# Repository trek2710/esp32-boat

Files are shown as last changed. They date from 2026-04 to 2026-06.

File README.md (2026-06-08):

# esp32-boat

A family of small, **independent, self-contained boat devices**. Each device
is one ESP32-based box that does a single job on its own — own sensors, own
display, own settings — and connects only to a companion **iOS app over BLE**.
No shared bus, no boat network required.

> **v2 (2026-06).** This reverses the original design — three ESP peers on a
> WiFi "virtual N2K bus" — which was abandoned in the pivot to independent BLE
> devices ([ADR-0016](docs/adr/0016-independent-devices-over-ble.md)). The full
> v1 design is recoverable at the `v1-wifi-bus-archive` tag; its docs are in
> [docs/archive/](docs/archive/).

## Device 1 — AIS-radar

A **Waveshare ESP32-S3-Touch-AMOLED-1.75-G** (onboard LC76G GNSS) + a **Wegmatt
dAISy 2+** AIS receiver, battery-powered:

```
   VHF antenna ─► dAISy 2+ ──UART(IO16)──► AMOLED device ──BLE──► iPhone (AisRadar app)
                                              │  - decode AIVDM
   LC76G GNSS ───────onboard──────────────────┤  - own position
                                              │  - radar on the AMOLED
                                              └  - threat colouring
```

It decodes AIS targets from the dAISy, takes own position from the LC76G (or
the phone's GPS), and draws the targets **radar-style** on its round AMOLED —
with a whole-screen threat colour (dark → green → yellow → red). The iOS app
mirrors the same radar over BLE.

**Status:** working end-to-end on the bench/phone. See
[docs/ROADMAP.md](docs/ROADMAP.md). Remaining hardware steps: solder the LC76G
`R15`/`R16` jumpers (real own GPS) and connect the VHF antenna (real targets).

## Repo layout

```
esp32-boat/
├── devices/
│   └── ais-radar/            device 1 — its own PlatformIO project
│       ├── platformio.ini
│       └── src/              main, Radar, Ble, glue
├── shared/                   salvaged, reusable across devices
│   ├── ais/                  AIVDM decode + AisTargetDecoder + target store
│   ├── display/              AMOLED panel + LVGL + TCA9554 + LC76G GPS + touch
│   └── ble/                  GATT wire contracts (AisRadarBle.h)
├── ios/                      AisRadar — SwiftUI BLE-central app
├── docs/                     CONTEXT.md (glossary), ROADMAP.md, adr/, hardware/
├── scripts/                  gen_ais_test.py, patch helpers
└── docs/archive/             v1 docs (superseded by ADR-0016)
```

## Build + flash (device)

Each device is its own PlatformIO project:

```bash
cd devices/ais-radar
pio run                                    # build
pio run -t upload --upload-port /dev/cu.usbmodemXXXX   # flash
```

The AMOLED's native USB-CDC needs the `--no-stub` + `115200` upload flags
already set in its `platformio.ini`.

## iOS app

`ios/` is the **AisRadar** SwiftUI app — a CoreBluetooth central that connects
to the `ais-radar` device, decodes its notify characteristics
([shared/ble/AisRadarBle.h](shared/ble/AisRadarBle.h)), and draws its own
radar with a tunable scale. Build:

```bash
cd ios
xcodegen generate
open AisRadar.xcodeproj      # run on a real iPhone — BLE needs hardware
```

## Bench testing

`scripts/gen_ais_test.py` generates verified Type-18 AIS sentences (correct
checksums, round-trip-decoded) placed around a centre point, labelled with the
threat colour each one triggers. Inject them via the dAISy `T` menu.

## Docs

- [docs/CONTEXT.md](docs/CONTEXT.md) — glossary / domain language.
- [docs/ROADMAP.md](docs/ROADMAP.md) — what's done + what's next.
- [docs/adr/](docs/adr/) — architecture decisions (ADR-0016 is the v2 pivot).
- [docs/hardware/ais_radar_wiring.html](docs/hardware/ais_radar_wiring.html) — device wiring + power.

## License

MIT — see [LICENSE](LICENSE).

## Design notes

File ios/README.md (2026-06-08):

# AisRadar — iOS app (v2, ADR-0016)

A SwiftUI **BLE-central** app for the `ais-radar` device. It scans for the
device, subscribes to its two notify characteristics, decodes own-ship +
AIS targets (wire contract: `../shared/ble/AisRadarBle.h`), and draws its
own north-up radar with a tunable / auto-fit scale.

This replaces the archived v1 WiFi-bus app (recoverable at tag
`v1-wifi-bus-archive-ios`).

## Build

```sh
cd ios
xcodegen generate        # regenerate AisRadar.xcodeproj (brew install xcodegen)
open AisRadar.xcodeproj  # then run on a real iPhone (BLE needs hardware)
```

`.xcodeproj` is gitignored — `project.yml` is canonical.

## Layout

- `Sources/AisRadar/BleCentral.swift` — CoreBluetooth central (scan / connect / subscribe).
- `Sources/AisRadar/RadarModel.swift` — decoded model + little-endian byte readers.
- `Sources/AisRadar/RadarView.swift` — the radar Canvas.
- `Sources/AisRadar/ContentView.swift` — radar + scale controls + status.

## Status

Connects, decodes `BleOwnShip` / `BleTarget`, draws the radar. **Pending:**
the settings write path (iOS → device), once the device exposes it.

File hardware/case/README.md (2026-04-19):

# 3D-printable enclosure

Two-part round case for the Waveshare ESP32-S3-Touch-LCD-2.1 + SN65HVD230
transceiver. Designed around the nominal dimensions of both boards — re-run
`generate_case.py` with different parameters if your hardware measures
differently.

## Files

| File | What it is |
|---|---|
| `case_body.stl` | The main bowl. Holds the transceiver at the back, the Waveshare PCB in front of it. |
| `case_bezel.stl` | Flat ring with the display window. Press-fits into the top of the body. |
| `generate_case.py` | Parametric source that produced the STLs. All dimensions are constants at the top of the file. |

## Dimensions

- Outer diameter: **Ø75 mm**
- Total height (body + bezel): **25 mm** (21 mm body + 4 mm bezel, ~2 mm overlap)
- Display window: **Ø55.9 mm** (clears the 2.1" / Ø53.4 mm active area)
- USB-C slot: 12 × 6 mm on the +X side wall, centred at z ≈ 12.9 mm
- NMEA 2000 cable exit: Ø6 mm hole through the -X side wall, in the transceiver bay

The inside has an **internal shelf** that the PCB rests on, so the display
sits flush with the bezel opening.

## Print settings

- **Material**: PETG (marine environment, UV & humidity) or PLA for bench use.
- **Orientation**:
  - *Body* — open end up, back wall on the build plate. No supports needed;
    slicers will bridge the internal shelf and side holes fine at ≤6 mm.
  - *Bezel* — flat side down. No supports.
- **Layer height**: 0.2 mm. 0.16 mm if you want the tick marks around the
  display to look nice.
- **Walls**: 3 perimeters (≥1.2 mm) — the wall-min is 2.5 mm everywhere so
  even default settings give you solid walls.
- **Infill**: 20 % is plenty; the case is tiny.
- **Support**: only needed if your printer bridges the horizontal USB-C slot
  and cable hole badly. Try without first.

## Assembly

1. Drop the **SN65HVD230** breakout into the Ø60 mm transceiver bay at the
   back. Secure with a dab of hot glue or double-sided tape (there's a
   generous 6 mm of depth to play with).
2. Route the CAN twisted pair + 12 V / GND through the **Ø6 mm cable exit
   hole** in the side wall. A small rubber grommet or a dab of silicone
   keeps water out.
3. Insert the **Waveshare ESP32-S3-Touch-LCD-2.1** into the PCB cavity,
   display facing up. The back of the PCB rests on the internal shelf; the
   cavity is 1.5 mm oversize so the board slides in with a little slop.
4. Verify **USB-C** on the Waveshare board lines up with the side slot.
   If it doesn't, rotate the PCB 90°/180° — the USB connector's exact
   clock position is defined by how you orient the PCB inside the round
   cavity. (If the slot is off-axis when the PCB is aligned the way you
   want for the screen, re-run `generate_case.py` with `USB_CUTOUT_Z`
   adjusted.)
5. Press the **bezel** onto the top. The skirt (Ø66.2 mm) slides 2 mm into
   the top rim (Ø66.5 mm) — light interference fit. Push firmly until the
   bezel flat meets the top of the body.

If you ever need to get back in, a thin knife or guitar pick in the seam
between bezel and body will pop it off without damage.

## Regenerating the STLs

You need `manifold3d` and `numpy-stl`. On macOS with Homebrew Python:

```
pip3 install --break-system-packages manifold3d numpy-stl
```

Then:

```
cd hardware/case
python3 generate_case.py
```

That rewrites `case_body.stl` and `case_bezel.stl` next to the script.
Edit the constants at the top of the `.py` file to change dimensions.

## TODO for a future revision

- Mounting tabs or magnets for attaching to a bulkhead.
- O-ring groove in the bezel-body seam for full IP65.
- Recess on the back for a wall-mount screw or VESA pattern.
- Light pipe / gasket around the display edge for a cleaner look.

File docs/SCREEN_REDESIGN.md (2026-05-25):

# Screen redesign — round 85

Round-85 grilling pinned the page layout for the three displays. This
file is the implementation brief; the protocol decisions it depends on
are in [ADR-0013](adr/0013-settings-control-plane.md).

## LCD page set (both `lcd-gps` and `lcd-2.1` identical)

Four pages, swipe-cycled left/right:

| # | Page | What it shows |
|---|---|---|
| 1 | **Main** | Compass overview (existing) |
| 2 | **AIS** | Compass overlay (if own-GPS fix) **or** scrollable list (if no fix) |
| 3 | **PGN** | 19-tile honeycomb (existing) |
| 4 | **Comm** | Two columns — Network (left) / Hardware (right) |

Removed entirely: the standalone **Wind** overview page (Main covers
it), the **Sim** channel-mask page (moved to iOS), the **Settings**
no-go-zone page (moved to iOS).

### Main page — only change

Flip the apparent-wind cone (`main_pg.twd_arrow`, the long yellow
slim cone) so the **thick end points outward**. Today it points
inward (cone narrows toward the rim). Same colour, same length, same
binding to `s.awa`.

Code location: `src/Ui.cpp` around `buildMainPage()` line ~1265 where
`lv_meter_add_needle_img` is called for the cone, plus the static
`needle` image asset definition. Either flip the image data
horizontally or invert the value-to-angle mapping; the latter is
fewer changes.

### AIS page — new on the LCDs

Two layouts, chosen at refresh time by checking
`BoatState::hasGpsFix()`:

**With GPS fix — compass overlay.** Same outer-ring compass as Main.
For every AIS target passing the filters (see ADR-0013 keys
`ais.range_nm` / `ais.hide_anchored` / `ais.stale_s`):

- Compute bearing-from-own-ship and range using
  `navmath::greatCircleBearing` and `navmath::greatCircleDistance`.
- Draw a small triangle on the compass at the bearing, with a stroke
  thickness proportional to `1 / range` (closer = thicker).
- Above the boat-speed centre group, add a 3-line "nearest 3" panel
  with NAME · RNG · BRG.

**Without GPS fix — list.** Plain scrollable list (LVGL `lv_list` or
a tall flex column). Columns: NAME (left, ellipsised at 12 chars),
TYPE (3-letter, like the converter's), SOG, CPA-or-`—`. Sort by
last_seen descending so freshly-heard targets appear at the top.
Range/bearing columns are blank because we have no own-ship position.

### PGN page — unchanged

Keep the existing 19-tile honeycomb. The grey reserved slots
(ENG-T / OIL-T / HEEL / PITCH / ROT / RUD) stay as visual placeholders
for future hardware.

### Comm page — two-column rewrite

Mockup:

```
WiFi : STA  ap=lcd-2.1     GPS  : 3D fix  8 sats  age 2s
IP   : 192.168.4.2         Power: 4.18V batt  USB 5.04V (chrg)
RSSI : -42 dBm  ch 1       Up   : 1h 23m 47s
peers: 2
```

Column widths roughly equal; left column = `Network`, right column =
`Hardware`. Drops the legacy BLE notify counters that survive in
`comm_pg` today. TX's current `Primary` page content (GPS, AXP2101,
uptime) folds in here; TX no longer has a standalone Primary page.

LVGL: implement once in `src/Ui.cpp`'s `buildCommPage` /
`refreshComm`, then port the equivalent (Arduino_GFX-rendered) onto
TX in `src_tx/main.cpp`.

### Page count

RX is currently `kNumPages = 6`. New value: `4` (and the `#ifdef`
that switched between 5 and 6 in the BLE/WiFi backends becomes
unconditional 4).

TX is currently `kNumPages = 5`. New value: `4`.

The swipe state machine in both envs is already page-count agnostic
(`(current_page + step + kNumPages) % kNumPages`).

## Converter screen — layout unchanged

Apply only the three AIS filters from the global settings snapshot
(ADR-0013):

- `ais.range_nm`        — hide targets farther than N NM (with default 12 NM, but the converter currently defaults its list at infinite range; settings override at runtime)
- `ais.hide_anchored`   — drop NavStatus ∈ {1, 5, 6} when true
- `ais.stale_s`         — drop targets whose `last_seen` is older than N seconds

These filters short-circuit the existing 4-row list builder in
`src_converter/Ui.cpp`'s `refreshTargets()` (a single `passes_filters`
helper called before each row is emitted).

No graphical changes to the converter UI: boat icon, DAISY badge,
ship-type colour palette, header, footer all stay as they are.

## Settings UI — lives on iOS

See [IOS_APP.md](IOS_APP.md). No Settings page on the LCDs in v1.

## Implementation order

Suggested punch-list, smallest blocks first:

1. **AWA cone flip** on Main — single-file change, instantly visible.
   Bench-test by watching the cone rotate as the simulator wind angle
   moves; thick end should now poke through the outer ring's bow zone.
2. **Comm page two-column rewrite** on RX. New layout, new fields.
   Don't yet drop the BLE counters (they go away when the BLE env
   does, which is independent of this work).
3. **Drop Settings + Wind + Sim pages** from RX. Update `kNumPages`,
   `pages[]` index array, `case n` blocks. Verify swipe still cycles
   correctly.
4. **AIS page on RX** (list layout first, since GPS isn't yet wired —
   step-5 hardware is still pending). Use the AisTargetStore as the
   source; the store doesn't currently live on RX — fan-out from the
   converter's replay (ADR-0012) populates it via the existing PGN
   dispatch path. Verify by triggering a sim AIS injection from the
   converter and watching it land on RX's list.
5. **AIS page compass overlay** — gated on `hasGpsFix()`. Implements
   the GPS path; works on the bench by setting a sim lat/lon on RX so
   `hasGpsFix()` returns true.
6. **Converter AIS filters.** Wire the three filter keys through the
   `refreshTargets` short-circuit. Defaults bake in if no settings
   snapshot has arrived yet.
7. **TX pages, mirror of RX.** Port the four pages onto Arduino_GFX
   for TX. Same content, different renderer.

Steps 1–6 are doable independently. Step 7 depends on the others
landing first so the TX port has a stable target to copy.

## What this is not

- This brief does not implement ADR-0013 (HTTP server, heartbeat
  snapshot, NVS cache). Those are prerequisites for the Settings UI
  to *do anything*, but the page-layout work in steps 1–7 above is
  independent of them — the no-go-zone read happens whether or not
  the snapshot mechanism is in place (fallback to compile-time
  default).
- It does not touch the BLE envs. `[env:nmea2k_tx]` and
  `[env:waveshare_esp32s3_touch_lcd_21_ble]` stay as-is; only the
  `_wifi` envs evolve.

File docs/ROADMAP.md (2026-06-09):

# Roadmap

> **v2 pivot (2026-06-07, ADR-0016):** the project abandoned the WiFi
> "virtual bus" / NMEA 2000 mirror entirely and became a family of
> **independent, self-contained devices** that link to an iOS companion
> over BLE. **Everything below the "v2 — independent devices" section is
> v1 history**, kept for reference and recoverable at the
> `v1-wifi-bus-archive` tag, but no longer the plan.

## v2 — independent devices over BLE ← CURRENT DIRECTION

**Goal: self-contained ESP boxes, each doing one boat job standalone,
each linked only to an iOS companion over BLE.** No shared bus, no boat
network required. Architecture: [ADR-0016](adr/0016-independent-devices-over-ble.md);
vocabulary: [CONTEXT.md](CONTEXT.md).

### Device 1 — AIS-radar device (milestone 1)

The ESP32-S3-Touch-AMOLED-1.75-G (onboard LC76G GPS) + a Daisy 2+ AIS
receiver, drawing AIS targets radar-style on its own AMOLED when it has
a fix, with a BLE link to a fresh iOS app. Self-powered.

**Salvage (keep):** AMOLED display/touch/PMIC bring-up, LC76G GPS
driver, AIS AIVDM decode (now `shared/ais/`), radar geometry/trig.
**Re-target:** the radar is an LVGL→LVGL port — both boards run LVGL
8.3.11 (the AMOLED uses Arduino_GFX only as LVGL's flush backend), so
re-aim the canvas + screen size, not a graphics-API rewrite. iOS app →
fresh, BLE central. **Drop:** WiFi bus, role election, HTTP settings.

- [x] **0. Repo reset — DONE.** Tag `v1-wifi-bus-archive`; `devices/` +
      `shared/` layout. Salvaged (all hardware-verified on the AMOLED
      board): `shared/ais/` (AIVDM decode + de-N2K'd, lat/lon-fixing
      `AisTargetDecoder`), `shared/display/` (`AmoledDisplay` panel+LVGL,
      `Tca9554` expander, `Lc76gGps` UART NMEA — dead I2C path dropped,
      streams once R15/R16 soldered, `Touch` CST9217 via SensorLib),
      `shared/ble/BoatBle.h`. `devices/ais-radar/` builds + runs:
      display + touch + GPS + AIS all live on the board. Deleted `src/`
      `src_tx/` `src_converter/` `include/` + the root `platformio.ini`
      (recoverable at the tag); CI now builds the device.
- [ ] **1. AMOLED + GPS bring-up** — display/touch up on the new tree;
      LC76G UART jumpers (R15/R16) soldered; own position acquired.
- [x] **2. Daisy AIS in — DONE.** Wiring:
      [ais_radar_wiring](../hardware/ais_radar_wiring.html) (3 wires off
      header H2 — `IO16`←TXD, `3V3`→VCC@3.3V, `GND`; no step-up, no 9V).
      Firmware reads the Daisy on `Serial2`/`IO16` @ 38400, assembles
      lines, and feeds the on-device `AisTargetDecoder`. Hardware-verified:
      the Daisy keep-alive heartbeat decodes clean (valid checksum) on the
      AMOLED. (A position-type sentence or a real antenna is needed before
      a vessel shows — the keep-alive is AIS type 15.)
- [x] **3. On-device radar — DONE.** North-up LVGL PPI on the AMOLED
      (`Radar.cpp`): own ship centred, AIS targets at range/bearing with
      5-min COG projection sticks, MMSI labels, range rings, auto-fit
      range, stale-contact dimming. Own position pinned to a bench
      coord until the LC76G is soldered; targets expire after 10 s
      (`evictStale(10000)`). Verified Type-18 test sentences:
      `scripts/gen_ais_test.py`. (Touch zoom/pan is a later polish.)
- [~] **4. BLE link** — device side DONE: advertises as `ais-radar`
      (`shared/ble/AisRadarBle.h` wire contract; `devices/ais-radar/Ble.cpp`
      NimBLE peripheral), notifies own-ship (`BleOwnShip`) + each AIS target
      (`BleTarget`) once per second to a connected central. **Pending:** the
      iOS-→-device settings write characteristic + NVS persistence.
- [x] **5. Fresh iOS app — DONE.** `AisRadar` SwiftUI BLE-central app:
      scans for `ais-radar`, subscribes to both characteristics, decodes
      `BleOwnShip`/`BleTarget`, draws its own north-up radar with auto-fit
      + a manual range slider. Replaces the archived v1 WiFi app under
      `ios/`. **Confirmed live on the iPhone** — targets sent via the
      dAISy show up on the phone radar. (Settings write path iOS → device
      still pending.)

**Acceptance:** powered by its own battery/powerbank, no boat
connection, the device shows my GPS position with live AIS targets
around it radar-style; the iOS app mirrors it and can change its
settings.

### Later devices / capabilities (not scheduled)

- Comfort device (IMU sea-state → comfort index) — design in
  [ADR-0014](adr/0014-comfort-page-sea-state.md), **mechanism needs BLE
  rework** (it predates this pivot).
- Optional per-device **N2K bridging** — a device gains an SN65HVD230 to
  emit/read PGNs. The v1 encoders + ADR-0005 are kept dormant for this.
- Fate of the RX 2.1" round display and the C6 converter as future
  devices.
- **AIS-radar polish (deferred):** radar **range/scale tuning** from iOS
  (keep or replace autoscale — decide once the app is live); a **C-MAP map
  overlay** read from the onboard microSD (`cmap/` folder) — an *overlay
  on the radar only*, explicitly **not** a mapping engine; and the AMOLED
  **swipe/touch** interaction (undecided — possibly just swipe).
  **SD recon done** (firmware `listSdCard()`): SD is **SD_MMC** on
  `CLK=2 / CMD=1 / DATA=3` (1-bit). exFAT doesn't mount on stock
  Arduino-ESP32 → card reformatted **FAT32** (60 GB), now mounts fine.
  The charts are **CM93 v2/v3** (`cm93_World2014/` → numeric cell dirs ×
  `A`–`G` scale bands × `.INF`), **not** encrypted C-MAP — so it's
  decodable (OpenCPN's `cm93` plugin is the reference implementation), but
  the overlay is a substantial **vector decode + render** job (decode the
  cell geometry for the own-ship area at an appropriate scale band → draw
  coastlines/land as a radar overlay). A real feature, not a quick add.
- **Weather/chart "mapping" device (idea, future):** a separate device that
  shows C-MAP base charts + **GRIB** weather overlays, reading both from the
  same microSD layout (exFAT; `cmap/` + a GRIB file already on the card).
  Distinct from the AIS-radar device's overlay-only use of the card.

---

# v1 history (archived — WiFi virtual bus, superseded by ADR-0016)

Everything below predates the v2 pivot. Recoverable at
`v1-wifi-bus-archive`.

## Sea-trial v1 — standalone AIS + GPS pod (SUPERSEDED by ADR-0016)

**Goal: a self-powered box that shows real AIS + iPhone-GPS position on
the RX and iOS, on a boat with no instruments and no NMEA 2000.** The
test boat has no N2K backbone and no wind instrument, so this release
drops the "mirror a real bus" premise entirely. Rationale + the four
scoping decisions: [ADR-0015](adr/0015-standalone-pod-first.md).
"Standalone pod" deployment mode: [CONTEXT.md](CONTEXT.md).

**In scope:** iPhone GPS (foreground) for own position; real AIS via the
Daisy 2+ → converter → virtual bus; the RX radar + AIS list; the iOS map
+ list. Self-powered (LCD batteries, converter on a powerbank).

**Deferred:** comfort/IMU (ADR-0014), a dedicated GPS module, wind /
depth / heading sensors, the N2K **gateway mode**.

**Priorities (do roughly in order):**

- [ ] **1. Simulator master switch** — one `sim.master` setting gates
      *all* sim publishing (RX sim + converter AIS sim). Bench = on
      (today's behaviour); trial = one tap off so only real sources
      flow. Prevents `sim.gps` from pegging own-ship in Copenhagen.
- [ ] **2. Heading honesty** — there is no magnetometer; own-ship is
      COG-only (valid when moving). Ensure no display implies a magnetic
      bow heading; label it COG, not HDG.
- [ ] **3. Field power-on autonomy** — the three boards + iPhone form
      the virtual bus on battery alone, no laptop: RX comes up as AP
      reliably, converter + iPhone join, iOS app foreground.
- [ ] **4. Real AIS bring-up** — wire the Daisy 2+ to the converter
      (`docs/hardware/hardware_guide.html`), powerbank it, verify real
      targets travel Daisy → converter → bus → RX radar + iOS.
- [ ] **5. Real-position verification** — `sim.master` off, confirm the
      RX radar + iOS map centre on the live iPhone position with real
      AIS targets around it.

**Acceptance:** underway on the real boat, battery-powered, no laptop —
the RX radar and the iOS map show my real position with live AIS targets
around me for a full short sail.

## v0 — scaffold (this repo as-is, 2026-04-19)

- [x] PlatformIO project structure
- [x] NMEA 2000 + LVGL dependencies pinned
- [x] Placeholder instrument screens
- [x] CI builds the firmware on every push
- [ ] Flash on real hardware when it arrives
- [ ] Confirm display pin assignments against the Waveshare schematic
- [ ] Confirm CAN TX/RX pin choice against the broken-out header

## v1 — instruments only (single board, target: hardware in hand + 2 weekends)

**Goal: a working cockpit instrument that shows live NMEA 2000 data.**

- [x] Display driver stable (no tearing, touch responsive)
- [x] PGN 129025 / 129026 / 129029 → GPS position + SOG + COG
- [x] PGN 130306 → wind (apparent + true)
- [x] PGN 128267 + 130316 → depth + water temperature
- [x] PGN 127250 + 128259 → heading + speed through water
- [ ] PGN 129038 / 129039 → AIS position reports → scrolling target list
- [x] Swipe / tap to page between screens
- [ ] Brightness control (long-press a corner)
- [ ] Persist last screen across reboots
- [ ] Mechanical install in the cockpit
- [ ] Retire the bench harness after 1 weekend of sea trial without crashes

## v1.5 — wireless split (in progress)

**Goal: move from one all-in-one board to two BLE-bridged boards.**

The receiver stays in the cockpit; a new transmitter board lives near
the NMEA 2000 backbone (wiring locker / engine bay) and forwards data
over BLE GATT. The SN65HVD230 transceiver moves off the RX onto the
new TX board. The simulator follows it, so sim and real PGNs flow
through the same wireless link.

- [x] **Step 1a** — PIO `[env:nmea2k_tx]`, src_tx scaffold, serial-only
      Hello on the Waveshare ESP32-S3-Touch-AMOLED-1.75-G
- [x] **Step 1b** — AXP2101 PMIC init via XPowersLib (SDA=GPIO15 /
      SCL=GPIO14), full I²C bus census, live battery / VBUS telemetry
- [x] **Step 1c** — SH8601 AMOLED brought up over QSPI via Arduino_GFX
      (CO5300 driver, which is pin-compatible), LVGL 8.3.11 bound via
      a flush callback into a 466×466 PSRAM buffer, centred
      "Hello, transmitter" label rendering
- [x] **Step 2** — `include/BoatBle.h` shared wire protocol —
      service UUID + 5 notify characteristics (Wind / GPS / Heading /
      Depth-Temp / Attitude) + 1 command characteristic. All PDUs
      packed, fit inside the default 23-byte ATT MTU, valid-mask
      bitmap per channel so missing fields are explicit instead of
      sentinel-encoded.
- [x] **Step 3** — TX runs the simulator + acts as BLE peripheral
      (`esp32-boat-tx`), notifying boat-state on the five channels
      at NMEA-2000 spec cadences. Subscribed counts visible on the
      TX's Communication page; verified subscribable from nRF Connect.
- [x] **Step 4** — RX-side BLE central scans for the service UUID,
      auto-connects to the first `esp32-boat-tx` it sees, subscribes
      to all five characteristics, parses PDUs into existing BoatState
      setters. On disconnect `BoatState::invalidateLiveData()` blanks
      all live fields to NaN so the UI renders "—" instead of stale
      values. Status getters expose link state / peer MAC / RSSI /
      per-channel notify counters, shown on a new RX Communication
      page (page 6 under `DATA_SOURCE_BLE`). New PIO env
      `[env:waveshare_esp32s3_touch_lcd_21_ble]` gates the central
      backend on `-DDATA_SOURCE_BLE=1`.
- [ ] **Step 5** — TX wired to NMEA 2000 bus through SN65HVD230,
      NMEA2000 + NMEA2000_esp32_twai libraries forward real PGNs
      onto the same notify path. **Hardware-blocked** until the
      transceiver is wired and the bus has a live source. See
      [OPENPLOTTER_NMEA2000.md](OPENPLOTTER_NMEA2000.md) for the
      OpenPlotter-as-source bring-up path.
- [ ] **Step 6** — RX → TX command channel: page-3 sim toggles fire
      writes back to the TX. Wire format reserved in `BoatBle.h`,
      `CommandCallbacks::onWrite` in `src_tx/main.cpp` logs bytes
      but doesn't decode yet. Deferred until step 5 lands.
- [x] **Step 7** — TX status display on the AMOLED, five pages
      (Primary, Simulator, PGN, Settings, Communication) with
      BLE link state, per-channel notify rate, AXP2101 telemetry,
      uptime. Read-only — Sim toggles surface state but don't yet
      flip mask (waits on step 6).
- [x] **Step 7b** — CST9217 capacitive touch via lewisxhe/SensorLib;
      swipe-left / swipe-right gestures change pages. Reset line
      driven via TCA9554 EXIO6 (CST9217 RST isn't on a direct GPIO
      on this board). SensorLib upstream has a `getPoint(0)` bounds
      bug that spams the log on every touch; patched in-place at
      build time by `scripts/patch_sensorlib.py` (idempotent,
      self-healing across libdeps wipes).
- [—] **Step 8** — Real GPS via the AMOLED-1.75-G's onboard LC76G.
      **Dead-end on this board variant.** I²C path against 0x50
      ACKs writes but NACKs reads (Quectel's app note is paid).
      UART path via GPIO17/18 stays silent — the R15/R16 0 Ω
      jumpers between LC76G TX/RX and the ESP32 pins aren't
      populated. Driver code is parked in place: I²C poll
      auto-disables itself after N consecutive NACKs, UART drain
      runs every loop iteration so soldering R15/R16 lights it up
      with no code change. Will revisit if an external GPS
      becomes attractive.
- [x] **Step 9** — TX UI polish: titles 28pt, rows 24pt, Sim page
      six category-coloured pills (display-only — interactive
      toggling lives on step 6), PGN page rows tinted by category
      pastel to mirror the RX honeycomb's colour-coding. A
      tap-to-toggle experiment was tried and reverted — the tap
      detection added a 300 ms lockout that interfered with swipes,
      so toggle UX waits for step 6.

## v1.5b — screen cleanup (round 85, **shipped**)

**Goal: unified 4-page LCD layout, AIS on the LCDs, drop the
half-finished pages.** Brief in [SCREEN_REDESIGN.md](SCREEN_REDESIGN.md).

- [x] **Step 1** — Flip the Main-page AWA cone so the thick end
      points outward instead of inward.
- [x] **Step 2** — Comm page rewritten as two columns (Network /
      Hardware), absorbing TX's previous Primary content.
- [x] **Step 3** — Settings / Wind-overview / Simulator pages dropped
      from RX. `kNumPages = 4`, swipe order: Main / AIS / PGN / Comm.
- [x] **Step 4** — AIS list page on RX (sorted by last-seen; renders
      from `BoatState::aisSnapshot()`).
- [x] **Step 5** — GPS-aware AIS list: when own-GPS fix is present,
      list sorts by range ascending and populates RNG / BRG columns
      via inline haversine. (Full canvas-based compass overlay
      deferred — the list path delivers the user-meaningful info.)
- [x] **Step 6** — Converter AIS filters (`ais.range_nm` /
      `ais.hide_anchored` / `ais.stale_s`) wired into
      `refreshTargets()`.
- [x] **Step 7** — TX page set converged to 4 pages (Main / AIS /
      PGN / Comm). TX now consumes incoming bus PGNs into a local
      `BoatState` (round-85 step-7-fix) and renders real values; AIS
      list mirrors RX's; Comm page is two-column.

## v1.6 — iOS companion app + settings control plane (round 85, **mostly shipped**)

**Goal: native SwiftUI app that joins the bus as a full peer and
becomes the canonical settings UI.** Design in
[IOS_APP.md](IOS_APP.md); settings control plane in
[ADR-0013](adr/0013-settings-control-plane.md).

- [x] **Step 1** — Settings control plane on the firmware: AP-side
      `WebServer` on port 80 with `GET`/`POST /settings`, heartbeat
      snapshot fan-out, NVS persistence on every ESP. Consumers wired
      for: `nav.no_go_deg` (RX Main), `sim.*` channel toggles (RX
      simulator), `ais.hide_anchored` + `ais.stale_s` (converter
      filter), `ui.brightness` (converter backlight).
- [x] **Step 2** — Xcode project (`../esp32-boat-ios/`) scaffolded
      with xcodegen, 4-tab SwiftUI shell, UDP listener + heartbeat
      publisher + PGN dispatcher all wired. Captive-portal stub on the
      AP (DNS hairpin + iOS probe URLs) so iOS classifies
      `_wifi_nmea2k` as a real network and doesn't fall back to
      cellular.
- [x] **Step 3** — Boat tab (live instrument grid + TWA/TWS/VMG
      derived locally + per-channel staleness sweep blanks cells when
      a channel goes silent).
- [x] **Step 4** — AIS tab (placeholder; populated by converter's
      AIS-sim replay over the bus). Plus: iPhone GPS publisher
      (PGN 129025, **opt-in default off**, toggle on Settings tab,
      stored in UserDefaults). Plus: Boat-tab Position cell with
      cross-check of bus-published GPS against iPhone GPS — bold
      orange when delta > 30 m.
- [x] **Step 5** — Own-ship SOG/COG available everywhere via local
      derivation from successive PGN 129025 fixes (firmware `BoatState`
      round 56; iOS `PgnDispatch.handleGps`). Per-target SOG/COG
      already rides PGN 129039 from the converter. A 129026 wire-up
      across peers was **declined**: it would contradict the round-56
      "derive, don't trust a sensor-supplied COG/SOG" rule (RX already
      ignores 129026) and add nothing the map needs.
- [ ] **Step 6** — AIS map view: SwiftUI Canvas with own ship +
      AIS targets + 5-minute forward-projection arrows. **Unblocked**
      — all inputs (own-ship position/heading/SOG/COG, per-target
      position/SOG/COG) are on the bus today. Plus Diagnostics tab
      polish (PGN-rate honeycomb, raw-log drawer).

## v1.7 — future polish (not yet planned)

- Real boat connectivity: SN65HVD230 to a live N2K backbone (v1.5
  step 5, hardware-blocked; see
  [OPENPLOTTER_NMEA2000.md](OPENPLOTTER_NMEA2000.md)).
- LC76G GPS via the AMOLED-1.75-G's onboard GNSS — requires
  soldering R15/R16 jumpers.
- TX compass widget on Main (currently text grid; RX has the full
  LVGL compass).
- iOS distribution signing ($99/yr Apple Developer Program) — the
  free-tier signing requires online cert verification at each launch.
- Wi-Fi role-priority surfacing in heartbeat (`has_transceiver`
  bool, task #45) — meaningful once multiple transceiver peers exist
  on the same physical N2K backbone.

## v2 — waypoint navigation

- [ ] Waypoint list (load/save JSON on the microSD card)
- [ ] "Go to" screen: bearing + distance + cross-track error to active WP
- [ ] Receive active waypoint from a chartplotter via PGN 129284 if present
- [ ] Send local waypoints onto the bus (PGN 129285) so they show on the chartplotter

## v3 — map

- [ ] Pre-render OSM tiles to microSD offline
- [ ] Tile cache + pan/zoom on the round display
- [ ] Boat icon heading-up, lat/lon from GPS
- [ ] AIS targets as icons on the map, not just a list

## v4 — polish

- [ ] OTA updates over WiFi (marina / phone hotspot)
- [ ] Anchor watch: alarm if the boat drifts > X metres from a dropped pin
- [ ] Trip log: miles, hours, max SOG, max wind — exported as CSV on the SD

## v5 — comfort / seakeeping (design only, not scheduled)

**Goal: a comfort page driven by the boats' idle QMI8658 IMUs.**
Architecture pinned in [ADR-0014](adr/0014-comfort-page-sea-state.md)
and the "Comfort / sea state" glossary in [CONTEXT.md](CONTEXT.md);
no implementation yet. In short: reconstruct a (boat-distorted) sea
state from each LCD's IMU, correct it with a learned per-boat model
held in the iOS app, and show a steepness-based comfort index — with
the active source (cockpit-measured / locker-measured / manual / GFS
forecast) user-selectable. See the ADR's "Open questions" for what's
still undecided.

## Non-goals

- Being a replacement for a full MFD. We are a single-purpose instrument.
- Writing **NMEA 2000 control commands** onto the boat bus (autopilot,
  engine, etc.). The bus-side stays read-only. The BLE command channel
  (RX → TX) is internal — it only configures the TX (sim toggles, future
  brightness, etc.), it never reaches the boat's N2K backbone.
- ~~Supporting boats without an NMEA 2000 backbone.~~ **Reversed
  (2026-05-26, ADR-0015):** the first sea-trial boat has no N2K backbone,
  so the **standalone pod** deployment mode (iPhone GPS + Daisy AIS + IMU,
  no boat connection) is now a first-class target. The N2K **gateway
  mode** remains supported for boats that do have a backbone.

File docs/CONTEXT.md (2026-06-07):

# esp32-boat — glossary

This project is a family of **independent, self-contained devices**. Each
device is one ESP-based box that does a single boat-related job on its
own — own sensors, own display, own persisted settings — and can
optionally be observed and configured by an **iOS companion** over
Bluetooth Low Energy. There is no shared bus and no coordination between
devices; each is an island.

This reverses the v1 design (a WiFi "virtual bus" mirroring a boat's
NMEA 2000 network). The pivot and what it retires: **ADR-0016**. The
retired bus vocabulary is listed at the bottom so old code/commit
references still resolve.

## Language

**Device**:
A self-contained ESP box that performs one boat-related job standalone.
It owns its inputs (e.g. GPS, AIS), renders its own result on its own
display, and persists its own **device-local settings** in NVS so it
works with no phone present. A device may optionally connect to the
**iOS companion** over BLE. Devices do **not** talk to each other.
_Avoid_: "peer" (there is no bus to be a peer on), "node", "board" when
you mean the logical device (a device is one board today, but the term
is about its role, not its silicon).

**AIS-radar device**:
The first device. A Waveshare ESP32-S3-Touch-AMOLED-1.75-G (onboard
LC76G GNSS) wired to a Wegmatt Daisy 2+ AIS receiver. It decodes AIS
targets from the Daisy's serial feed, takes own position from the
LC76G, and draws the targets **radar-style** (own ship centred, targets
by range/bearing) on its AMOLED — when it has a GPS fix. Self-powered,
needs no boat connection.
_Avoid_: "converter" (the v1 C6 converter bridged AIS→N2K; this device
shows AIS, it doesn't bridge), "RX/TX" (those were bus roles).

**iOS companion**:
The iOS app, acting as a BLE **central** that connects to a device
(the device is the **peripheral**). It observes the device's live data
(AIS targets, own GPS, status) and is the **only** way to change a
device's settings. One companion observes one device at a time; pairing
multiple devices is a future concern.
_Avoid_: "iOS peer" / "iOS-app peer" (bus-era term), "hub" in a
networking sense (it is a viewer + the settings writer, not a relay).

**Device-local settings**:
A device's configuration (e.g. radar range, AIS filters, brightness),
stored in the device's NVS. The device runs on its stored settings
standalone and ships with sane defaults, so it works out of the box with
no phone ever paired. Settings can be **changed only from the iOS
companion** over BLE — there is exactly one writer, so no sync conflict,
and the device needs no on-screen settings UI (its touchscreen is for
radar interaction only).
_Avoid_: "control plane" (the v1 HTTP-on-AP mechanism is gone),
"settings snapshot" (no heartbeat carries it).

**N2K bridging** (future, per-device):
Any device *may* later gain an SN65HVD230 transceiver and emit its data
onto a real NMEA 2000 backbone — and read from it where it makes sense.
This is an optional add-on to a given device, not the system's purpose.
The v1 NMEA 0183-AIS → N2K encoders and the strict-`src` mirror rule
(ADR-0005) are kept dormant as reference for when this is wanted.
_Avoid_: treating N2K as the target (it is no longer); "transceiver
peer" (bus-era term).

## Comfort / sea state (planned feature)

Vocabulary for a planned **comfort** device/page. Pinned before
implementation. **Note:** the original design (ADR-0014) assumed the v1
WiFi bus and an iOS-republish step that no longer exist; under the
device model a comfort capability is just another self-contained device
(or a page on one) that BLEs to the companion. The *terms* below stand;
the *mechanism* in ADR-0014 needs reworking for BLE.

**Sea state**:
The wave field around the boat, expressed as a **wave height** + a
**wave period**. No sensor here measures it directly, so a sea state is
always an *estimate*, a *manual observation*, or a *forecast* — never
ground truth. Carries the two numbers only; the felt result is the
**comfort index**.

**Comfort index**:
The user-facing output: a band (calm / moderate / rough / dangerous)
derived from a sea state's *steepness* — wave height against wavelength,
wavelength from the period (deep water: L ≈ 1.56·T²). The "wave height
vs period" relationship is the point: the same height is comfortable at
long period and dangerous at short period.
_Avoid_: "comfort ratio" (Brewer's static hull constant — different
thing).

**Boat-response model**:
The learned filter relating the true sea state to the motion an IMU
actually feels. Under the device model it would live in the iOS
companion (per boat) and the device would apply or receive it over BLE
— not "republish onto a bus" as ADR-0014 originally said.

## Retired vocabulary (v1 WiFi-bus era — see ADR-0016)

These describe the abandoned shared-bus architecture. Listed so old
commits, code comments, and ADRs 0001–0015 still resolve. **None
describe current behaviour.**

- **Virtual bus** — the WiFi distribution of N2K-style PGN packets.
  Gone: devices are islands, no shared transport.
- **AP / role election / elected writer** — the dynamic WiFi access-
  point + priority handoff (ADR-0009/0010). Gone: no multi-peer network.
- **Peer / off-bus peer / transceiver peer** — members of the virtual
  bus. Gone: replaced by **device** (+ future per-device **N2K
  bridging**).
- **Mirror direction / virtual-to-real direction** — the v1 real-N2K ↔
  virtual-bus forwarding (ADR-0005). Dormant: relevant again only under
  future **N2K bridging**.
- **Control plane / settings snapshot** — HTTP-on-AP settings write +
  heartbeat-embedded settings fan-out (ADR-0013). Gone: replaced by
  **device-local settings** written over BLE.
- **AIS replay** — periodic re-emit of the AIS cache onto the bus for
  late joiners (ADR-0012). Reworked: the iOS companion reads the
  device's current AIS target store on BLE connect instead.
- **Standalone pod / gateway mode** — the ADR-0015 deployment split.
  Subsumed: "standalone" is now the whole model (every device is
  standalone); "gateway" is the future per-device **N2K bridging**.

## Flagged ambiguities (historical)

- "bus" meant both the physical N2K backbone and the WiFi side —
  resolved in v1 (virtual vs real). Now moot: there is no WiFi bus.
- "Bridge ESP" / "allow-list" / "proxy-write" / "multicast group" —
  all retired during v1 (ADR-0010/0011/0012).
- The entire v1 bus model is retired by ADR-0016; see the list above.

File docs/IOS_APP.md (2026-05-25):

# iOS companion app — design brief + status

This is the spec for the **iOS app**, a SwiftUI sub-project that joins
the virtual N2K bus as a full peer and serves as the canonical
settings UI for the boat instruments. The repo lives at
`../esp32-boat-ios/` (sibling to the firmware repo).

## Status (round 85, 2026-05-25)

**Shipped (v1.6 step 2–4):** xcodegen project, 4-tab SwiftUI shell, UDP
listener, heartbeat publisher with `kind:'ios-app'`/priority 80,
settings POST/GET against the AP's HTTP server, AIS list, per-channel
staleness sweep, derived TWA/TWS/VMG, iPhone GPS publisher (opt-in,
default off), Position cross-check with bold-orange warning at > 30 m
delta vs bus GPS, SOG/COG derived locally from GPS position deltas.

**Pending (v1.6 step 6):** AIS map view (own ship + targets +
5-minute forward-projection arrows), Diagnostics tab polish
(PGN-rate honeycomb, raw-log drawer). Map inputs are all on the
bus already — a 129026 wire-up was declined in favour of local
SOG/COG derivation (see ROADMAP v1.6 step 5).

## Role on the bus

The iOS app is a **full peer** on the virtual N2K bus, identical in
protocol shape to the three ESP peers (`lcd-gps`, `lcd-2.1`,
`nmea-converter`):

| Property | Value |
|---|---|
| `kBoardPeerName` | `ios-app` |
| `kBoardKindName` | `ios-app` |
| `kBoardPriority` | 80 (lower than TX=100; never becomes AP) |
| Transport | WiFi STA, joins `_wifi_nmea2k` with WPA2-PSK |
| Heartbeat | PGN 65500, 5-second cadence, same JSON shape |
| Reads | Every instrument PGN — full mirror of `BoatState` |
| Writes | Settings via HTTP POST to AP (ADR-0013); optional PGN 129025 GPS publish (opt-in, default off) |

Because the priority is 80 and iOS can't act as a softAP, iOS never
runs the AP role. The role-election protocol (ADR-0009) handles this
naturally — iOS always advertises `role:'STA'` in its heartbeat and
the existing tiebreak never selects it.

## Platform

Native Swift + SwiftUI, Xcode project, iOS 17+.

- Networking: `Network.framework` (`NWConnection`) for the UDP
  receive socket. `URLSession` for the HTTP write path.
- Persistence: `UserDefaults` for last-known settings snapshot and
  paired-WiFi metadata; `SwiftData` if a future "log" feature wants
  history.
- Background: foreground-only in v1. iOS aggressively suspends
  background sockets, and the boat use case is "phone is out, in
  hand"; pushing this into background mode is a separate hardening
  pass.
- Distribution: TestFlight → App Store. Bundle ID
  `com.koefoed.esp32boat` (placeholder).

A future Android app would be a separate native Kotlin project
sharing only the [VIRTUAL_BUS_WIRE.md](VIRTUAL_BUS_WIRE.md) contract
plus ADR-0013.

## Tab layout

Four tabs in a `TabView`, each a `NavigationStack`:

```
┌──────────────────────────────┐
│ <Tab content>                │
│                              │
│                              │
│                              │
└──────────────────────────────┘
│  Boat  │  AIS  │ Set │ Diag  │
└──────────────────────────────┘
```

### Tab 1: Boat (instrument dashboard)

Live mirror of the main instruments — port of the LCDs' Main page
plus more verbose readouts that the round display can't fit:

- Big compass widget (SwiftUI `Canvas`, same wedge / no-go-zone /
  AWA-cone treatment as RX's main page).
- TWA / TWS / AWA / AWS / TWD as a 2×2 grid below the compass.
- BSP / SOG / STW / Heading / Depth / Heel as a 2×3 grid.
- Position (lat/lon) at the bottom; tap to copy to clipboard.
- Pull-to-refresh forces re-subscribe to the AP (debug affordance).

No interactivity in v1 — read-only.

### Tab 2: AIS

Full target list (no row limit, unlike the LCDs' 4-row converter
screen). Columns: NAME · TYPE · RNG · BRG · SOG · CPA. Tap a row to
push a detail view showing:

- Full vessel name + MMSI + call sign
- Ship type + nav status (decoded to English)
- Live: SOG, COG, heading
- Last known position + last_seen age
- Apple Maps link with the position

Filters are global (ADR-0013 `ais.*` keys) — the AIS tab reflects
whatever the settings snapshot says. A bar at the top lets the user
*temporarily* widen the filter for this session (e.g. show moored
ships in a marina) without changing the global setting.

### Tab 3: Settings

The whole reason the app exists. Edits push to
`POST http://192.168.4.1/settings` and wait for `200`. The UI shows
the AP's current `settings_v` in the nav-bar title so the user knows
when their edit lands.

Sections:

- **Simulator** — toggle row per `sim.*` key. Disabled grey when no
  AP is reachable.
- **Display** — `ui.brightness` slider (0–100), `ui.idle_dim_after_s`
  picker (30s / 1m / 5m / 15m / never).
- **Navigation** — `nav.no_go_deg` stepper (20–60° in 5° steps).
- **AIS filters** — `ais.range_nm` slider (1–48 NM), `ais.hide_anchored`
  toggle, `ais.stale_s` picker (1m / 5m / 10m / 30m / 1h).
- **About** — app version, paired SSID, current AP peer name.

### Tab 4: Diagnostics

Read-only. The "look at the bus" view that today lives on the LCDs'
Comm + PGN pages.

- **Peers** — list rows for every peer in the AP's negotiator table:
  name, kind, priority, role, last-seen age. iOS's own entry at the
  top, dimmed.
- **WiFi** — SSID, BSSID of the AP we're on, channel, RSSI, this
  device's IP.
- **PGN rates** — same 19-tile honeycomb concept but rendered as a
  list (rate per PGN, sparkline). Wider than the LCD layout because
  there's no round-screen constraint.
- **Raw log** — toggle-on developer drawer that tails the most recent
  N JSON PDUs the app has received. Useful when debugging a new
  setting key or a malformed peer.

## Connection lifecycle

```
launch
  ├─ load cached settings snapshot from UserDefaults
  └─ start NWPathMonitor
       ├─ on path satisfied + WiFi SSID == _wifi_nmea2k
       │    open UDP listener on kBusPort
       │    start 5-s heartbeat publisher
       │    GET http://192.168.4.1/settings on first connect
       └─ on path lost or SSID changed
            close UDP listener
            stop heartbeat
            mark UI as "offline" (greys + last-known timestamp)
```

The app uses `WiFi association == bus join`. There is no "pair"
flow — the user joins the WiFi network from iOS Settings the normal
way (one-time, password from
[wifi_credentials.md](../../.claude/projects/...)) and the app
just lights up when the SSID is right.

## Things explicitly out of scope (v1)

- iOS publishing instrument PGNs back to the bus, beyond the opt-in
  phone-GPS source (PGN 129025) shipped in step 4. Any further
  iOS-sourced PGNs (e.g. phone heading/IMU) stay reserved for v2.
- iOS as the AP. Can't happen on iOS — no softAP API.
- Push notifications (AIS proximity alert, no-go-zone alarm, low
  battery). v2+.
- Per-peer settings overrides. ADR-0013 explicitly chose all-global;
  any future per-peer config would require schema rev.
- Background-mode operation. v1 is foreground-only.

## See also

- [ADR-0013 — Settings control plane](adr/0013-settings-control-plane.md)
- [ADR-0001 — WiFi not BLE](adr/0001-wifi-not-ble.md)
- [SCREEN_REDESIGN.md](SCREEN_REDESIGN.md) — the LCD changes that
  triggered the iOS app's existence
- [CONTEXT.md](CONTEXT.md) — glossary, including new `iOS-app peer`
  entry
- [VIRTUAL_BUS_WIRE.md](VIRTUAL_BUS_WIRE.md) — wire format the iOS
  app speaks

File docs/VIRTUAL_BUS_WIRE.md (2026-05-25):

# Virtual N2K Bus — Wire Specification

This document is the contract between the three firmware envs in this
repo — the TX board (`nmea2k_tx_wifi`), the RX board (`..._wifi`),
the AIS converter (`nmea_converter`, which decodes AIS today and will
bridge to a physical N2K bus once its SN65HVD230 is wired) — and a
planned **iOS companion app**.

Authoritative architectural decisions live in `docs/adr/0001-0008.md`.
This file pins the implementation details those ADRs leave open:
exact JSON shape, PGN numbers, field names, units, cadences, and
credentials. The converter env must match this document; the TX is
the first-mover publisher.

## Transport

- **Group:** `239.255.78.85` (administratively-scoped IPv4 multicast).
- **Port:** `60001` (UDP).
- **TTL:** `1` (boat-LAN scope; do not let multicast leak past an AP).
- **MTU budget:** stay under 1024 bytes per packet. One PGN per packet.

## Network

- SoftAP `_wifi_nmea2k` / WPA2-PSK + CCMP-only / `showmetrust`. See
  `~/.claude/projects/-Users-jeppekoefoed-Documents-Claude-Projects-esp32-boat/memory/wifi_credentials.md`.
- Role election (round 83 / ADR-0009): every ESP32 peer runs the same
  protocol on boot. Priority-weighted backoff (RX:0s, converter:4s,
  TX:8s), then a 2 s WiFi scan. If SSID is up → join as STA; if not →
  become AP. A higher-priority peer that arrives later takes over via
  polite handoff (`takeover_announce` + `going_down`, ~5–10 s outage).

## Packet shape

One JSON object per UDP packet, no framing, no terminator. UTF-8.

```json
{
  "pgn": 130306,
  "src": 255,
  "peer": "esp32-boat-tx",
  "fields": {
    "sid": 7,
    "windSpeed": 5.34,
    "windAngle": 2.117,
    "reference": "Apparent"
  }
}
```

- `pgn` *(uint16, required)* — the N2K PGN number this packet represents.
- `src` *(uint8, required)* — always `255` for off-bus peers (the N2K
  "unclaimed/null device" sentinel). Bridge ESPs in the mirror direction
  pass the real device's claimed src through here. See ADR-0005.
- `peer` *(string, required)* — application-level identity of the
  publisher: `"esp32-boat-tx"`, `"esp32-boat-rx"`, `"nmea-converter"`,
  `"ios-app"`. Subscribers may dedupe or filter on this.
- `fields` *(object, required)* — per-PGN payload, naming and units
  per the CANboat JSON convention.

### Unit conventions (CANboat-aligned)

- **Angles:** radians (degrees × π / 180). Range `-π…π` for relative,
  `0…2π` for compass-style absolute. The receiver converts to degrees
  for display.
- **Speeds:** metres per second. (1 knot = 0.514444 m/s.)
- **Distances:** metres.
- **Temperatures:** Kelvin. (°C + 273.15.)
- **Lat/lon:** decimal degrees as IEEE-754 double. ±90 / ±180.
- **Strings used for enums** (e.g. `"True"` / `"Magnetic"` /
  `"Apparent"`) — never raw integer codes.

### SID

The `sid` field is the per-PGN sequence ID that ties together
related PGNs (e.g. position-rapid + COG/SOG-rapid sharing the same SID
mean they describe the same instant). It's a `uint8` that wraps at
253; values 254/255 are CANboat "null". Publishers increment per
*publish event*, not per PGN — so one wind publish that emits a True
and an Apparent packet uses the same SID for both.

## PGN map (esp32-boat publish set)

Mapping from the existing `include/BoatBle.h` PDUs into individual
PGN packets. Each row is one UDP packet; the TX may emit several rows
per simulator tick.

### Wind — from `WindPdu`

| Bits set in `valid_mask` | PGN | fields |
|---|---|---|
| bit 1 (TWS) AND bit 0 (TWA) | 130306  | `sid`, `windSpeed` (m/s), `windAngle` (rad, relative), `reference: "True"` |
| bit 1 (TWS) AND bit 2 (TWD) | 130306  | `sid`, `windSpeed` (m/s), `windAngle` (rad, compass abs), `reference: "True (ground referenced to North)"` |
| bit 4 (AWS) AND bit 3 (AWA) | 130306  | `sid`, `windSpeed` (m/s), `windAngle` (rad, relative), `reference: "Apparent"` |

Note: if both TWA and TWD are present, emit both — they're distinct
true-wind references.

### GPS — from `GpsPdu`

| Bits set | PGN | fields |
|---|---|---|
| bit 0 (LAT) AND bit 1 (LON) | 129025 | `latitude` (deg), `longitude` (deg) |
| bit 2 (COG) AND bit 3 (SOG) | 129026 | `sid`, `cogReference: "True"`, `cog` (rad), `sog` (m/s) |

### Heading + boat speed — from `HeadingPdu`

| Bits set | PGN | fields |
|---|---|---|
| bit 0 (HDG) | 127250 | `sid`, `heading` (rad), `reference: "Magnetic"` |
| bit 1 (BSPD) | 128259 | `sid`, `speedWaterReferenced` (m/s), `speedWaterReferencedType: "Paddle wheel"` |

(Heading reference defaults to `Magnetic` because that's what the
simulator and most compasses produce. If a true-heading source ever
joins, it gets a separate row with `reference: "True"`.)

### Depth + temperatures — from `DepthTempPdu`

| Bits set | PGN | fields |
|---|---|---|
| bit 0 (DEP) | 128267 | `sid`, `depth` (m), `offset: 0.0` |
| bit 1 (AIR-T) | 130316 | `sid`, `instance: 0`, `source: "Outside Temperature"`, `actualTemperature` (K) |
| bit 2 (SEA-T) | 130316 | `sid`, `instance: 1`, `source: "Sea Temperature"`, `actualTemperature` (K) |

### Attitude + engine — from `AttitudePdu`

| Bits set | PGN | fields |
|---|---|---|
| bit 0 (HEEL) AND/OR bit 1 (PITCH) | 127257 | `sid`, `yaw: null`, `pitch` (rad), `roll` (rad) |
| bit 2 (ROT) | 127251 | `sid`, `rate` (rad/s) |
| bit 3 (RUD) | 127245 | `sid`, `instance: 0`, `position` (rad), `directionOrder: "No Order"`  |
| bit 4 (ENG-T) | 127489 | `sid`, `instance: 0`, `engineCoolantTemperature` (K) |
| bit 5 (OIL-T) | 127489 | `sid`, `instance: 0`, `engineOilTemperature` (K) |

Missing values: send `null` (JSON literal) rather than the field, so
subscribers can tell "unknown" from "zero". CANboat does this for
fields a PGN doesn't carry; we follow suit.

## Cadences

The TX publishes at the existing BLE cadences (which match N2K spec
rates) — see `src_tx/main.cpp` Step-7 globals for the canonical
numbers. Summary:

| PDU | Publish period |
|---|---|
| Wind | 100 ms (10 Hz) |
| GPS | 100 ms |
| Heading | 100 ms |
| Depth | 1 s |
| Sea temp | 2 s |
| Air temp | 2 s |
| Attitude | 100 ms |

Plus a **30-second republish** per channel: even if no new sample
arrived, re-emit the last known value. This is the late-joiner
catch-up mechanism from ADR-0006. The republish reuses the most
recent SID rather than minting a new one — same data, same SID.

## Receive side

The RX joins the multicast group, parses each packet, dispatches by
`pgn`, and calls the matching `BoatState` setter. PGN handlers are a
small switch in `src/NmeaBridge.cpp` (the `DATA_SOURCE_WIFI` branch),
mirroring what the production `tNMEA2000` path does on a real bus.

Lossiness is acceptable — UDP plus the 30 s republish bounds time to
populated state. The honeycomb's "dim" colour is the correct visual
response to a brief multicast drop; no special-case logic required.

## Versioning

If a PGN field name or unit ever changes, bump the multicast port
(`60001` → `60002`). Old subscribers stop seeing traffic (clean
failure) rather than silently misinterpreting fields.

## Control PGN — heartbeat / role election

PGN 65500 (N2K manufacturer-proprietary single-frame range) carries
the role-election control messages. Same wire format as data PGNs,
emitted by every peer every 5 s on the multicast group:

```json
{
  "pgn": 65500,
  "src": 255,
  "peer": "esp32-boat-rx",
  "fields": {
    "event":     "heartbeat",          // or takeover_announce / going_down
    "kind":      "RX",                 // TX / RX / converter / iOS
    "priority":  200,
    "role":      "AP",                 // AP / STA / electing
    "ap_ip":     "192.168.4.1",
    "uptime_ms": 123456
  }
}
```

Subscribers track a peer table (peer name → kind/priority/role/last-
seen) and use it to drive election + handoff decisions. See
`docs/adr/0009-wifi-role-election.md` for the full protocol.

## Cross-firmware obligations

The `nmea_converter` env (round 83 — partial):
- ✅ Participates in role election via PGN 65500 heartbeats.
- ⏳ AIS PGN multicast publish (129038/129039/etc.) — deferred to a
  follow-up round. Requires intercepting `tNMEA2000::SendMsg()` via
  a subclass of `NMEA2000_esp32_twai`.
- ✅ Honours the same 30 s republish rule for state it owns.

The iOS app must:
- Be subscribe-only initially. Publishing requires the proxy-write
  allow-list path on a Bridge ESP, which doesn't exist yet.

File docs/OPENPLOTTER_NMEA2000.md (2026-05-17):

# OpenPlotter as the NMEA 2000 source

A standalone briefing for a future agent / future-me picking up the
**step 5 bring-up**: connecting the esp32-boat TX board to a real
NMEA 2000 backbone and proving that real PGNs flow end-to-end into
the RX. Hardware is in hand but the bus has no live sensors yet, so
OpenPlotter is being used to inject the traffic.

This is its own context — read it in a fresh session that doesn't
need to carry the BLE bridge / LVGL UI / firmware-architecture work
in head.

## What this is solving

The TX firmware compiles and runs the simulator over BLE today. To
prove the production path, we need real PGNs hitting the
SN65HVD230 → ESP32-S3 TWAI path. The boat has no installed sensors
(wind transducer, depth, etc.) yet, so the only available source of
real bus traffic is OpenPlotter on a Raspberry Pi acting as a
sender. Once that loop closes (OpenPlotter → backbone → TX → BLE →
RX → display), step 5 is done and we can move on to physical sensor
install when those parts arrive.

## What hardware is on hand

- **NMEA 2000 backbone cable + drop cable + power tap.** Standard
  Micro-C connectors. Both end terminators present (assume yes; if
  the user is unsure, multimeter across CAN-H/L should read ~60 Ω
  with the bus de-energised — that's two 120 Ω terminators in
  parallel).
- **No sensors connected to the backbone yet.** Bus is electrically
  alive once powered but carries no PGN traffic.
- **OpenPlotter setup on a Raspberry Pi.** Software stack — Signal K
  server, kplex, OpenCPN, etc. Pi model unknown; assume Pi 4 or
  newer with USB ports available.
- **The esp32-boat TX board** (Waveshare ESP32-S3-Touch-AMOLED-1.75-G,
  USB-C powered for bench testing).
- **SN65HVD230 CAN transceiver module** (3.3 V native, see
  [BOM.md](BOM.md)). Not yet wired to anything; TX-side pins to use
  are picked in step 5 of [ROADMAP.md](ROADMAP.md) (not yet committed
  to specific GPIOs — TWAI on the S3 is flexible).
- **The esp32-boat RX board** (Waveshare ESP32-S3-Touch-LCD-2.1),
  already flashed with the `_ble` env and known to subscribe to the
  TX over BLE.

## What hardware is NOT yet on hand (likely)

- A USB-to-NMEA-2000 gateway for the Pi. OpenPlotter does **not**
  natively emit NMEA 2000 over the air; it speaks Signal K
  internally, NMEA 0183 trivially, and N2K only via specific
  hardware gateways. This is the most likely missing piece.
  Candidates:
  - **Actisense NGT-1** — gold standard, ~€350, well-supported by
    canboat and Signal K.
  - **Yacht Devices YDNU-02** — about half the price, similar
    feature set, USB.
  - **canable.io / candleLight USB-to-CAN adapter** + canboat's
    `n2k-can-receiver` / `actisense-serial` style driver. Cheapest
    path (~€30), but more software setup; the kernel needs the
    `gs_usb` driver and the user must configure SocketCAN
    (`ip link set can0 up type can bitrate 250000`).
  - **PiCAN2 / PiCAN-M HAT** — directly mounts on the Pi GPIO
    header, exposes CAN as `can0` via SocketCAN. The "-M" variant
    has the Micro-C cabling on the HAT itself, removing a level
    of pigtail. ~€60–€80.

  Confirm with the user which (if any) of these they have or want
  to buy before designing the integration further.

## How OpenPlotter emits NMEA 2000

The pipeline OpenPlotter exposes:

```
boat sensors (NMEA 0183, NMEA 2000, I²C, USB GPS, etc.)
        ↓
   Signal K server (the heart of OpenPlotter — normalises everything
                    to its internal data model)
        ↓
   output plugins
        ├── signalk-to-nmea0183 → NMEA 0183 stream
        ├── signalk-to-nmea2000 → calls a CAN backend (canboat /
        │                          SocketCAN) to write PGNs
        └── signalk-server-node native PGN out (if installed)
        ↓
   USB N2K gateway / CAN HAT
        ↓
   NMEA 2000 backbone
```

The `signalk-to-nmea2000` plugin is the one we care about. It maps
Signal K paths (e.g. `environment.wind.speedApparent`) to specific
PGN encoders inside canboat (`actisense-serial` for NGT-1-style
gateways; SocketCAN for HAT-style or canable). Defaults cover the
common PGNs — wind, heading, GPS, depth, water temp — which is
exactly the set we already decode.

There's also `signalk-to-canboat` and the `n2kanalyzer` family of
tools — same idea, different glue. The user has used OpenPlotter
before (their phrasing: "may be able to get it to output NMEA 2K"),
so they likely have at least Signal K running.

## Open questions to resolve in the first session

Ask the user, in roughly this order:

1. **What hardware connects the Pi to the bus today?** None, USB
   gateway (which model?), or CAN HAT (which model?). Determines
   100% of the rest.
2. **What's already running on OpenPlotter?** Signal K server up?
   Any data sources configured? Any sample / synthetic data
   plugins installed?
3. **Does the user want OpenPlotter to inject *simulated* sensor
   data**, or are they planning to feed it from a NMEA 0183 source
   (e.g. an old chartplotter) that gets converted up to NMEA 2000?
   The former is faster to set up; the latter is closer to real-
   boat conditions.
4. **What's the physical layout?** Does the Pi sit next to the TX
   and the backbone, or is one of them remote? Affects whether
   we're testing on a bench (everything on a desk) or partially
   installed.

## Suggested first session structure

1. **Verify the bus is alive.** Power the backbone (~12 V on the
   red/black pair). Multimeter across CAN-H/L: ~60 Ω with bus
   off, ~2.5 V on both with bus on. If either reading is wrong,
   stop and diagnose cabling before doing anything else.
2. **Get the Pi onto the bus.** Install + configure the chosen
   gateway/HAT. For SocketCAN-based paths:
   ```bash
   sudo ip link set can0 up type can bitrate 250000
   candump can0    # should show nothing yet — empty bus
   ```
   For Actisense-style USB gateways:
   ```bash
   actisense-serial -s 115200 /dev/ttyUSB0 | analyzer
   ```
3. **Get Signal K outputting PGNs.** Install the
   `signalk-to-nmea2000` plugin via the Signal K admin UI. Enable
   the PGNs the esp32-boat decodes (129025 GPS position, 129026
   COG/SOG, 130306 Wind, 128267 Depth, 130316 Sea/Air Temp,
   127250 Heading, 128259 STW). Use a Signal K synthetic data
   plugin (e.g. `signalk-fake-data`) or hand-injected values via
   the admin UI to drive them with known numbers.
4. **Verify PGNs on the wire.** `candump can0 | grep <PGN>` (after
   converting PGN to CAN-ID range — canboat's `analyzer` tool
   does this nicely). Confirm each PGN is being emitted at its
   spec cadence.
5. **Wire the TX into the backbone.** Use a T-piece + drop cable
   to the SN65HVD230. CAN-H/CAN-L on the bus pair, 12 V → TX 5 V
   buck, GND common. **Check terminator first** — most factory
   modules ship with a 120 Ω terminator soldered on, and a third
   terminator on an already-terminated bus pulls the impedance
   too low. Remove if present.
6. **Bring up the TX with `-DSIMULATED_DATA=0`.** Currently the
   TX env has the simulator wired in via `simulateTick()`. Step
   5 will introduce a new build flag that swaps the simulator
   for `NMEA2000.ParseMessages()` calls feeding the same
   `BoatState` setters. The handlers already exist in
   `src/NmeaBridge.cpp` (RX side) — most of the work is
   porting / mirroring them on the TX so they call the existing
   BLE publishers instead of UI setters.
7. **Verify end-to-end.** RX should show the Signal K-injected
   values on the existing UI (Main page wind compass, depth
   readout, etc.). Per-channel notify counters on the TX
   Communication page should climb at the Signal K cadence,
   not the simulator cadence.

## Key references

- canboat — https://github.com/canboat/canboat — the de-facto PGN
  encoder/decoder library; underpins almost every open-source
  N2K project.
- Signal K — https://signalk.org/ — data model docs explain what
  Signal K *paths* map to which N2K *PGNs*.
- `signalk-to-nmea2000` plugin —
  https://github.com/SignalK/signalk-to-nmea2000 — the actual
  PGN-out source on the Pi side.
- ttlappalainen/NMEA2000_esp32_twai —
  https://github.com/ttlappalainen/NMEA2000_esp32_twai — the
  library the TX firmware will use to read PGNs off the
  transceiver. Use this fork (not the ESP32-classic NMEA2000_esp32)
  on the ESP32-S3 — it uses the TWAI peripheral, which is
  the only CAN controller the S3 actually has.
- Waveshare ESP32-S3-Touch-AMOLED-1.75-G schematic — already on
  hand from earlier sessions. The TWAI peripheral has flexible
  pin assignment; pick free GPIOs for CAN_TX / CAN_RX in the
  initial wiring. GPIOs 4–13 are used by the QSPI display, GPIOs
  14/15 by I²C, GPIO 17/18 reserved for LC76G UART even though
  unpopulated. GPIOs 1, 2, 3, 8, 11, 12 (etc.) are free per the
  schematic — confirm against the breakout header pins that are
  actually accessible before soldering.

## What does NOT belong in this session

- BLE protocol changes (`include/BoatBle.h`) — locked, don't
  modify.
- UI work on the RX. The RX Communication page already shows the
  numbers we need to debug step 5.
- LVGL / display driver work on the TX. The TX UI shows BLE
  state, not N2K state; once `NmeaBridge`-on-TX is feeding
  `BoatState` correctly, the existing notify counters update
  automatically.
- Step 8 (LC76G GPS). Dead-end on this board variant. Use the Pi
  + Signal K to inject GPS instead — that's cleaner anyway since
  you control the test values.

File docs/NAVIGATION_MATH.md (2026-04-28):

# Navigation math: what's simulated, what's derived

This document is the source-of-truth for which numbers on the dial come
straight from a sensor and which the device computes for itself. It also
walks through the formulas used in `BoatState::recomputeDerived_locked`
and `BoatState::setGps`, and finishes with three end-to-end worked
examples plus a diagram of the wind triangle.

The same model lives in code at `src/BoatState.cpp` (derive logic) and
`src/NmeaBridge.cpp` (which sensor outputs map onto which raw fields,
plus the simulator that fakes them on the bench).

---

## 1. What sensors actually publish

These are the *only* values the device accepts as raw input — both from
the real NMEA 2000 bus and from the SIMULATED_DATA build:

| Field | Source on a real boat | NMEA 2000 PGN |
|---|---|---|
| `lat`, `lon` | GPS receiver — position fix | 129025 |
| `awa` | Masthead anemometer — apparent wind ANGLE | 130306 (apparent ref) |
| `aws` | Masthead anemometer — apparent wind SPEED | 130306 (apparent ref) |
| `heading_mag_deg` | Fluxgate / electronic compass (magnetic) | 127250 |
| `magnetic_variation_deg` | World Magnetic Model lookup (or PGN field)  | 127250 / WMM table |
| `stw` | Paddlewheel or ultrasonic log | 128259 |
| `depth_m`, `water_temp_c` | Depth sounder + temperature probe | 128267 / 130316 |

That's it. **Boat heading comes from the COMPASS**, not from GPS.
**Movement direction comes from a GPS-position differential**, not from
a sensor-supplied COG/SOG. The real bridge ignores PGN 129026 (the
sensor-supplied COG/SOG message) so we never double-source these
quantities and so a sensor dropout immediately surfaces.

The SIMULATED_DATA build emits *only* this same set: it picks a
slowly-varying intended speed-and-heading-over-ground each tick and
**integrates** the boat's position from there, so SOG/COG have to come
out of the deltas.

## 2. What the device derives

Everything else on the dial is derived inside `BoatState`. Each setter
above runs `recomputeDerived_locked()` after writing its raw field, so
the snapshot is always coherent.

### 2.1 SOG and COG (from consecutive GPS fixes)

Done in `BoatState::setGps(lat, lon)`. Equirectangular plate-carrée
approximation — accurate to better than 0.1 % on the < 100 m baselines
between 1 Hz fixes at boat speeds, and avoids the trigonometry of a
full great-circle solution:

```
    dx_m       = (lon₂ − lon₁) · R · cos(mid_lat)
    dy_m       = (lat₂ − lat₁) · R
    distance_m = √(dx_m² + dy_m²)
    SOG_kn     = (distance_m / Δt_s) · (3600 / 1852)
    COG_deg    = (atan2(dx_m, dy_m) · 180/π)  mod 360
```

with `R = 6 371 008.8 m`. `mid_lat` is in radians and is the average of
the two fix latitudes. We use `atan2(dx, dy)` (NOT `atan2(dy, dx)`) so
the bearing is measured east-of-north — the sailor's convention.

If the boat moved less than 0.5 m between fixes, `COG` is left at its
previous value (otherwise GPS jitter at the metre scale would spin it
wildly). `SOG` is always recomputed.

### 2.2 True heading (magnetic + variation)

```
    heading_true_deg = (heading_mag_deg + magnetic_variation_deg) mod 360
```

Magnetic variation (declination) is positive east. It comes from
`navmath::lookupMagneticVariation(lat, lon)` — currently a stub that
returns Copenhagen's ≈ +5° east; will load the World Magnetic Model
coefficient grid from the SD card in a later round.

If either input is `NaN`, `heading_true` is `NaN` and the UI shows
`---`.

### 2.3 True wind (apparent wind + boat motion)

The classic vector subtraction. Convention: angles are measured FROM
where the wind comes (sailor's convention, so AWA = 0 means a wind
from straight ahead). Boat-relative frame: bow = +y, starboard = +x.

```
    apparent wind velocity vector  V_a = -AWS · (sin AWA, cos AWA)
                                          (negated because AWA is the
                                           direction the wind comes FROM,
                                           opposite to the air's motion)
    boat velocity vector           V_b = (0, STW)
    true wind velocity vector      V_t = V_a + V_b
```

The "from" angle (TWA) is `atan2(-V_t.x, -V_t.y)`. Algebra collapses
to:

```
    TWA = atan2( AWS · sin AWA,  AWS · cos AWA − STW )
    TWS =  √( (AWS · sin AWA)² + (AWS · cos AWA − STW)² )
```

If STW is missing, the code falls back to SOG. (In slack water the two
are equal; in current the wind triangle is then off by the current
vector — fine for v1, will revisit if/when current sensing lands.)

### 2.4 True wind direction (TWD) and VMG

```
    TWD  = (heading_true_deg + TWA) mod 360
    VMG  = STW · cos(TWA · π/180)
```

Negative VMG = sailing downwind.

---

## 3. The wind triangle (diagram)

See [docs/wind-triangle.svg](wind-triangle.svg) for the vector picture
that the formulas above implement. The diagram has the bow pointing up,
the boat-velocity vector along +y, the apparent-wind vector at the
masthead, and the true-wind vector closing the triangle.

---

## 4. Three worked examples

Each example walks all the way from raw sensor inputs to the dial
values the user sees. Plug the inputs into `BoatState` and you should
get the derived numbers shown.

### Example 1 — calm light air, beating upwind

A 3.5 kn breeze coming from a little to the right of the bow, boat
making 2 kn through the water heading roughly 020° true.

| Raw input | Value |
|---|---|
| `heading_mag_deg` | 015° |
| `magnetic_variation_deg` | +5° (east) |
| `awa` | +30° (stb) |
| `aws` | 3.5 kn |
| `stw` | 2.0 kn |

True heading:
```
    heading_true = 015 + 5 = 020°
```

True wind:
```
    AWS · sin AWA = 3.5 · sin 30° = 1.75
    AWS · cos AWA = 3.5 · cos 30° = 3.031
    TWA  = atan2( 1.75,  3.031 − 2.0 )
         = atan2( 1.75,  1.031 )
         ≈ 59.5° starboard
    TWS  = √(1.75² + 1.031²) ≈ √(3.063 + 1.063) ≈ 2.03 kn
```

True wind direction:
```
    TWD  = (020 + 59.5) mod 360  = 079.5° true
```

VMG:
```
    VMG  = 2.0 · cos 59.5°  ≈ 2.0 · 0.508  ≈ 1.02 kn
```

So the dial shows: HDG 020°T, TWA +60°, TWS 2.0 kn, TWD 080°T, VMG +1.0 kn.
You're on a beat at about 60° off the true wind, picking up about 1 kn
toward the mark.

### Example 2 — 15 kn beam reach

A solid sea breeze on the beam, boat overpowered slightly heading 270°
true with 6 kn through the water.

| Raw input | Value |
|---|---|
| `heading_mag_deg` | 265° |
| `magnetic_variation_deg` | +5° |
| `awa` | +60° (stb) |
| `aws` |  18.0 kn |
| `stw` | 6.0 kn |

True heading:
```
    heading_true = 265 + 5 = 270°
```

True wind:
```
    AWS · sin AWA = 18 · sin 60° = 15.59
    AWS · cos AWA = 18 · cos 60° =  9.00
    TWA = atan2(15.59, 9.00 − 6.0) = atan2(15.59, 3.00)
        ≈ 79.1° starboard
    TWS = √(15.59² + 3.00²) = √(243.0 + 9.0) ≈ 15.87 kn
```

```
    TWD = (270 + 79.1) mod 360 = 349.1° true
    VMG = 6.0 · cos 79.1° ≈ 6.0 · 0.189 ≈ 1.13 kn
```

Dial: HDG 270°T, TWA +79°, TWS 15.9 kn, TWD 349°T, VMG +1.1 kn.
Classic close reach — apparent wind bowed forward of the true.

### Example 3 — 25 kn broad reach with current

Strong following breeze on a downwind run heading 195° true at 7 kn STW.

| Raw input | Value |
|---|---|
| `heading_mag_deg` | 190° |
| `magnetic_variation_deg` | +5° |
| `awa` |  +130° (stb) |
| `aws` |  19.0 kn |
| `stw` | 7.0 kn |

True heading:
```
    heading_true = 190 + 5 = 195°
```

True wind:
```
    AWS · sin AWA = 19 · sin 130° = 19 · 0.766 = 14.55
    AWS · cos AWA = 19 · cos 130° = 19 · (−0.643) = −12.21
    TWA = atan2(14.55, −12.21 − 7.0) = atan2(14.55, −19.21)
        ≈ 180° − 37.2° = 142.8° starboard
    TWS = √(14.55² + 19.21²) = √(211.7 + 369.0) ≈ 24.10 kn
```

```
    TWD = (195 + 142.8) mod 360 = 337.8° true
    VMG = 7.0 · cos 142.8° ≈ 7.0 · (−0.797) ≈ −5.58 kn
```

Dial: HDG 195°T, TWA +143°, TWS 24.1 kn, TWD 338°T, VMG −5.6 kn.
The negative VMG (sailing 5.6 kn AWAY from the wind) is exactly what
you want on a downwind run.

---

## 5. Cross-references

| Document concept | Code reference |
|---|---|
| Raw vs derived split | `src/BoatState.h` Instruments struct comments |
| `recomputeDerived_locked` derive pipeline | `src/BoatState.cpp` |
| SOG/COG from GPS deltas | `BoatState::setGps()` in `src/BoatState.cpp` |
| Magnetic variation lookup | `src/magnetic_variation.{h,cpp}` |
| Sim integrating a real trajectory | `NmeaBridge::simulateTick()` in `src/NmeaBridge.cpp` |
| Real bridge → BoatState mapping | `NmeaBridge::handleMsg` PGN handlers in `NmeaBridge.cpp` |

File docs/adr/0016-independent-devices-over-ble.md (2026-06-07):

# Independent self-contained devices over BLE (abandon the WiFi virtual bus)

**Date:** 2026-06-07

**Status:** Accepted. **Supersedes** ADR-0001 (WiFi not BLE), ADR-0007
(softAP network model), ADR-0009 (WiFi role election), ADR-0010
(unicast star + AP relay), ADR-0011 (safety at WiFi admission),
ADR-0013 (settings control plane), ADR-0015 (standalone pod-first).
**Demotes** ADR-0002 (canboat JSON wire format), ADR-0005 (strict mirror
src), ADR-0012 (AIS cache replay) to dormant/reworked. **Revises**
ADR-0014 (comfort page) mechanism.

## Context

The whole project was built to **integrate into a boat's NMEA 2000
network**: read the backbone, mirror its PGNs onto a WiFi "virtual bus"
shared by several ESP peers, and render instruments. v1.5/v1.6 grew an
elaborate stack to make that bus work — role election, a unicast-star
relay through an elected AP, a WiFi-admission safety boundary, and an
HTTP settings control plane (ADRs 0007–0013).

Two facts collapsed that premise:

1. **There is no boat to integrate with.** The user has no N2K backbone
   to test against and no boat instruments (no wind, depth, heading).
   ADR-0015 already conceded this and pivoted to a "standalone pod," but
   kept the WiFi-bus machinery underneath.
2. **The WiFi virtual bus is too complicated to configure** for actual
   use — role election, softAP join, captive-portal stubs, AP handoff.
   It was heroic engineering for a problem the user no longer has.

What actually works and is worth keeping is much smaller: the
display/touch/PMIC bring-up for the boards (hard-won), the AIS AIVDM
**decode** (`src_converter/*.h`, pure logic), and the radar **geometry**.

## Decision

Rebuild the project as a family of **independent, self-contained
devices** (see [CONTEXT.md](../CONTEXT.md)):

1. **Each device is an island.** It does one boat job standalone — own
   inputs, own display, own NVS-persisted settings — and works with no
   phone and no other device. Devices never talk to each other.

2. **The only link is device → iOS companion over BLE.** The device is
   the BLE peripheral; the iOS app is the central. This **reverses
   ADR-0001**: we accept BLE's low bandwidth (AIS + GPS are low-rate, so
   it is ample) in exchange for escaping WiFi configuration entirely.

3. **Settings: device-persisted, iOS-written.** The device stores its
   settings in NVS and runs on them standalone with shipped defaults.
   They can be **changed only from the iOS companion** over BLE — one
   writer, no sync conflict, no on-device settings UI (the touchscreen
   is for radar interaction only).

4. **First device = the AIS-radar device.** The
   ESP32-S3-Touch-AMOLED-1.75-G (onboard LC76G GNSS) + a Daisy 2+ AIS
   receiver on a spare UART, drawing AIS targets radar-style on its
   AMOLED when it has a GPS fix. Milestone 1 includes the BLE link to a
   fresh iOS app.

5. **N2K becomes a future, optional, per-device add-on.** A device may
   later gain an SN65HVD230 to emit/read PGNs, but that is no longer the
   point of the system. The N2K encoders and the strict-`src` rule
   (ADR-0005) are kept dormant as reference.

6. **Start from scratch, preserve the driver knowledge.** Tag the
   current state (`v1-wifi-bus-archive`) so it stays recoverable, then
   rebuild a clean per-device source tree, extracting the AMOLED
   display/touch/PMIC/GPS init and the AIS-decode headers. Old ADRs are
   **superseded, not deleted** (this repo's convention).

## What each superseded/affected ADR becomes

| ADR | Was | Now |
|---|---|---|
| 0001 WiFi not BLE | chose WiFi over BLE | **superseded** — BLE, point-to-point to iOS |
| 0007 softAP network | the AP/softAP model | **superseded** — no WiFi |
| 0009 role election | dynamic AP election | **superseded** — no multi-peer network |
| 0010 unicast star relay | AP relays PGNs | **superseded** — no shared bus |
| 0011 WiFi admission safety | WPA2+MAC gate | **superseded** — BLE pairing is the boundary |
| 0013 settings control plane | HTTP-on-AP + heartbeat | **superseded** — device-local settings over BLE |
| 0015 pod-first | pod on top of WiFi bus | **superseded** — every device is standalone now |
| 0002 canboat JSON wire | JSON PGNs on the bus | **demoted** — BLE uses packed binary PDUs; JSON only if useful internally |
| 0005 strict mirror src | N2K bridging rule | **dormant** — relevant only under future N2K bridging |
| 0012 AIS cache replay | re-emit cache onto bus | **reworked** — iOS reads the device's target store on BLE connect |
| 0014 comfort page | bus + iOS-republish | **revised** — comfort is just another device/page over BLE |

## Consequences

Pro:

- The system finally matches reality: a useful box for a boat with no
  instruments and no network, testable on the hardware in hand.
- Massive reduction in moving parts — no role election, no relay, no
  AP handoff, no captive portal, no HTTP server. BLE pairing replaces
  all of WiFi onboarding.
- Each device is independently shippable and reasoned-about. Adding a
  second device (e.g. comfort) costs nothing in the first.

Con:

- A large amount of working v1 code is abandoned (the entire WiFi/bus
  stack, role negotiator, settings control plane, both the RX/TX WiFi
  publishers). Git-tagged, not lost, but no longer built.
- The radar must be **re-targeted** to the AMOLED. Both boards run
  LVGL 8.3.11 (the AMOLED uses Arduino_GFX only as LVGL's flush
  backend), so this is an LVGL→LVGL port — re-aim the canvas + screen
  dimensions, not a rewrite into a different graphics API.
- The iOS app is rebuilt from scratch (transport was the whole WiFi
  stack); the map/list/settings UI ideas carry, the code does not.
- BLE caps throughput; fine for AIS/GPS, but a constraint to respect if
  a future device wants high-rate data.
- Two boards from v1 (the RX round display and the C6 converter) have no
  role in milestone 1; their fate is deferred.

## Alternatives considered

- **Keep the WiFi bus, just simplify config (ADR-0015 pod).** Rejected
  — the user finds WiFi configuration itself the problem, not its
  surface area; BLE removes onboarding entirely.
- **One combined multi-board device over the bus.** Rejected — the
  goal is *independent* boxes, not a coordinated set.
- **Branch/fork for v2.** Rejected — same repo + a tag keeps history,
  memory, and docs in one place (see ADR-0016 decision 6).
- **Rewrite iOS transport but keep its code.** Considered; user chose a
  fresh iOS app for a clean break.

## Open questions / next

- Power: how the AMOLED device and the Daisy share a supply (Daisy is
  USB-powered; likely a shared powerbank / common 5 V).
- Spare-UART + pin budget on the AMOLED board for the Daisy feed
  alongside the LC76G UART, QSPI AMOLED, PMIC, and touch.
- The BLE GATT shape: characteristics for AIS targets, own GPS, status,
  and a settings write characteristic (crib the pattern from the
  dormant `include/BoatBle.h`, fresh content).
- Solder the LC76G UART jumpers (R15/R16) — prerequisite for own GPS.
- Fate of the RX round display and the C6 converter (future devices?).

## See also

- [CONTEXT.md](../CONTEXT.md) — the device / iOS-companion glossary.
- [ROADMAP.md](../ROADMAP.md) — the device-first roadmap.
- ADRs 0001–0015 — the superseded WiFi-bus design, kept for the trail.
- `include/BoatBle.h` — dormant BLE GATT pattern to crib from.

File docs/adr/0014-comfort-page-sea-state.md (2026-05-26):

# Comfort page: motion-reconstructed sea state, user-selected source

**Date:** 2026-05-26

**Status:** Proposed — design pinned, implementation deferred. Captured
now so the language and wire implications are agreed before any code.

## Context

We want a **comfort page** on the instrument displays, inspired by the
cruisers'-forum "wave height vs period" rule of thumb: the same wave
height is benign as long-period swell and dangerous as short-period
chop, because what matters is **steepness** (height vs wavelength, and
deep-water wavelength ≈ 1.56·T²; waves break near steepness 1/7).

The hard constraint: **this boat has no wave sensor.** `Instruments`
carries no wave height/period or pitch/heave, NMEA 2000 delivers no
sea-state from any device we own, and the virtual bus has no internet.
So a comfort number's inputs must be manufactured, not read off the bus
like wind or depth.

What we *do* have, discovered but unused: a **QMI8658 6-axis IMU on
each LCD** — `0x6B` on the RX (cockpit 2.1" round, noted in
`src/Ui.cpp` since round 10) and one on the TX (AMOLED, in a
locker/engine bay). Two motion sensors, two very different locations.

This ADR pins how motion becomes comfort. Implementation is explicitly
deferred; see **Open questions** for what is *not* yet decided.

## Decision

### Comfort is steepness, computed from a "sea state"

A **sea state** is a (wave height, wave period) pair. The **comfort
index** is a band (calm / moderate / rough / dangerous) derived from
the active sea state's steepness. See the glossary in
[CONTEXT.md](../CONTEXT.md#comfort--sea-state-planned-feature).

### Three source types, one user-selected active source

A sea state comes from one of three origins — **measured**, **manual**,
**forecast** — and the user **explicitly selects** which is active.
The comfort index is computed from the active source alone; the others
render alongside for comparison and are never auto-blended. Because
*measured* is per-IMU (below), the concrete selector choices are four:
**cockpit-measured · locker-measured · manual · forecast** (default:
cockpit-measured — comfort is what the crew feels, and the crew is in
the cockpit).

### Measured = IMU reconstruction, boat-distorted, two locations, unfused

Each LCD reconstructs a sea state from its own IMU: tilt-compensate the
accelerometer with the gyro, band-pass to the wave band, integrate to
heave, and estimate height + dominant period. The boat's hull turns the
real sea into this motion, so the result is an *inference* about the
sea, knowingly distorted. The two LCDs produce **two** measured
estimates (cockpit, locker); they are shown **side by side and never
fused** — the spread between a cockpit and a locker is itself
information.

### Boat-response model: learned, in iOS profiles, republished to the bus

The distortion is captured by a **boat-response model** (a learned
transfer function, per IMU location). It lives in an iOS **boat
profile**, keyed by a **boat ID** the bus advertises in its heartbeat,
so the right profile loads automatically and "multiple boats in the
app" = multiple profiles. iOS does the learning (storage + compute),
applies each IMU's model to that board's published motion summary, and
**republishes the two corrected measured sea states onto the bus** so
every display agrees. With no phone present, each board falls back to a
shipped **default model** on its own summary.

### Manual and forecast live in iOS

**Manual** sea state is height + period typed into the iOS app.
**Forecast** sea state is pulled from **GFS** by iOS when it has
internet — a planning / comparison reference, explicitly not a live
reading of the water outside.

## Consequences

Pro:

- Honest about uncertainty: nothing claims to *measure* the sea. The
  user sees measured-inference, manual observation, and forecast as
  distinct, selectable things — and the cockpit/locker spread exposes
  how location-dependent "comfort" is.
- Reuses the existing patterns: motion summaries ride the virtual bus
  like any PGN; the boat-response model and selection ride the
  iOS-owned side; the corrected republish mirrors the ADR-0013
  "AP-side state, push to peers" shape but with iOS as the deriver.
- The idle QMI8658s finally earn their keep, and the cockpit IMU
  measures motion exactly where comfort is felt.

Con:

- **iOS becomes a deriving publisher.** Today iOS only publishes its
  own GPS; here it computes a value *from other peers' data* and pushes
  it back. This contradicts the CONTEXT note that AIS replay is "the
  only republish-like behaviour" — that line must be revisited when
  this ships.
- Reconstruction from a single strapped-down IMU is fragile (double-
  integration drift, the hull's own response). The "measured" numbers
  are estimates, not truth; the UI must not over-state them.
- New per-board DSP (heave reconstruction) and a new bus message
  (motion summary) — neither exists yet.
- Forecast is only as fresh as the last time iOS had internet; at sea
  it is a pre-departure download, not live.
- Per-boat learned models add an identity concept (**boat ID**) the
  bus does not have today.

## Alternatives considered

- **Manual entry as the only source.** Simplest (no hardware, no DSP),
  and was the recommended first cut. Rejected by choice — the user
  wants the boat to estimate sea state itself from its motion.
- **GFS/buoy forecast as the live source.** Rejected as the *primary*
  reading — it's a forecast, not what's outside now — but kept as a
  selectable comparison/planning source.
- **Felt-motion index instead of reconstruction** (RMS vertical
  acceleration → ISO-2631-style comfort, no wave reconstruction).
  More robust signal-processing, but doesn't honour the "wave height
  vs period" framing the user asked for. Rejected; reconstruction
  chosen with eyes open about its fragility.
- **Fuse the two IMUs into one estimate** (average, or exploit bow–
  stern separation). Rejected — the boxes' relative geometry isn't
  rigidly known, so most of the "fusion" gain is noise reduction, and
  it hides *where* comfort is measured. Show both instead.
- **Boat-response model on the boat (RX NVS), bus = boat identity.**
  Lets LCDs self-correct with no phone and needs no boat-ID concept,
  but caps learning at ESP storage/compute and drops multi-boat.
  Rejected in favour of iOS-owned models (+ default-model fallback).
- **Auto "best-available" blending of the three sources.** Rejected —
  hard to reason about and hard to explain on a small round display;
  the user selects instead.

## Open questions (not yet decided)

- Wave-band corner frequencies and the height/period estimator
  (zero-crossing vs spectral peak).
- The **motion summary** wire shape — a new PGN vs a field on an
  existing one; what it carries (Hs/Tp estimate? RMS accel? a few
  spectral bins?) and at what cadence.
- How **boat ID** is derived (AP/transceiver identity? user-assigned?).
- The **comfort band** thresholds (steepness → calm/moderate/rough/
  dangerous), and units shown (m vs ft, s).
- Which displays carry the comfort page, and its layout (it is a
  natural sibling to the RX radar page).
- GFS access: source/endpoint, how iOS knows position for the lookup,
  and the pre-departure caching model.
- The learning algorithm for the boat-response model and how a profile
  bootstraps from the default.

## See also

- [CONTEXT.md](../CONTEXT.md) — "Comfort / sea state" glossary section
  (sea state, sources, active source, comfort index, boat ID, boat
  profile, boat-response model).
- ADR-0013 (settings control plane) — the "iOS writes, AP/peers adopt"
  shape this builds on; the active-source selection is a natural new
  setting.
- [IOS_APP.md](../IOS_APP.md) — where the boat profiles, manual entry,
  GFS fetch, and source selector would live.

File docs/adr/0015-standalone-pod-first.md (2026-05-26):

# Standalone pod is the first release target

**Date:** 2026-05-26

**Status:** Accepted.

## Context

The whole repo was built to **mirror a real NMEA 2000 backbone**: a
transceiver peer reads the boat's bus, fans PGNs onto the virtual WiFi
bus, and the LCDs render wind / depth / heading / boat-GPS. Every ADR so
far assumes that backbone exists.

The boat actually available for a first sea trial has **no NMEA 2000
network and no wind instrument** — and, on inspection, the kit has no
magnetic compass either (the RX I²C bus is touch / IO-expander / RTC /
QMI8658 IMU only — a 6-axis accel+gyro, no magnetometer). So:

- No wind, depth, STW, sea temp, or boat-GPS.
- No absolute heading — only **COG** from GPS, valid when moving.

What *is* available without any boat connection:

- **iPhone GPS** (CoreLocation), already published as PGN 129025.
- **AIS** via the **Daisy 2+** receiver over 3.3 V TTL serial into the
  converter — decoded and published onto the virtual bus with no N2K
  involved at all.
- The two LCDs' **IMUs** (motion / future comfort, deferred — ADR-0014).
- The **iOS app** (map, list, settings, GPS source).

Power is self-contained: the LCDs have batteries, the converter runs off
a powerbank. So a useful product exists *today* for a boat with zero
instruments — it just isn't the product the repo was aimed at.

## Decision

Make a **standalone pod** the first release ("sea-trial v1") and treat
boats-without-N2K as first-class. Four scoping decisions:

1. **Scope = AIS + GPS pod (LCD + iOS).** Real AIS via the Daisy +
   iPhone GPS, shown on the RX (radar + AIS list) and the iOS app (map
   + list). Comfort/IMU, wind/depth, a dedicated GPS module, and the
   N2K **gateway mode** are all deferred.

2. **Position = iPhone GPS only.** No GPS hardware in v1. The LCDs are
   therefore phone-dependent for own-position: with the app foregrounded
   and on the WiFi they centre on the real position; without it they
   show "NO GPS FIX". AIS targets still arrive without the phone — only
   the own-ship geometry (range/bearing, radar centre) needs it.

3. **RX page order unchanged for v1.** The wind-compass Main page still
   lands first and the radar is one swipe away. Reordering/cutting dead
   pages is deferred — not worth blocking a trial on UX.

4. **Field mode via a single `sim.master` switch.** One setting gates
   *all* simulator publishing (RX sim + converter AIS sim). Bench =
   master on (today's behaviour); trial = one tap off so only real
   sources flow. This exists specifically to stop `sim.gps` (Copenhagen
   harbour, 10 Hz) from beating the iPhone's real fix (1 Hz).

This **reverses the prior non-goal** "supporting boats without an NMEA
2000 backbone." The kit now has two **deployment modes** (see
CONTEXT.md): **gateway** (wired to a real backbone) and **standalone
pod** (no boat connection). Pod is the near-term target; gateway remains
supported.

## Consequences

Pro:

- There is a genuinely useful, testable product *now*, on the boat we
  actually have, with no new hardware — a portable AIS+GPS plotter.
- Forces the codebase to tolerate "no boat sensors", which it must do
  anyway; pod mode is the honest minimum.
- Small, well-bounded work list (see ROADMAP "Sea-trial v1").

Con:

- Own-position depends on a foregrounded phone — fragile, and the
  obvious fast-follow (a real GPS module on the converter's spare UART)
  is explicitly *not* in v1.
- No heading sensor means COG-only; displays must not imply a bow
  heading, and "which way am I pointing" at anchor is unavailable.
- The wind/depth/honeycomb pages render dead ("—") in pod mode and we
  chose not to hide them for v1 — a slightly rough first impression.
- A second deployment mode is now a permanent thing to keep working in
  both directions.

## Alternatives considered

- **Pod + IMU/comfort in v1.** Rejected — comfort is a large, research-y
  effort (ADR-0014) that would push a sea trial out by weeks.
- **iOS-only first release.** Rejected — the LCDs are the heart of the
  project and already mostly work; cutting them undersells what's ready.
- **Add a real GPS module for v1.** Rejected for v1 (hardware + driver +
  test delays the trial); kept as the top fast-follow because
  phone-only position is the pod's weakest point.
- **Pod build flag that compiles out dead pages.** Rejected for v1 —
  a new build variant to maintain; "leave as-is" is cheaper.
- **Toggle each `sim.*` off by hand / flip sim defaults to off.**
  Rejected — seven switches is error-prone (forgetting `sim.gps`
  teleports you), and flipping defaults inverts the bench workflow. A
  single master switch is one tap and hard to get wrong.

## Open questions / fast-follows

- A real GPS module (u-blox-class on the converter UART) to make the pod
  phone-independent — the most likely v1.1.
- A magnetometer add-on for true heading (would re-enable a real compass
  rose, heading-up radar, and wind-triangle math if wind ever appears).
- Comfort/IMU (ADR-0014) once the pod is proven.
- Pod-mode page-set cleanup (hide the dead wind/depth pages).

## See also

- ADR-0013 (settings control plane) — `sim.master` is one more key in it.
- ADR-0014 (comfort page) — the deferred IMU feature.
- [CONTEXT.md](../CONTEXT.md) — "Deployment modes" (gateway vs pod).
- [ROADMAP.md](../ROADMAP.md) — "Sea-trial v1" prioritised work list.

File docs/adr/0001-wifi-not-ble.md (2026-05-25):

# WiFi (not BLE) for the cross-device data plane

A BLE bridge direction was parked on 2026-05-18 as the future path for
sharing AIS data with the esp32-boat RX board and a phone. When the goal
broadened on 2026-05-22 to "a virtual N2K backbone shared by every ESP and
an iOS app," BLE's constraints became disqualifying: ≈50 kbit/s per link,
iOS can only be a central (no peripheral / multi-peer mesh role), and ~10 m
practical range through a fibreglass hull. WiFi with UDP multicast on a
shared LAN matches the peer-to-peer broadcast semantics of N2K natively and
has none of those limits.

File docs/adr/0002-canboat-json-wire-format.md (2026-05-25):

# CANboat-style JSON as the virtual-bus wire format

The virtual bus carries one CANboat-style JSON object per UDP multicast
packet, e.g.
`{"pgn": 129038, "src": 35, "fields": {...}}`. We considered raw N2K frames
(smallest, but iOS-side decoders are scarce) and SignalK (modern marine
standard, but the full-server implementation is heavy on ESP32-C6, and
SignalK abstracts away the N2K shape we want to replicate). Decoded JSON
sits between them: self-documenting, parsable on iOS with no dedicated
library, and round-trippable back to N2K frames by a Bridge ESP that needs
to re-emit on a real bus.

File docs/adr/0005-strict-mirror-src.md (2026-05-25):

# Strict-mirror src policy: off-bus peers don't claim N2K addresses

> **Partly amended 2026-05-24.** The Bridge-ESP / allow-list framing
> below is retired (ADR-0010 / ADR-0011). The `src` and `peer` field
> semantics described here are unchanged and still apply — read
> "Bridge ESP" as **transceiver peer** and "proxy-write direction" as
> **virtual-to-real direction**. There is no per-PGN allow-list
> gate any more; the elected writer (ADR-0010) emits every
> WiFi-originated PGN with its own claimed src.

In the mirror direction (real bus → virtual bus), PGNs are forwarded with
the original device's src preserved. In the proxy-write direction (virtual
bus → real bus), the Bridge ESP re-emits with its own claimed src; the
originating peer's identity is recorded in a `peer` field on the multicast
JSON but never appears on the real bus. We considered a "joint virtual
bus" model where every peer (including iOS) claims an N2K src, but that
creates conflict risk with real bus devices and forces every peer to
manage src state. The mirror model means only Bridge ESPs do address
claim, which keeps the address space coherent on each real bus.

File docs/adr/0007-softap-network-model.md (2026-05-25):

# One ESP runs softAP; other ESPs and the iPhone join it

For the boat deployment, the Bridge ESP (or whichever ESP is most reliably
powered) brings up a softAP with a known SSID; other ESPs and the iPhone
connect to it as stations. We considered relying on an existing boat WiFi
router (cleaner, but assumes hardware that's not always present at
anchor) and a try-station-then-softAP hybrid (more robust but adds
firmware mode-switching logic). softAP-only keeps the deployment
self-contained at the cost of bench-test inconvenience — the laptop loses
internet while joined to the boat AP — which the user accepted because iOS
testing is the bench-testing pattern anyway.

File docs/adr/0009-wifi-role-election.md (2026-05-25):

# WiFi AP/STA role election among virtual-bus peers

**Date:** 2026-05-23. Supersedes ADR-0008's hardcoded "TX hosts the AP at
the bench stage" workaround.

## Context

ADR-0007 named the Bridge ESP (the `nmea_converter` firmware env in
this repo) as the long-term softAP host. ADR-0008 made TX the bench-
stage host because the converter wasn't yet on the bus. Round 81
proved that works.

But the deployment model is *ad-hoc cockpit instrument* (Q1b in the
grilling): the set of present devices varies per boot. Sometimes only
TX is plugged in. Sometimes TX+RX. Sometimes all three. With ADR-0008,
the bench loop falls apart the moment TX isn't first to boot, and the
iOS app has nothing to join when TX is absent. We need a runtime
election among whichever peers are present.

## Decision

Replace ADR-0008's fixed TX-as-AP with a WiFi-only role election
protocol, run by each ESP32 peer on boot and continuously thereafter.

### Roles

Three peer kinds, each with a fixed (compile-time) priority:

| Peer | Priority | Rationale |
|---|---|---|
| RX | 200 | Indoor display; most protected RF position; powered last to be moved |
| converter  | 150 | C6 has CPU headroom; powered when boat instruments are on |
| TX | 100 | Often outdoor near GPS; least protected RF position |
| iOS app | (n/a) | STA-only by construction; ineligible to be AP |

Priority is a compile-time `constexpr uint8_t kVbusPriority` declared
per env in `include/VbusRole.h` (selected via `-DVBUS_BOARD_KIND=...`
build flag). Future iOS-app-driven priority override is a documented
TODO; this round ships with fixed compile-time values.

### Cold-boot election

Each peer, on boot:

1. **Priority-weighted backoff.** Wait `(255 - kVbusPriority) / 10 × 4 s`.
   With the table above:
   - RX (priority 200): waits 0 s (the formula gives ~22 s but RX clamps to 0)
   - converter (priority 150): waits 4 s
   - TX (priority 100): waits 8 s
   The intent is "higher priority scans first, lower priority gives the
   higher-priority peer a chance to become AP first."
2. **WiFi scan** for SSID `_wifi_nmea2k` for 2 s.
3. **If found** → become STA, `WiFi.begin()`, proceed to runtime loop.
4. **If not found** → become AP, `WiFi.softAP()` with WPA2-PSK + CCMP
   (per ADR-0008 inline workaround), proceed to runtime loop.

### Runtime heartbeat

Every 5 s, every peer publishes one **control PGN packet** onto the
multicast group `239.255.78.85:60001` using PGN `65500` (in the
N2K manufacturer-proprietary single-frame range, 65280–65535):

```json
{
  "pgn": 65500,
  "src": 255,
  "peer": "esp32-boat-rx",
  "fields": {
    "event":     "heartbeat",
    "kind":      "RX",
    "priority":  200,
    "role":      "AP",
    "ap_ip":     "192.168.4.1",
    "uptime_ms": 123456
  }
}
```

`event` is one of `heartbeat`, `takeover_announce`, `going_down`.
`role` is one of `AP`, `STA`, `electing`.

Every peer maintains a small **peer table** (last-seen timestamp +
last-reported role/priority) keyed by `peer` field. Pruned when a
peer's heartbeat goes silent for > 30 s.

### Re-election triggers (AP-died path)

A STA peer triggers re-election when both:
- WiFi `WL_DISCONNECTED` for > 10 s, OR
- 5 consecutive missed AP heartbeats (25 s) while WiFi still reports
  `WL_CONNECTED`

On re-election: drop the WiFi link, re-run cold-boot election from
step 1 (priority-weighted backoff + scan).

### Polite handoff (higher-priority peer arrives)

When the current AP sees a STA peer with `priority > my_priority` in
the peer table:

1. The arriving high-priority peer sends 3 × `takeover_announce`
   over 1.5 s.
2. The current (low-priority) AP receives `takeover_announce`,
   sends 1 × `going_down`, waits 500 ms.
3. Current AP calls `WiFi.softAPdisconnect(true)`, then
   `WiFi.mode(WIFI_STA)` + `WiFi.begin()` to join the new AP.
4. The arriving peer brings up its own softAP under the same SSID,
   starts publishing its own heartbeat with `role: "AP"`.
5. All other STAs see their AP go down, get DHCP from the new AP
   on its 192.168.4.x range, multicast resumes within ~3–5 s.

Total outage: ~5–10 s. Acceptable per ADR-0006 (30 s republish
covers the data gap).

### iOS app

iOS is a STA peer that:
- Joins `_wifi_nmea2k` (whichever ESP32 is currently AP serves it)
- Subscribes to the multicast group
- May publish PGNs subject to Bridge ESP allow-list (ADR-0004)
- Sends its own `heartbeat` advertising `kind: "iOS"`, `priority: 0`,
  `role: "STA"` so other peers know it's present
- Never becomes AP (iOS can't softAP arbitrary peers)
- May publish GPS PGN 129025/129026 if it observes no boat GPS for
  > 10 s (deferred to iOS-app implementation; ESP firmware doesn't
  care which peer publishes GPS)
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

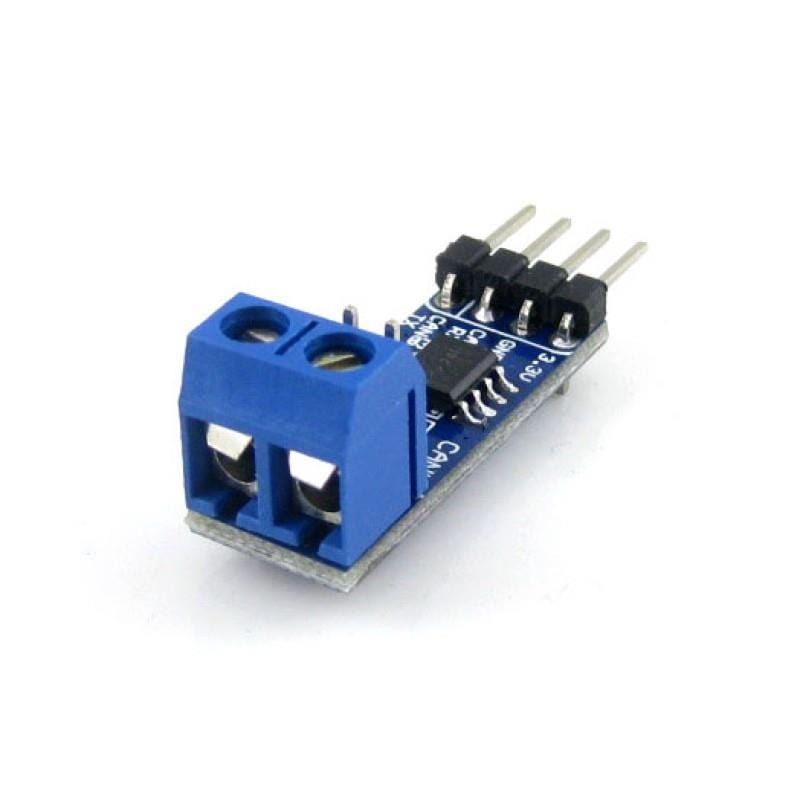
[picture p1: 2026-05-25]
docs/hardware/images/sn65hvd230_back.jpg

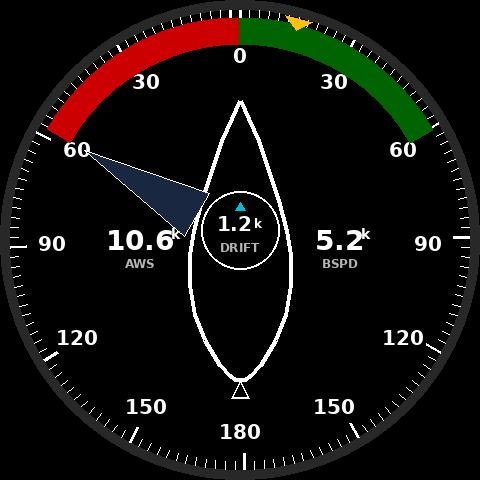
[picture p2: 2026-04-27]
docs/overview-mockup.png

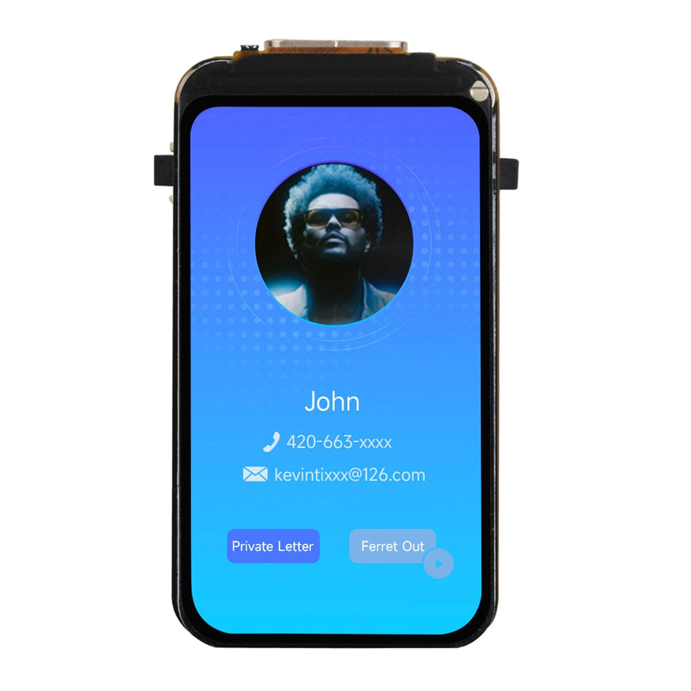
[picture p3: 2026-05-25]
docs/hardware/images/esp32c6_back.jpg

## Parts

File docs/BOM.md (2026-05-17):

# Bill of Materials

Two ESP32-S3 boards, one CAN transceiver, the NMEA 2000 cabling that gets
the transceiver onto the bus, and the bits to mount everything. The
**display board** (RX) lives in the cockpit; the **transmitter board** (TX)
lives near the backbone — typically in a wiring locker or engine bay —
and connects to the cockpit display wirelessly over BLE.

## Core electronics

| Part | Qty | Notes | Typical source |
|---|---|---|---|
| Waveshare ESP32-S3-Touch-LCD-2.1 (RECEIVER) | 1 | Cockpit display. 480×480 round IPS, capacitive touch, ESP32-S3R8 (8 MB PSRAM / 16 MB flash) | waveshare.com |
| Waveshare ESP32-S3-Touch-AMOLED-1.75-G (TRANSMITTER) | 1 | NMEA 2000 → BLE bridge. 466×466 AMOLED (status only), AXP2101 PMIC, QMI8658 IMU, LC76G GNSS (G variant). ESP32-S3R8 again. | waveshare.com |
| SN65HVD230 CAN transceiver module | 1 | Now lives on the TX side. 3.3V-native CAN transceiver. Any generic breakout works. Avoid 5V-only MCP2551. **Check the 120 Ω terminator: remove it on this module if the backbone already has terminators at both ends** (it usually does — see WIRING). | Amazon, Mouser, AliExpress |
| NMEA 2000 T-piece (Micro-C) | 1 | Drops the TX off the backbone without breaking it | Ancor, Actisense, Garmin |
| NMEA 2000 drop cable, Micro-C, ~1 m | 1 | Male end into the T-piece. We'll cut the other end to wire into the transceiver. | Same brands |
| 12V → 5V buck converter, ≥ 2A | 1 | Boat bus is 12V nominal but can spike to 15V. Pick one with input up to 24–36V. The TX is USB-powered for v1 bench testing; this buck only matters when you move the TX onto the boat permanently. | Pololu D36V28F5, Mean Well SD-15A-5 |
| 1 A inline fuse + holder (ATC) | 1 | On the 12V feed, close to the tap point | Any marine chandlery |
| USB-C pigtail / panel mount | 2 | One for the RX (cockpit power), one for the TX once it goes from bench USB to the boat's 5 V rail | Amazon |
| 120 Ω resistor (terminator) | 0–1 | Only if the NMEA 2000 backbone is missing a terminator at one end. Most boats already have both. | — |
| 4-core shielded cable, ~0.5 m | 1 | CAN-H / CAN-L / +12V / GND between T-piece side and the TX-side transceiver | — |

## Mechanical

| Part | Qty | Notes |
|---|---|---|
| Round bezel / enclosure for 2.1" display | 1 | Waveshare sells a matching case; there are 3D-printable STLs on Printables / Thingiverse if you have access to a printer |
| M2 / M2.5 mounting screws, 6 mm | 4 | Board mounting |
| Gland / strain relief for cable entry | 1 | Keeps water out of the enclosure |

## Optional but nice to have

| Part | Notes |
|---|---|
| microSD card, 8–32 GB, Class 10 | Lets us log PGN traffic + store config. Required before v3 (maps). |
| 3.3V logic analyzer / cheap USB CAN sniffer (canable.io) | Invaluable for debugging when a PGN isn't showing up |
| Second SN65HVD230 + spare ESP32 | Build a bench harness to replay logged PGNs without being on the boat |

## Notes on the transceiver choice

The ESP32-S3 has a built-in TWAI (CAN 2.0B) controller. We just need a CAN
PHY/transceiver between its 3.3 V TX/RX pins and the twisted pair on the bus.
**SN65HVD230** is the standard choice — 3.3 V native, correct logic levels, no
level shifter needed. Avoid the MCP2515+MCP2551 combo (SPI-based, older, and
unnecessary overhead here).

NMEA 2000 is electrically identical to 250 kbit CAN with a specific connector
and PGN dictionary on top. The transceiver doesn't know or care.

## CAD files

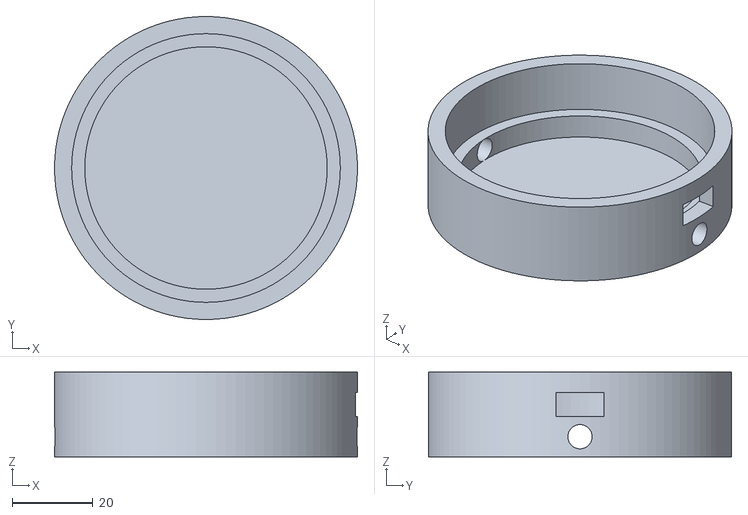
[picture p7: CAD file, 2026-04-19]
hardware/case/case_body.stl
75.0 x 75.0 x 21.0

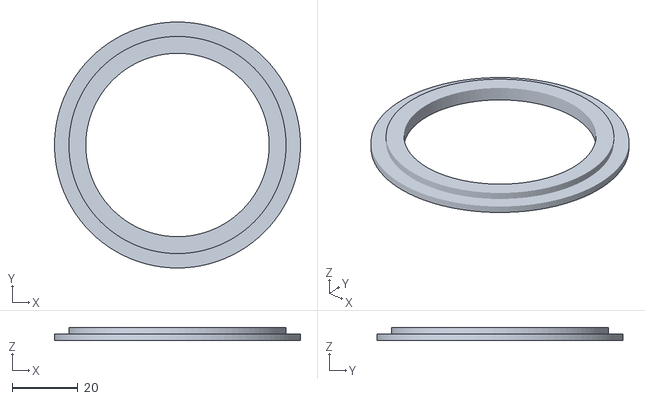
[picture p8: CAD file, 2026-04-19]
hardware/case/case_bezel.stl
75.0 x 75.0 x 4.00

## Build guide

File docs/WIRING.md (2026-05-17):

# Wiring

## Overview

```
 ┌─────────────── NMEA 2000 backbone (boat) ──────────────┐
 │  …  ── T-piece ──  T-piece ── T-piece ── (terminator)  │
 └───────────────┬────────────────────────────────────────┘
                 │  drop cable (Micro-C, ~1 m)
                 ▼
 ┌───────────────────────────────────────────────┐
 │  CAN-H      CAN-L      NET-V (+12V)   NET-C   │  cut end, strip, screw terminals
 │   │           │          │              │     │
 │   │           │        ┌─▼─ 1A fuse ─┐  │     │
 │   │           │        │             │  │     │
 │   │           │        ▼             │  │     │
 │   │           │    12V→5V buck       │  │     │
 │   │           │    5V out ──► USB-C  │  │     │
 │   │           │                      │  │     │
 │   ▼           ▼                      │  │     │
 │  SN65HVD230 transceiver              │  │     │
 │   CANH  CANL  VCC(3.3V)  GND        (common GND across everything)
 │    ·     ·     ·          ·                   │
 └────┼─────┼─────┼──────────┼───────────────────┘
      │     │     │          │
      │     │  from TX ESP32 3V3 pin
      │     │                │
 ┌────▼─────▼────────────────▼─────┐
 │  Waveshare ESP32-S3-Touch-      │   TRANSMITTER (wiring locker)
 │  AMOLED-1.75-G                  │   USB-powered for v1, 12V→5V buck for boat install
 │                                 │
 │  CAN_TX  ◄── GPIO (TBC, step 5) │
 │  CAN_RX  ◄── GPIO (TBC, step 5) │
 │  3V3     ──► transceiver VCC    │
 │  GND     ──► transceiver GND    │
 │                                 │
 │      BLE 5 GATT peripheral      │
 └─────────────┬───────────────────┘
               │  wireless
               ▼
 ┌─────────────────────────────────┐
 │  Waveshare ESP32-S3-Touch-      │   RECEIVER (cockpit)
 │  LCD-2.1                        │   USB-C power, no boat-side wiring
 │                                 │
 │      BLE 5 GATT central         │
 └─────────────────────────────────┘
```

## ESP32-S3 pin assignments — TRANSMITTER

Two GPIOs go between the broken-out TX header pads and the external
SN65HVD230 CAN transceiver. Specific pin choice is locked in step 5
(the BLE bridge has to come up first); the pins below are the
schematic-verified candidates.

| Signal | ESP32-S3 GPIO | Goes to | Notes |
|---|---|---|---|
| CAN TX | **TBC, step 5** | SN65HVD230 `TXD` | TWAI controller TX output. Pick from the broken-out header pads (label "SDA" + "SCL" + 3× IO + UART RX/TX). |
| CAN RX | **TBC, step 5** | SN65HVD230 `RXD` | TWAI controller RX input |
| 3V3 | `3V3` pad | SN65HVD230 `VCC` | The board's regulated 3.3 V rail powers the transceiver |
| GND | `GND` pad | SN65HVD230 `GND` + NMEA 2000 NET-C | Common ground |

### TX internal pin map (Waveshare ESP32-S3-Touch-AMOLED-1.75-G)

Decoded from the Waveshare schematic + confirmed at runtime against the
factory firmware. The board's I²C bus is shared by AXP2101 (PMIC at
0x34), TCA9554 (GPIO expander at 0x20), CST9217 (touch at 0x5a),
QMI8658 (IMU at 0x6b), PCF85063 (RTC at 0x51), ES8311 (audio codec at
0x18), ES7210 (mic ADC at 0x40), and a presumed AT24Cxx EEPROM at 0x50.

| Signal | ESP32-S3 GPIO | Notes |
|---|---|---|
| **Shared I²C bus** |||
| I2C_SDA | GPIO 15 | shared by every chip listed above |
| I2C_SCL | GPIO 14 | ↑ |
| **SH8601 / CO5300 AMOLED (QSPI)** |||
| LCD_CS | GPIO 12 | J30 pin 17 |
| LCD_D0 | GPIO 4  | J30 pin 16 |
| LCD_D1 | GPIO 5  | J30 pin 15 |
| LCD_D2 | GPIO 6  | J30 pin 13 |
| LCD_D3 | GPIO 7  | J30 pin 12 |
| LCD_SCK | GPIO 38 | J30 pin 14 |
| LCD_RESET | GPIO 39 | J30 pin 18, active low |
| LCD_TE | GPIO 13 | J30 pin 11, not wired in software yet |
| LCD_VCC | VCC3V3  | J30 pins 22/23, no AXP2101 toggle needed |
| **CST9217 touch (later, not in v1)** |||
| TP_INT | GPIO 21 | J30 pin 30 |
| TP_RESET  | TCA9554 EXIO6 | via I²C expander, not a direct GPIO |
| **AXP2101 PMIC** |||
| AXP_IRQ | (TBC if wired up) | not used in v1 |

> **Termination caveat:** the Waveshare SN65HVD230 module ships with an
> on-board 120 Ω terminator. NMEA 2000 backbones already have terminators
> at both ends, and adding a third creates a 60 Ω parallel termination
> that distorts the signal. **De-solder the 120 Ω resistor on the
> transceiver before connecting it to the bus.** Skipping this step is
> the #1 cause of "everything sometimes works and sometimes doesn't"
> behaviour on a freshly-installed TX.

> **Native USB-CDC quirk:** the AMOLED-1.75-G has no USB-Serial bridge —
> the Type-C goes straight to the ESP32-S3's native USB pins, and the
> chip's USB JTAG/Serial Debug Unit handles reset. There's no DTR/RTS line
> wired to RST, so esptool's default `Hard resetting via RTS pin` is a
> no-op. The TX env's `platformio.ini` uses
> `--before=usb_reset --after=hard_reset --no-stub` plus
> `upload_speed=115200` to work around the post-stub baud-rate-change
> desync on this board. If you change the env, keep those flags.

## ESP32-S3 pin assignments — RECEIVER

No CAN wiring on the RX — it gets its data wirelessly from the TX over
BLE. Only USB-C power and the internal display + touch + I/O expander
that Waveshare pre-wired.

### Pins the Waveshare board wires internally

The display + touch + I/O expander are all pre-routed on the Waveshare PCB —
you don't solder these, but the firmware has to know the assignments. They
live in `src/display/display_pins.h` so the values below and the code can't
drift. If Waveshare ships a new revision with a different pinout, update that
header and rebuild.

> **Chipset note (round 13, 2026-04-23):** our board is the **ST7701 RGB +
> TCA9554** variant of the ESP32-S3-Touch-LCD-2.1, not the ST77916 QSPI +
> CH422G variant. An on-bench I2C scan confirmed 0x15 / 0x20 / 0x51 present
> and 0x24 / 0x38 absent. Separately, the factory demo image that shipped
> on this board displayed a working settings UI on first power-up, so the
> panel + backlight + touch are fully functional; our job is pure driver
> work. The ST7701 RGB pinout below is the round-13 target; the legacy
> ST77916 QSPI table underneath is kept only as a record of what the
> (soon-to-be-deleted) stub driver is wired to.

**Display — ST7701 RGB parallel bus (active target, round 13+)**

The ST7701 is initialised over a 3-wire SPI port, then pixels are pushed
over 16 parallel RGB565 data lines with HSYNC/VSYNC/DE/PCLK timing.

| Signal | ESP32-S3 GPIO | Notes |
|---|---|---|
| RGB_HSYNC | GPIO 38 | horizontal sync |
| RGB_VSYNC | GPIO 39 | vertical sync |
| RGB_DE | GPIO 40 | data enable (HENABLE) |
| RGB_PCLK  | GPIO 41 | pixel clock, 14 MHz |
| R0..R4 | GPIO 46, 3, 8, 18, 17 | red channel (5 bits, LSB→MSB) |
| G0..G5 | GPIO 14, 13, 12, 11, 10, 9 | green channel (6 bits, LSB→MSB) |
| B0..B4 | GPIO 5, 45, 48, 47, 21 | blue channel (5 bits, LSB→MSB) |
| LCD_RST | via TCA9554 IO0 / EXIO1 (not a direct GPIO) | active low |
| LCD_CS | via TCA9554 IO2 / EXIO3 (not a direct GPIO) | 3-wire-SPI CS during init |
| LCD_BL | GPIO 6 (raw, PWM) | 20 kHz / 10-bit via `ledcSetup` + `ledcAttachPin` + `ledcWrite` |
| SPI_SCK (init) | GPIO 2 | 3-wire-SPI clock during ST7701 init only |
| SPI_SDA (init) | GPIO 1 | 3-wire-SPI data during ST7701 init only |

Source: LovyanGFX discussion #630 (working LGFX config for this exact
board, cross-checked against Waveshare product page). Round 15 corrected
the TCA9554 bit-index off-by-one (EXIO1 = bit 0, not bit 1) and moved the
backlight off the expander onto raw GPIO6 — that's what finally turned the
screen on after a dark screen through rounds 13 and 14.

**Display — legacy ST77916 QSPI (stub driver; dead on this board variant)**

| Signal | ESP32-S3 GPIO |
|---|---|
| LCD_CS | GPIO 21 |
| LCD_CLK  | GPIO 40 |
| LCD_D0 | GPIO 46 |
| LCD_D1 | GPIO 45 |
| LCD_D2 | GPIO 42 |
| LCD_D3 | GPIO 41 |
| LCD_RST  | via TCA9554 IO1 (not a direct GPIO) |
| LCD_BL | via TCA9554 IO0 (not a direct GPIO) |

**Shared I2C bus** (TCA9554 I/O expander, CST820 touch, PCF85063 RTC,
plus an unidentified device at 0x6B — probably a QMI8658 IMU — and one
at 0x7E that may be spurious)

| Signal | ESP32-S3 GPIO |
|---|---|
| I2C_SDA | GPIO 15 |
| I2C_SCL | GPIO 7 |

**CST820 capacitive touch**

| Signal | ESP32-S3 GPIO |
|---|---|
| TP_INT | GPIO 4 |
| TP_RST | via TCA9554 IO1 / EXIO2 |
| TP_SDA / TP_SCL | shared I2C bus above |
| TP I2C address | `0x15` |

**TCA9554 I/O expander bit assignments** (addr 0x20, round-15 mapping)

Waveshare's reference software uses 1-indexed `EXIO1..EXIO8` labels that
map to bit positions 0..7 on the TCA9554's P0..P7 lines. Round 13 read
those labels as direct bit numbers and so shifted every signal up by one;
round 15 corrected the mapping after the LGFX #630 config was re-read.

| IO channel (bit) | Waveshare label | Drives | Notes |
|---|---|---|---|
| IO0 | EXIO1 | LCD reset | active low |
| IO1 | EXIO2 | Touch reset | active low |
| IO2 | EXIO3 | LCD CS | drives the panel's 3-wire-SPI CS line during init |
| IO3..IO6 | EXIO4..EXIO7 | (unused on this rev) | no observed effect during the round-12 walking-ones scan, re-interpreted under the round-15 mapping |
| IO7 | EXIO8 | Piezo buzzer | active high — discovered in round 12 when phases B and J beeped (bit 7 is bit 7 in either indexing, so this detection held up) |

Backlight is NOT on this expander — see the `LCD_BL` row in the main
display table for the raw-GPIO6 PWM setup.

> **Revision caveat:** Waveshare has shipped at least two "ESP32-S3-Touch-LCD-2.1"
> BOMs under the same SKU — ST77916 QSPI + CH422G, and ST7701 RGB + TCA9554.
> The in-firmware I2C scan in `src/Ui.cpp` will print which addresses it found
> at boot; cross-check against this table if the screen is dark.

## NMEA 2000 drop cable pinout (Micro-C, male, looking at the pins)

```
      ┌─────────┐
      │  1   2  │     1 = shield / drain  (optional)
      │    5    │     2 = NET-S (+12 V)
      │  3   4  │     3 = NET-C (GND)
      └─────────┘     4 = NET-H (CAN-H)
                      5 = NET-L (CAN-L)
```

Conventional Micro-C drop cable colour code:
- Pin 1 shield — **bare / drain wire**
- Pin 2 NET-S — **red**
- Pin 3 NET-C — **black**
- Pin 4 NET-H — **white**
- Pin 5 NET-L — **blue**

## Power

Do **not** try to power the display board from the NMEA 2000 bus's NET-S pin —
the bus is budgeted for low-power sensors (roughly 1 A total at 12 V across the
whole backbone). Tap the 12 V feed elsewhere (dedicated fused accessory circuit)
for the buck converter. Keep the NMEA 2000 NET-C (ground) and the buck output
ground tied together so the CAN signals share a reference.

## Termination

The NMEA 2000 backbone must have **120 Ω terminators at both ends**. Production
boats usually do already. If your bus is missing one you'll see "everything
sometimes works and sometimes doesn't" behaviour — confirm with a multimeter
(60 Ω across CAN-H/CAN-L with the bus powered off = both terminators present).

## Bench testing before installing on the boat

The receiver's `SIMULATED_DATA` build flag still exists today (in the
`waveshare_esp32s3_touch_lcd_21_sim` env) but its role changes with the
v1.5 split: starting at step 4, the receiver always reads its data from
BLE, and the simulator moves entirely to the transmitter. Until then,
the sim env on the RX remains a self-contained way to develop the UI
without any TX hardware. For bench-testing the BLE path itself before
the boat-side cabling is in place, flash both boards from source and
pair them — the TX simulator (step 3+) feeds the RX over BLE in exactly
the same way the real NMEA 2000 frames eventually will.

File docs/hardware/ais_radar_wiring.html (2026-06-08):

# AIS-radar device — Wiring & Power Guide

Connecting a Wegmatt dAISy 2+ AIS receiver to a Waveshare ESP32-S3-Touch-AMOLED-1.75-G, battery-powered, three wires, no step-up converter.

The short version. The dAISy 2+ runs on 3.3 V (internal switch) and its data pin is 3.3 V logic. The AMOLED board's 8-pin header provides a 3V3 rail and a free GPIO. So the whole connection is three wires from the header to the dAISy AUX header — no 5 V, no step-up converter, no second battery, no 9 V. One 3.7 V LiPo powers everything; the AMOLED's USB-C charges it.

## 1. What you need

Item | Notes
Waveshare ESP32-S3-Touch-AMOLED-1.75-G | The GPS (-G) variant, running the ais-radar firmware. Has an 8-pin header H2 on the back edge.
Wegmatt dAISy 2+ AIS receiver | Has a 6-pin AUX SERIAL header on the rear and an internal 3.3V/5V VCC switch.
3.7 V LiPo, MX1.25 2-pin plug | Plugs into the board's BAT (J1) connector. Powers the whole device.
VHF / AIS antenna | Into the dAISy SMA. Any 162 MHz-capable antenna; see §7. Needed for real reception (not for the bench test).
3 × thin wires + soldering iron | To the H2 header pins (2.54 mm pitch). Dupont jumpers work if you fit a header.

Not needed: the DC-DC step-up (MT3608) — leave it in the drawer. A separate USB cable/powerbank for the dAISy — not used. Series LiPos for 9 V — a misunderstanding; the dAISy never needs 9 V.

## 2. The AMOLED 8-pin header (H2)

On the back edge of the board, silkscreened left-to-right:

IO18   IO17   IO16   RXD   TXD   3V3   GND   VBUS
- IO16 — free GPIO. This is our AIS data input. (IO17/IO18 are taken by the onboard LC76G GPS once you solder its R15/R16 jumpers, so don't use them for AIS.)
- 3V3 — the board's always-on 3.3 V rail (present on battery and USB). Powers the dAISy.
- GND — common ground.
- VBUS — this is the "5 V" pin, but it is USB-only (dead on battery). We do not use it.

## 3. The dAISy 2+ AUX SERIAL header

6-pin header on the rear, silkscreened:

NC   TXD   RXD   GND   VCC   I/O

dAISy pin | Use
TXD | AIS data out (3.3 V logic, 38400 baud). → goes to the ESP IO16.
GND | Ground. → ESP GND.
VCC | Power in when fed externally. → ESP 3V3. Draws ~50 mA.
NC / RXD / I/O | Leave unconnected. (RXD would only be needed to send config to the dAISy; we configure it over USB instead.)

Set the dAISy internal VCC switch to 3.3 V before wiring. It's the small slide switch next to the AUX header marked AUX VCC 5V — 3V3. Powering the dAISy through VCC at 5 V while it's switched to 3.3 V (or vice-versa) can damage it. The TXD/RXD/I/O pins are 3.3 V regardless of this switch.

## 4. Wiring — three connections

# | From — AMOLED H2 | To — dAISy AUX | Wire

1 | GND | GND | Ground — connect first.
2 | 3V3 | VCC | Power (dAISy switch = 3.3 V).
3 | IO16 | TXD | AIS data into the ESP UART RX.

  AMOLED H2                 dAISy 2+ AUX SERIAL
  ---------                 -------------------
  GND   ───────────────────  GND
  3V3   ───────────────────  VCC   (switch: 3V3)
  IO16  ───────────────────  TXD
                             RXD  ─ (unused)
                             I/O  ─ (unused)
                             NC   ─ (unused)

Make and break connections with the AMOLED powered off (battery unplugged and off USB). Live wiring is how 3.3 V GPIOs get fried. Double-check polarity before first power-on.

## 5. Power summary

- Source: one 3.7 V LiPo into the board's BAT connector. The AXP2101 PMIC runs the board from it and steps it to the 3.3 V rail that also feeds the dAISy.
- Charging: plug the AMOLED's USB-C into any charger — the AXP2101 charges the LiPo. No separate charger, no series cells.
- Budget: dAISy ~50 mA at 3.3 V, comfortably within the board's 3.3 V rail (which already drives the AMOLED + GPS). The dAISy's VCC pin is rated 150 mA at 3.3 V, so there's margin.
- Why not the header's VBUS/5 V? It only exists while USB-C is plugged in. On battery it's 0 V, so it can't power the dAISy — hence we use the 3V3 rail instead.

If you ever did want 5 V (e.g. to run the dAISy off its own USB or a future 5 V sensor): the step-up module is fed from the battery or the 3V3 pin and trimmed to 5.0 V with a meter before connecting the load. Not needed for this build.

## 6. dAISy configuration & bench test

- Baud: the dAISy outputs NMEA-0183 AIVDM at 38400 baud by default — the firmware's AIS UART is set to match. No change needed.
- Bench test without an antenna or live traffic: connect the dAISy to a computer over USB, open its serial console, and press T (test mode). It then emits a test AIS message every 5 s. With the wiring above, that target should appear on the AMOLED — proving the full chain before you rely on real reception.
- Real reception needs the VHF antenna and line-of-sight to traffic (see §7).

## 7. Antenna (for real AIS)

- Any antenna tuned to the marine VHF band (~162 MHz) works; a VHF whip (~90 cm) gives far better range than a short "rubber duck". Height + line-of-sight to the water matter most.
- Never connect the dAISy directly to the same antenna as a transmitting VHF radio — it will damage the receiver. Use an active AIS/VHF splitter if sharing.

## 8. Firmware side (for reference)

The ais-radar device firmware opens a hardware UART on IO16 at 38400 baud and feeds the bytes into the salvaged AIVDM decoder (shared/ais/AisTargetDecoder), which now records target lat/lon as well as SOG/COG. No NMEA 2000, no WiFi — the targets are drawn radar-style on the AMOLED and (later) sent to the iOS app over BLE.

esp32-boat · AIS-radar device (v2, ADR-0016) · sources: Waveshare ESP32-S3-Touch-AMOLED-1.75 schematic + docs; Wegmatt dAISy 2+ Manual v2.2 (§4–5). Print this page to PDF (A4).

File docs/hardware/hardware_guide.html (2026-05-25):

# NMEA-converter — Hardware Assembly Guide

Wiring a Waveshare ESP32-C6-LCD-1.47, an SN65HVD230 CAN transceiver, and a Wegmatt dAISy 2+ AIS receiver into a NMEA 0183 → NMEA 2000 bridge with on-screen target list.

## What you'll build

The converter reads !AIVDM sentences from a dAISy 2+ AIS receiver over a 3.3 V TTL UART link, decodes each AIS message, and re-emits it as the correct NMEA 2000 PGN onto the CAN bus through an SN65HVD230 transceiver. The onboard 172×320 ST7789 LCD shows decoded targets with type, speed, course and name; a sailboat icon flashes orange every time a PGN is sent.

## Bill of materials

Item | Notes
Waveshare ESP32-C6-LCD-1.47 (non-touch SKU) | RISC-V single core, 160 MHz, 8 MB flash, 172×320 ST7789 LCD on SPI. USB-C.
SN65HVD230 CAN transceiver breakout | 3.3 V-native CAN transceiver. The Waveshare variant has friendly RX/TX silkscreen labels and a 2-pole screw terminal for CAN_H / CAN_L.
Wegmatt dAISy 2+ AIS receiver | Dual-channel AIS receiver with USB and 3.3 V TTL AUX serial. Powered from its own USB.
Terminated NMEA 2000 backbone cable | Two 120 Ω terminators in place; ~60 Ω end-to-end across CAN_H / CAN_L when unpowered.
Hookup wire | Six conductors, 22–26 AWG. Solid core is fine for breadboard / dev-board headers.
USB-C cable for ESP32-C6 | Powers and programs the converter from your computer.
USB-A cable for dAISy 2+ | Powers the AIS receiver separately.

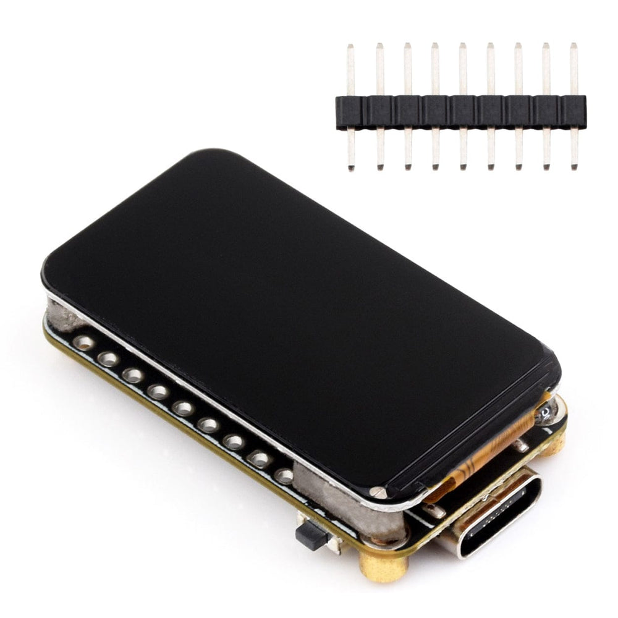
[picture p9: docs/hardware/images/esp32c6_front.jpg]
Waveshare ESP32-C6-LCD-1.47 front


Waveshare ESP32-C6-LCD-1.47, front view. Photo via The Pi Hut product listing.

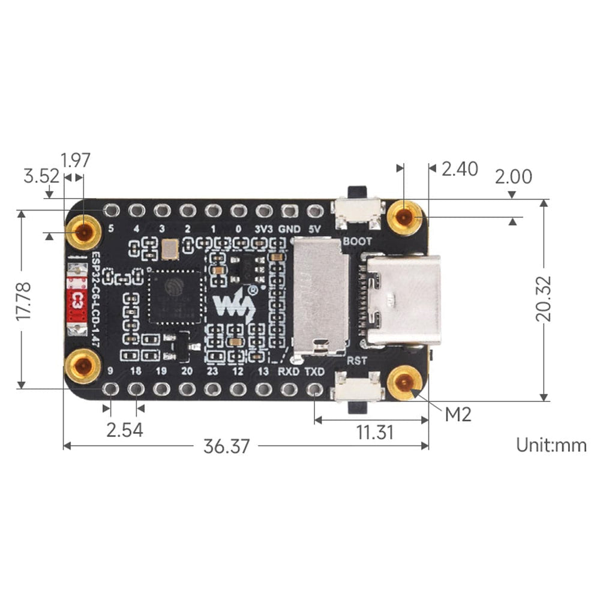
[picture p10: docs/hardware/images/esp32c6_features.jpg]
Waveshare ESP32-C6-LCD-1.47 pin labels


Rear of the same board with silkscreen pin labels. Note GPIO 19 on the bottom row — this is the pin we wire to the dAISy TX. Photo: The Pi Hut.

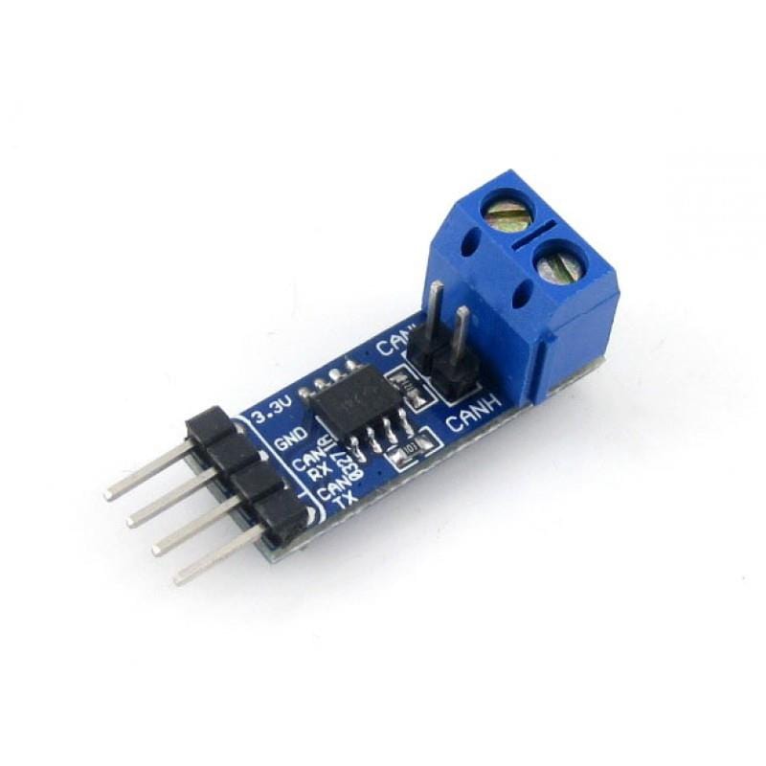
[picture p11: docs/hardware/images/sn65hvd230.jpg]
SN65HVD230 CAN transceiver breakout


SN65HVD230 transceiver (Waveshare). Four-pin header on the left: 3.3V / GND / RX / TX. Two-screw terminal on the right: CANL / CANH. Photo: The Pi Hut.

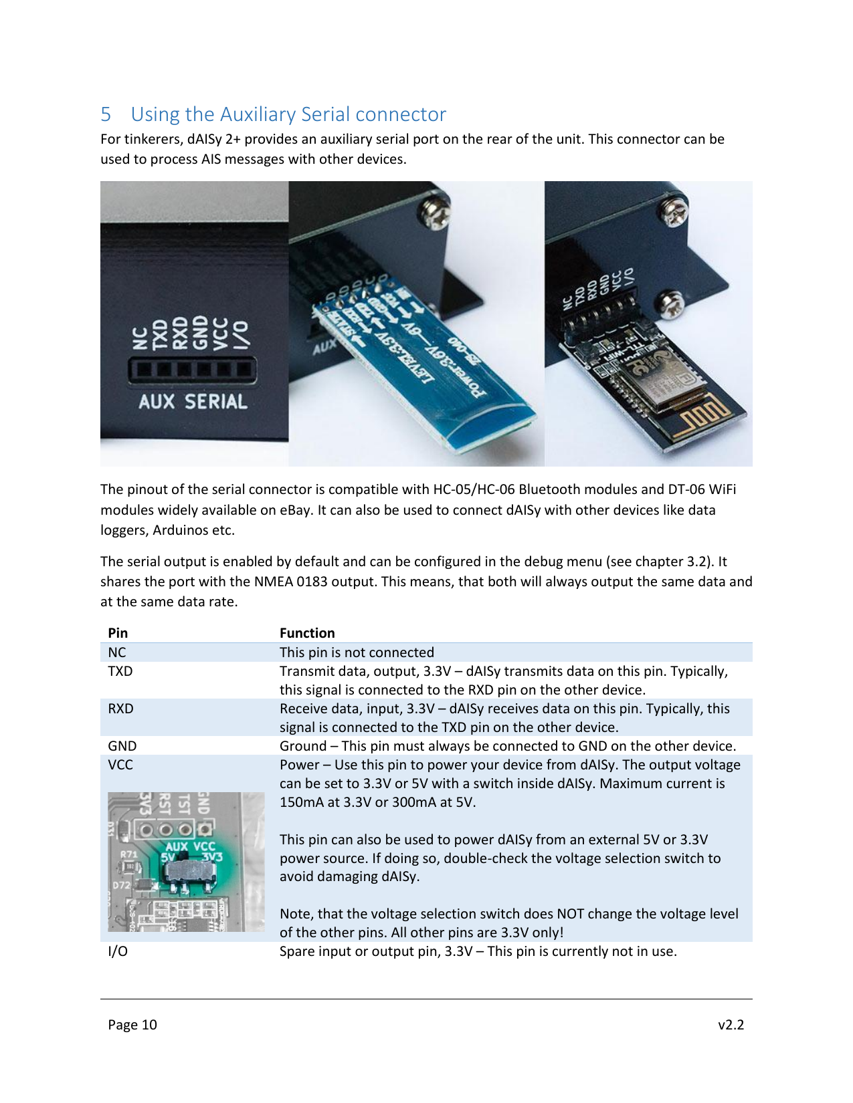
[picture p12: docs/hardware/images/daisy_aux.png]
dAISy 2+ AUX serial connector


dAISy 2+ rear, showing the AUX SERIAL header silkscreen. Pin order: NC TXD RXD GND VCC I/O. Source: Wegmatt dAISy 2+ AIS Receiver Manual v2.2, p.10.

## Pin map at a glance

From | To | Purpose
ESP32-C6 GND | SN65HVD230 GND & dAISy 2+ AUX pin 4 (GND) | Common ground — wire first.
ESP32-C6 3V3 | SN65HVD230 3.3V | Powers the transceiver. Do not use 5V.
ESP32-C6 GPIO 4 | SN65HVD230 TX | CAN frames out of the ESP32, into the transceiver's driver input.
ESP32-C6 GPIO 5 | SN65HVD230 RX | Decoded CAN frames back into the ESP32.
ESP32-C6 GPIO 19 | dAISy 2+ AUX pin 2 (TXD) | NMEA 0183 stream from the AIS receiver into the ESP32's UART1 RX.
SN65HVD230 CANH | Backbone CAN_H | Connect last, after bench tests pass.
SN65HVD230 CANL | Backbone CAN_L | Connect last.

Safe to know up front: the dAISy 2+ manual states explicitly that the AUX TXD signal is 3.3 V regardless of the unit's VCC switch position. No level shifter or voltage divider is needed to feed it into the ESP32-C6.

## Stage-by-stage assembly

Wire in this order. At each stage the worst-case failure mode is harmless. Connections to the live NMEA 2000 bus come last, after the source side is proven on the bench.

### Stage 0 — Sanity check the dAISy TXD level (optional)

1. Power the dAISy 2+ via USB only. No other wires connected.
2. With a multimeter on DC volts, probe TXD ↔ GND on the AUX header.
3. Expect ~3.3 V (idle high). If you see 5 V or 0 V, stop and review the VCC selector switch position via the configuration menu before continuing.

### Stage 1 — Unplug the ESP32 before any wiring

Always make and break connections while the ESP32 is off USB. Live wiring is how 3.3 V GPIOs get fried.

### Stage 2 — Ground first, always

Common ground prevents floating-reference glitches and ESD events on the signal pins.

dAISy AUX pin 4 (GND) ──┐
                         ├── ESP32-C6 GND ── SN65HVD230 GND
                         └── (star or daisy-chain, either is fine)

### Stage 3 — Power the transceiver from the ESP32

ESP32-C6 3V3 ────► SN65HVD230 3.3V

The dAISy keeps its own USB power supply — do not tie its VCC to anything.

If your SN65HVD230 breakout has an Rs pin (slope-rate control), tie it to GND. Most boards have this already set internally; the Waveshare variant pictured does.

### Stage 4 — Signal wires (ESP32 still unplugged)

dAISy AUX pin 2 (TXD)  ────►  ESP32-C6 GPIO19
ESP32-C6 GPIO 4         ────►  SN65HVD230 TX
SN65HVD230 RX            ────►  ESP32-C6 GPIO 5

The RX/TX labels on the Waveshare transceiver are written from the microcontroller's point of view, so they line up one-to-one with the ESP32 pin names. Leave CANH / CANL unconnected for now.

### Stage 5 — Power up and verify the source side

1. Plug the dAISy USB cable (its LED should light).
2. Plug the ESP32 USB-C cable to your computer. The LCD wakes up showing the AIS BRIDGE title at ~40 % brightness, a gray DAISY pill, and a dim boat icon.
3. Within a few seconds of the dAISy emitting its first sentence, the DAISY pill should turn solid green. It latches — once green, stays green.
4. Each decoded AIS message triggers a ~0.4 s orange flash on the boat icon, and the n2k:N counter at the bottom-right increments by one.

If DAISY stays gray for a minute or more with the dAISy USB-powered and antenna connected, that's a source-side wiring or pin-assignment problem to debug before plugging into the bus.

### Stage 6 — Connect to the NMEA 2000 backbone (only after Stage 5)

1. Power the backbone from a 12 V supply. NMEA 2000 transceivers expect 12 V on the bus even if the ESP32 board itself stays on USB.
2. Confirm ~60 Ω across CAN_H / CAN_L on the unpowered backbone (both 120 Ω terminators in place, in parallel).
3. Wire:

SN65HVD230 CANH ────► backbone CAN_H
SN65HVD230 CANL ────► backbone CAN_L
4. Confirm the boat icon flashes and the n2k counter climbs as AIS targets come in. The 0183:M count on the same line is total NMEA 0183 lines seen on UART — a higher number than n2k is normal, because multi-fragment AIS messages take two 0183 lines to make one decoded message.

## Reading the screen

Each target row, left to right by importance:

Column | Meaning
Type | 3-char vessel-type abbreviation, coloured by type (TNK=tanker red, CRG=cargo amber, PAX=passenger blue, FSH=fishing magenta, SAL=sailing green, TUG=tug olive, …).
Kts | Speed over ground in knots. -- when unknown.
Deg | Course over ground in degrees. --- when unknown.
Name | AIS-broadcast vessel name when known, otherwise last 8 digits of MMSI. The whole row is colour-coded by Class-A nav status (green = under way using engine, lime = under sail, orange = at anchor / moored, red = NUC / restricted / aground / SART, blue = engaged in fishing, black = Class B or unknown).

Targets that go silent for more than 5 minutes auto-evict from the list. The footer carries the live-target count, uptime, NMEA 2000 source address, and the running n2k:N - 0183:M message totals.

### Power-saver behaviour

The CPU runs at 80 MHz and the backlight at ~40 % normally. After 5 minutes with no decoded AIS frames the backlight drops to ~5 %; any new AIS sentence or a press of the BOOT button on the C6 board restores it.

## Troubleshooting

Symptom | Likely cause
LCD blank or backlight off | Firmware did not finish boot. Re-flash. Check USB-C cable is data-capable.
DAISY pill stays gray | No NMEA 0183 bytes reaching the ESP32. Check (a) dAISy is powered and antenna is connected; (b) the wire is on dAISy AUX pin 2 (TXD), not RXD; (c) the ESP side lands on GPIO 19, not GPIO 20 or another GPIO; (d) common ground between dAISy and ESP.
Boat icon never flashes | NMEA 0183 sentences arriving but failing to decode. Open a serial monitor — the 0183:M counter should be climbing. If it is but n2k:N stays at zero, the dAISy isn't seeing valid AIS messages (out of range or antenna issue).
n2k counter climbs but boat board sees nothing | Backbone wiring. Verify ~60 Ω across CAN_H/CAN_L with bus powered off, both terminators present, 12 V applied to the backbone.
ESP32 runs hot | Above ambient warm is normal for an ESP at 80 MHz with TFT backlight. If it's uncomfortable to touch, leave the auto-dim alone (it'll save ~30 % power after 5 min).

## Disconnect order

1. Unplug ESP32 USB first.
2. Then any signal wire.
3. Then power (3.3 V).
4. Ground last.

This sequence avoids any case where a signal pin floats above a missing ground.

Generated for the NMEA-converter project. Product photos credited inline are reproduced for the user's personal reference under fair-use. dAISy 2+ AUX header image is from Wegmatt's official manual (v2.2). Pin definitions are taken from the Waveshare ESP32-C6-LCD-1.47 board silkscreen photographed by The Pi Hut.

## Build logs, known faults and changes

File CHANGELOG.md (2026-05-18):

# Changelog

Running revision log for esp32-boat. Maintained automatically by
`scripts/update.sh` — each run prepends a dated entry here before committing,
so this file always matches the sequence of commits on the current branch.

For the authoritative history (including merges, tags, and author info) see
`git log` or <https://github.com/trek2710/esp32-boat/commits/main>.

<!-- entries below, newest first -->
- **2026-05-18** — Round 80b: LC76G I²C bus confirmed dead on the AMOLED-1.75-G variant. Quectel forum thread #27337 (LC76G stuck-state recovery via dummy 0x54/0x58 reads) was the right lead but didn't apply here: the chip's I²C lines aren't routed to the ESP32-side I²C bus. The 'successful write on 0x50' the earlier debugging saw was actually the AT24Cxx EEPROM at 0x50 (visible in the boot scan), not the GPS chip. Reverting kLc76gReadAddr to 0x54 and re-enabling polling confirmed reads from 0x54 hard-NACK every cycle. Code reverted to dormant I²C poll. User confirmed visual inspection of R15/R16 0R jumpers (unpopulated) and ordered a soldering iron. UART drain path on GPIO17/18 already runs every loop iteration; will activate the moment the jumpers are bridged with no code change. Round-80a italic fix (lv_obj_invalidate every UI tick) is folded into this commit too — it was the last loose change.
- **2026-05-17** — Round 80a: AMOLED ghost-pixel workaround on TX. lv_label_set_text() skips invalidation when text is unchanged, so static rows (VBUS: connected, Battery once steady, etc.) sit on the AMOLED long enough for sub-pixel drift to read as italic. Force a full-page invalidation on every updatePages() tick (500 ms). One-line change in src_tx/main.cpp. Resolves the last 'italic' complaint that survived the round-80 font-size and rotation experiments — the cause was screen refresh cadence, not font rendering or panel orientation.
- **2026-05-17** — Round 80: close the BLE bridge end-to-end on the bench (in simulation) and ship steps 2 through 9 of the v1.5 wireless split. Sim PGNs now travel TX -> BLE GATT -> RX -> BoatState -> existing LVGL UI without code paths changing upstream of NmeaBridge. (Step 2) include/BoatBle.h defines the shared wire protocol: one 128-bit service UUID, five NOTIFY characteristics (Wind / GPS / Heading / Depth-Temp / Attitude) plus one WRITE command characteristic. All PDUs packed, each fits the default 23-byte ATT MTU (largest is 13 bytes), valid_mask bitmap per channel so missing fields are explicit instead of sentinel-encoded; fixed-point ints (deg10/kt100/m10/c10/e7) avoid IEEE-754 wire pitfalls; static_asserts pin every struct size so future packing changes fail at compile time. Bit-numbering inside Wind valid_mask is documented: 0=TWA, 1=TWS, 2=TWD, 3=AWA, 4=AWS. (Step 3) TX runs the existing simulator and acts as a NimBLE peripheral advertising as 'esp32-boat-tx'. Per-channel publish cadences match NMEA 2000 spec: GPS / Wind / Heading at 100 ms (10 Hz), Depth / Sea-T at 1 s / 2 s, Attitude at 100 ms. Two notify counters per channel — one resetting at the 5 s serial heartbeat, one monotonic for the on-device rate display. (Step 4) RX-side BLE central: new PIO env [env:waveshare_esp32s3_touch_lcd_21_ble] adds NimBLE-Arduino and -DDATA_SOURCE_BLE=1. NmeaBridge gains a third backend (under #if DATA_SOURCE_BLE) that scans for esp32-boat-tx by name, auto-connects to the first one it sees, subscribes to all five NOTIFY characteristics, and parses each PDU into the existing BoatState setters. On disconnect BoatState::invalidateLiveData() blanks every live field to NaN so the UI renders '—' instead of stale values. Status getters bleConnected() / blePeerMac() / bleRssi() / bleNotifyCount(BleChannel) feed a new 6th 'Communication' page on the RX UI (kNumPages bumped to 6 under DATA_SOURCE_BLE), exposed to Ui via ui::setBleBridge(). flash.sh rx now points at the new env. The _ble env inherits NMEA2000-library from [env]; LDF skips building it at link time because no header is included while DATA_SOURCE_BLE is set. (Step 7) TX status display with five swipe-paged screens — Primary (BLE state, notify rate, GPS, AXP2101 telemetry, uptime), Simulator (six channel state pills), PGN (per-channel measured Hz with category tints), Settings (placeholder), Communication (BLE role / advertised name / service UUID tail / client count / total notifies). Display refresh gated to 500 ms from loop(); BLE callbacks only mutate global state (LVGL isn't thread-safe and NimBLE callbacks fire from the host task). Two ble notify counters per channel so the heartbeat doesn't fight the UI over the reset window. (Step 7b) CST9217 capacitive touch wired via lewisxhe/SensorLib@^0.4.0. The chip's RESET line is behind the TCA9554 GPIO expander on EXIO6 so we pulse it ourselves before calling touch.begin() (SensorLib only sees a 'no reset pin' config). Swipe detector polls every loop tick: touch-down stamps (x0, t0); touch-up emits SWIPE_LEFT / SWIPE_RIGHT iff |dx| >= 40 px AND dt < 1000 ms; vertical strokes and slow drags ignored. 300 ms post-swipe lockout to absorb chip glitches where the CST9217 drops points mid-stroke. SensorLib upstream has a getPoint(0)-without-bounds-check bug in TouchDrvCST92xx.cpp that spams 'Invalid touch point index: 0' on every touch — patched at build time via scripts/patch_sensorlib.py wired in as extra_scripts = pre:scripts/patch_sensorlib.py in [env:nmea2k_tx]. Patch is idempotent (looks for a sentinel comment) and self-healing across libdeps wipes. (Step 8 — dead-end documented) tried bringing up the AMOLED-1.75-G's onboard LC76G GNSS over I²C (length-query / data-fetch protocol against 0x50 / 0x54 / 0x58) and UART (Serial1 on GPIO17/18 at 9600 baud). On this board variant the chip ACKs writes on 0x50 then NACKs every subsequent read; 0x54 / 0x58 never ACK; Serial1 stays silent because the R15/R16 0 Ohm jumpers between LC76G TX/RX and the ESP32 pins aren't populated. Parser plumbing kept in place: gpsI2cFails initialised to its max so the I²C poll is dormant at boot, UART drain runs every loop iteration so soldering R15/R16 will light it up with no code change. GGA parser, NMEA checksum, decimal-minute coord conversion all in the codebase ready to use. (Step 9) TX UI polish: titles 28 pt, rows 24 pt, row pitches widened across all pages, Sim page six 280x38 pill containers coloured by category pastel (Wind/GPS/Boat/Temp from the RX honeycomb palette), PGN page rows tinted by the same category palette so the visual language matches between RX and TX. Initial tap-to-toggle experiment on the Sim page was reverted — the tap detection added a 300 ms swipeLockoutMs after every touch event, which interfered with subsequent swipes; interactive Sim toggles will return when step 6 (RX -> TX command channel) lands. tx-factory-boot.log captured at repo root for reference (the binary backup taken with esptool read-flash isn't committed; .bin is gitignored). Documentation: README Status section rewritten, docs/ROADMAP marks steps 2/3/4/7/7b/9 done with step 5 hardware-blocked, step 6 deferred behind step 5, step 8 marked as a per-board dead-end. New docs/OPENPLOTTER_NMEA2000.md is a self-contained briefing for the next session that picks up step 5 — wiring the SN65HVD230 to a real NMEA 2000 backbone fed by an OpenPlotter / Signal K Raspberry Pi setup. Round 79's original scope (steps 1a-1c — PIO env scaffold, AXP2101 + I²C bus discovery, SH8601/CO5300 AMOLED + LVGL Hello banner, scripts/flash.sh role-aware helper) is folded into this commit since it was never pushed.
- **2026-05-16** — Round 80: close the BLE bridge end-to-end on the bench (in simulation) and ship steps 2 through 9 of the v1.5 wireless split. Sim PGNs now travel TX -> BLE GATT -> RX -> BoatState -> existing LVGL UI without code paths changing upstream of NmeaBridge. (Step 2) include/BoatBle.h defines the shared wire protocol: one 128-bit service UUID, five NOTIFY characteristics (Wind / GPS / Heading / Depth-Temp / Attitude) plus one WRITE command characteristic. All PDUs packed, each fits the default 23-byte ATT MTU (largest is 13 bytes), valid_mask bitmap per channel; fixed-point ints (deg10/kt100/m10/c10/e7) avoid IEEE-754 wire pitfalls; static_asserts pin every struct size. Wind valid_mask bit-numbering: 0=TWA, 1=TWS, 2=TWD, 3=AWA, 4=AWS. (Step 3) TX runs the existing simulator and acts as a NimBLE peripheral advertising as 'esp32-boat-tx'. Per-channel publish cadences match NMEA 2000 spec: GPS / Wind / Heading at 10 Hz, Depth / Sea-T at 1 Hz / 0.5 Hz, Attitude at 10 Hz. Two notify counters per channel — one resetting at the 5 s serial heartbeat, one monotonic for the on-device rate display. (Step 4) RX-side BLE central: new PIO env [env:waveshare_esp32s3_touch_lcd_21_ble] adds NimBLE-Arduino and -DDATA_SOURCE_BLE=1. NmeaBridge gains a third backend that scans for esp32-boat-tx by name, auto-connects, subscribes to all five NOTIFY characteristics, parses PDUs into BoatState setters. On disconnect BoatState::invalidateLiveData() blanks every live field to NaN so the UI renders '—' instead of stale values. Status getters bleConnected() / blePeerMac() / bleRssi() / bleNotifyCount(BleChannel) feed a new 6th 'Communication' page on the RX UI, exposed via ui::setBleBridge(). flash.sh rx now points at the new env. (Step 7) TX status display with five swipe-paged screens — Primary, Simulator, PGN, Settings, Communication. UI refresh gated to 500 ms from loop(); BLE callbacks only mutate global state (LVGL isn't thread-safe and NimBLE callbacks fire from the host task). (Step 7b) CST9217 capacitive touch wired via lewisxhe/SensorLib@^0.4.0. Chip RESET line is behind TCA9554 EXIO6 (pulsed manually before touch.begin). Swipe detector polls every loop tick; touch-up emits SWIPE_LEFT/RIGHT iff |dx| >= 40 px AND dt < 1000 ms; vertical strokes ignored. 300 ms post-swipe lockout for chip glitches. SensorLib upstream getPoint(0) bounds bug patched at build time via scripts/patch_sensorlib.py (extra_scripts hook on the TX env, idempotent, self-healing across libdeps wipes). (Step 8 — dead-end documented) tried bringing up the AMOLED-1.75-G's onboard LC76G GNSS over I²C and UART. On this board variant the chip ACKs writes on 0x50 then NACKs every read; 0x54 / 0x58 never ACK; Serial1 stays silent because the R15/R16 0R jumpers between LC76G TX/RX and the ESP32 pins aren't populated. Parser plumbing kept in place — gpsI2cFails initialised to max so the I²C poll is dormant at boot, UART drain runs every loop iteration so soldering R15/R16 will light it up with no code change. (Step 9) TX UI polish: titles 28 pt, rows 24 pt, row pitches widened, Sim page six 280x38 pill containers coloured by category pastel from the RX honeycomb palette (Wind/GPS/Boat/Temp), PGN page rows tinted by the same palette. Initial tap-to-toggle experiment on the Sim page was reverted — the tap detection added a 300 ms swipeLockoutMs after every touch event, which interfered with subsequent swipes; interactive Sim toggles will return when step 6 (RX → TX command channel) lands. tx-factory-boot.log captured at repo root for reference. Documentation: README Status section rewritten, docs/ROADMAP marks steps 2/3/4/7/7b/9 done with step 5 hardware-blocked, step 6 deferred behind step 5, step 8 marked as a per-board dead-end. New docs/OPENPLOTTER_NMEA2000.md is a self-contained briefing for the next session that picks up step 5 — wiring the SN65HVD230 to a real NMEA 2000 backbone fed by an OpenPlotter / Signal K Raspberry Pi setup. Round 79's original scope (steps 1a-1c — PIO env scaffold, AXP2101 + I²C bus discovery, SH8601/CO5300 AMOLED + LVGL Hello banner, scripts/flash.sh role-aware helper) is folded into this commit since it was never pushed.
- **2026-05-11** — Round 79: split the single-device architecture into a two-board BLE bridge. The existing ESP32-S3-Touch-LCD-2.1 stays as a pure RECEIVER / display; a new ESP32-S3-Touch-AMOLED-1.75-G transmitter board is added (with its own PIO env [env:nmea2k_tx]) that will tap the NMEA 2000 backbone via the SN65HVD230 transceiver (moved off the RX) and publish BoatState over BLE GATT. The simulator moves to the TX side too, so sim and real PGNs flow through the same wireless link to the RX. RX changes will land later; this round is end-to-end bring-up of the new TX hardware. Step plan (1a-1c shipped here): (1a) PIO env scaffold for the AMOLED-1.75-G, src_tx/main.cpp with native USB-CDC serial-only banner — proves build + flash + monitor pipeline on the new chip. (1b) I²C bus probe locates AXP2101 PMIC at 0x34 on SDA=GPIO15 / SCL=GPIO14 (matches the AMOLED-2.06 reference); full-bus scan enumerates the eight on-board chips — ES8311 audio codec @0x18, TCA9554 GPIO expander @0x20, AXP2101 PMIC @0x34, ES7210 mic ADC @0x40, presumed AT24Cxx EEPROM @0x50, PCF85063 RTC @0x51, CST9217 touch @0x5a, QMI8658 IMU @0x6b. XPowersLib reads battery / VBUS / charging live and the loop heartbeat reports them every 5 s. (1c-i) probe loop replaced by hard-coded SDA=15 / SCL=14 from the confirmed bench result, lvgl@8.3.11 added to the env's lib_deps but not yet referenced. (1c-ii) SH8601 AMOLED brought up via Arduino_GFX 1.4.x — using its Arduino_CO5300 driver since the panel chip is pin- and command-compatible with SH8601 and the SH8601 class only landed in Arduino_GFX 1.5.x which requires Arduino-ESP32 3.x (we're on 2.0.16). QSPI pin map from the Waveshare schematic: CS=12 / D0=4 / D1=5 / D2=6 / D3=7 / SCK=38 / RESET=39 (TE=13 reserved, not wired in v1). Panel power runs from VCC3V3 directly via J30 pins 22/23 — no AXP2101 rail to toggle. fillScreen(RED) confirmed the wiring; a 6-pixel column offset on both ends cleans up the right-edge green seam (CO5300 RAM is slightly wider than the visible window). (1c-iii) LVGL 8.3.11 wired to the panel via a flush_cb that hands dirty rectangles to Arduino_GFX::draw16bitRGBBitmap; one 466×466 RGB565 buffer in PSRAM (~434 KB); a centred 'Hello, transmitter' label is the first LVGL render. loop() now non-blocking — lv_tick_inc + lv_timer_handler every 5 ms, the serial heartbeat runs on a 5 s gate. Step 1c-iv (drop the 4 s startup delay now that the AMOLED itself is the boot diagnostic) deferred. Plus: new scripts/flash.sh — TX/RX role-aware build+flash+monitor helper that reads the connected chip's MAC via esptool, registers each board per role on first use (scripts/.devices.conf, gitignored), and refuses to flash if a future run sees a different MAC under the same role. After flash, polls /dev/cu.usbmodem* every 250 ms until the chip re-enumerates so pio device monitor catches the boot banner cleanly. platformio.ini [env:nmea2k_tx]: separate from the RX envs via build_src_filter = -<*> +<../src_tx/*>; lib_deps narrowed to XPowersLib + LVGL + Arduino_GFX ~1.4.0 only; upload_flags --before=usb_reset --after=hard_reset --no-stub + upload_speed=115200 (the AMOLED board has no UART bridge so esptool's RTS reset is a no-op; the post-stub baud-rate handshake at 921600 / 460800 desyncs reliably over native USB-CDC; --no-stub at the ROM bootloader rate sidesteps the desync). Native USB-CDC race in setup() addressed with an unconditional 4 s delay before any Serial.println so pio monitor reliably catches the banner. Documentation updated for the new architecture: README, docs/ROADMAP (new v1.5 wireless-split section + adjusted non-goal on bidirectional writes since the BLE command channel will land in step 6), docs/BOM (new TX board entry, transceiver note moves), docs/WIRING (TX section added with the new pin map). Factory firmware boot log captured to tx-factory-boot.log for reference; the binary backup the user took with esptool read-flash isn't committed (.bin already gitignored).
- **2026-05-11** — Round 79: split the single-device architecture into a two-board BLE bridge. The existing ESP32-S3-Touch-LCD-2.1 stays as a pure RECEIVER / display; a new ESP32-S3-Touch-AMOLED-1.75-G transmitter board is added (with its own PIO env [env:nmea2k_tx]) that will tap the NMEA 2000 backbone via the SN65HVD230 transceiver (moved off the RX) and publish BoatState over BLE GATT. The simulator moves to the TX side too, so sim and real PGNs flow through the same wireless link to the RX. RX changes will land later; this round is end-to-end bring-up of the new TX hardware. Step plan (1a-1c shipped here): (1a) PIO env scaffold for the AMOLED-1.75-G, src_tx/main.cpp with native USB-CDC serial-only banner — proves build + flash + monitor pipeline on the new chip. (1b) I²C bus probe locates AXP2101 PMIC at 0x34 on SDA=GPIO15 / SCL=GPIO14 (matches the AMOLED-2.06 reference); full-bus scan enumerates the eight on-board chips — ES8311 audio codec @0x18, TCA9554 GPIO expander @0x20, AXP2101 PMIC @0x34, ES7210 mic ADC @0x40, presumed AT24Cxx EEPROM @0x50, PCF85063 RTC @0x51, CST9217 touch @0x5a, QMI8658 IMU @0x6b. XPowersLib reads battery / VBUS / charging live and the loop heartbeat reports them every 5 s. (1c-i) probe loop replaced by hard-coded SDA=15 / SCL=14 from the confirmed bench result, lvgl@8.3.11 added to the env's lib_deps but not yet referenced. (1c-ii) SH8601 AMOLED brought up via Arduino_GFX 1.4.x — using its Arduino_CO5300 driver since the panel chip is pin- and command-compatible with SH8601 and the SH8601 class only landed in Arduino_GFX 1.5.x which requires Arduino-ESP32 3.x (we're on 2.0.16). QSPI pin map from the Waveshare schematic: CS=12 / D0=4 / D1=5 / D2=6 / D3=7 / SCK=38 / RESET=39 (TE=13 reserved, not wired in v1). Panel power runs from VCC3V3 directly via J30 pins 22/23 — no AXP2101 rail to toggle. fillScreen(RED) confirmed the wiring; a 6-pixel column offset on both ends cleans up the right-edge green seam (CO5300 RAM is slightly wider than the visible window). (1c-iii) LVGL 8.3.11 wired to the panel via a flush_cb that hands dirty rectangles to Arduino_GFX::draw16bitRGBBitmap; one 466×466 RGB565 buffer in PSRAM (~434 KB); a centred 'Hello, transmitter' label is the first LVGL render. loop() now non-blocking — lv_tick_inc + lv_timer_handler every 5 ms, the serial heartbeat runs on a 5 s gate. Step 1c-iv (drop the 4 s startup delay now that the AMOLED itself is the boot diagnostic) deferred. Plus: new scripts/flash.sh — TX/RX role-aware build+flash+monitor helper that reads the connected chip's MAC via esptool, registers each board per role on first use (scripts/.devices.conf, gitignored), and refuses to flash if a future run sees a different MAC under the same role. After flash, polls /dev/cu.usbmodem* every 250 ms until the chip re-enumerates so pio device monitor catches the boot banner cleanly. platformio.ini [env:nmea2k_tx]: separate from the RX envs via build_src_filter = -<*> +<../src_tx/*>; lib_deps narrowed to XPowersLib + LVGL + Arduino_GFX ~1.4.0 only; upload_flags --before=usb_reset --after=hard_reset --no-stub + upload_speed=115200 (the AMOLED board has no UART bridge so esptool's RTS reset is a no-op; the post-stub baud-rate handshake at 921600 / 460800 desyncs reliably over native USB-CDC; --no-stub at the ROM bootloader rate sidesteps the desync). Native USB-CDC race in setup() addressed with an unconditional 4 s delay before any Serial.println so pio monitor reliably catches the banner. Documentation updated for the new architecture: README, docs/ROADMAP (new v1.5 wireless-split section + adjusted non-goal on bidirectional writes since the BLE command channel will land in step 6), docs/BOM (new TX board entry, transceiver note moves), docs/WIRING (TX section added with the new pin map). Factory firmware boot log captured to tx-factory-boot.log for reference; the binary backup the user took with esptool read-flash isn't committed (.bin already gitignored).
- **2026-05-11** — Round 78: replace the round-54 PGN log (page 2) with a 19-hex honeycomb of fixed-slot PGN tiles. 3 rings (1 + 6 + 12), pointy-top hexes side=50 / dx=43 painted onto a single 480x480 PSRAM canvas centred at (240,240); 19 hex polygons inscribed in radius ~218 inside the panel's 240-radius bezel. Each tile carries three labels (NAME font 14 / VALUE font 20 / FREQ font 14) with category palette: Wind (0xC6E0F5 / flash 0x0D47A1 / dim 0xE3F0FA) clusters top, GPS+compass (0xDCD0EC / 0x4A148C / 0xEEE8F6) right, Boat-direction/depth/heel (0xCFE8C9 / 0x1B5E20 / 0xE7F4E4) centre+bottom, Temperatures (0xF5D7B9 / 0xBF360C / 0xFAEBDC) left. Slot states: Empty (no data ever, grey 0xE0E0E0 + muted text 0xBDBDBD), Active (data within 10x its observed update interval — full pastel + black/grey text), Dim (data once received but channel silent past 10x interval — pale pastel + dim 0x9E9E9E text), with a 400 ms text-only flash to the saturated category tone on every value update. EMA-tracked Hz per tile renders at 1 dp below 10 Hz, 0 dp above; gaps >30 s skip the EMA so page-was-hidden discontinuities don't poison the rate. New BoatState fields: air_temp_c + air_temp_last_ms with setAirTemp(); sim publishes outdoor temp every 2 s as 18 + 2*sin(t*0.05) °C; production handler for PGN 130316 OutsideTemperature routed to the same setter. ENG-T / OIL-T / HEEL / PITCH / ROT / RUD slots reserved in the layout but not wired to fields yet — those tiles stay grey until real hardware appears. Page 2 entry point renamed buildHoneycombPage / refreshHoneycomb / hc_pg; pages[2] now points at hc_pg.root. Plus a small refactor so the honeycomb's measured Hz matches NMEA 2000 spec rates: setDepth(depth, water_temp_c) split into setDepth(depth) + setSeaTemp(temp), new water_temp_last_ms field, sim now publishes depth at 1 Hz and sea temp at 0.5 Hz independently (was both at 1 Hz), and the PGN 128267 / 130316-Sea handlers updated to call the right setter — SEA-T hex now reads 0.5 Hz instead of an incorrect 1.0 Hz.
- **2026-05-10** — Round 78: replace the round-54 PGN log (page 2) with a 19-hex honeycomb of fixed-slot PGN tiles. 3 rings (1 + 6 + 12), pointy-top hexes side=50 / dx=43 painted onto a single 480x480 PSRAM canvas centred at (240,240); 19 hex polygons inscribed in radius ~218 inside the panel's 240-radius bezel. Each tile carries three labels (NAME font 14 / VALUE font 20 / FREQ font 14) with category palette: Wind (0xC6E0F5 / flash 0x0D47A1 / dim 0xE3F0FA) clusters top, GPS+compass (0xDCD0EC / 0x4A148C / 0xEEE8F6) right, Boat-direction/depth/heel (0xCFE8C9 / 0x1B5E20 / 0xE7F4E4) centre+bottom, Temperatures (0xF5D7B9 / 0xBF360C / 0xFAEBDC) left. Slot states: Empty (no data ever, grey 0xE0E0E0 + muted text 0xBDBDBD), Active (data within 10x its observed update interval — full pastel + black/grey text), Dim (data once received but channel silent past 10x interval — pale pastel + dim 0x9E9E9E text), with a 400 ms text-only flash to the saturated category tone on every value update. EMA-tracked Hz per tile renders at 1 dp below 10 Hz, 0 dp above; gaps >30 s skip the EMA so page-was-hidden discontinuities don't poison the rate. New BoatState fields: air_temp_c + air_temp_last_ms with setAirTemp(); sim publishes outdoor temp every 2 s as 18 + 2*sin(t*0.05) °C; production handler for PGN 130316 OutsideTemperature routed to the same setter. ENG-T / OIL-T / HEEL / PITCH / ROT / RUD slots reserved in the layout but not wired to fields yet — those tiles stay grey until real hardware appears. Page 2 entry point renamed buildHoneycombPage / refreshHoneycomb / hc_pg; pages[2] now points at hc_pg.root. Plus a small refactor so the honeycomb's measured Hz matches NMEA 2000 spec rates: setDepth(depth, water_temp_c) split into setDepth(depth) + setSeaTemp(temp), new water_temp_last_ms field, sim now publishes depth at 1 Hz and sea temp at 0.5 Hz independently (was both at 1 Hz), and the PGN 128267 / 130316-Sea handlers updated to call the right setter — SEA-T hex now reads 0.5 Hz instead of an incorrect 1.0 Hz.
- **2026-05-10** — Round 78: replace the round-54 PGN log (page 2) with a 19-hex honeycomb of fixed-slot PGN tiles. 3 rings (1 + 6 + 12), pointy-top hexes side=50 / dx=43 painted onto a single 480x480 PSRAM canvas centred at (240,240); 19 hex polygons inscribed in radius ~218 inside the panel's 240-radius bezel. Each tile carries three labels (NAME font 14 / VALUE font 20 / FREQ font 14) with category palette: Wind (0xC6E0F5 / flash 0x0D47A1 / dim 0xE3F0FA) clusters top, GPS+compass (0xDCD0EC / 0x4A148C / 0xEEE8F6) right, Boat-direction/depth/heel (0xCFE8C9 / 0x1B5E20 / 0xE7F4E4) centre+bottom, Temperatures (0xF5D7B9 / 0xBF360C / 0xFAEBDC) left. Slot states: Empty (no data ever, grey 0xE0E0E0 + muted text 0xBDBDBD), Active (data within 10x its observed update interval — full pastel + black/grey text), Dim (data once received but channel silent past 10x interval — pale pastel + dim 0x9E9E9E text), with a 400 ms text-only flash to the saturated category tone on every value update. EMA-tracked Hz per tile renders at 1 dp below 10 Hz, 0 dp above; gaps >30 s skip the EMA so page-was-hidden discontinuities don't poison the rate. New BoatState fields: air_temp_c + air_temp_last_ms with setAirTemp(); sim publishes outdoor temp every 2 s as 18 + 2*sin(t*0.05) °C; production handler for PGN 130316 OutsideTemperature routed to the same setter. ENG-T / OIL-T / HEEL / PITCH / ROT / RUD slots reserved in the layout but not wired to fields yet — those tiles stay grey until real hardware appears. Page 2 entry point renamed buildHoneycombPage / refreshHoneycomb / hc_pg; pages[2] now points at hc_pg.root.
- **2026-05-09** — Round 77: three small follow-ups to the round-76 Main-display overhaul. (1) AWS readout added below BSPD inside the hull, using the same DEPTH-style subtitle/value/unit triple ('AWS' / value / 'kn') at offsets y=42/62/80 from widget centre. New main_pg.aws_lbl field, populated from s.aws in refreshMain. (2) Top '0' manual mirrored label reverted from white (round 75) back to black: the round-75 white was needed because the label sat on the black bow-zone wedge at radius ~205, but round 76 pushed the wedge out to the bezel (r_mod=0, radii 214..240); the manual labels at radius 188 are now well inside the wedge ring on white bg, so all 12 labels go back to black. (3) Apparent-wind cone (struct field twd_arrow, drives s.awa since round 76) tip pushed outward: kConeH 182→215 with kConeVisibleBase unchanged at 117, so the visible cone stays the same length — only the invisible pivot padding grows, translating the whole cone outward without rescaling. Tip-to-pivot distance is now 214, landing exactly on the wedge inner edge.
- **2026-05-08** — Round 76: Main display visual overhaul plus wind-indicator rebinding. (1) kCompassSize 460→480 so the dial fills the round panel; r_mod on all four no-go arcs goes -22→0 so the wedges are flush to the bezel (user: 'the wedge is not at the border of the screen anymore'). (2) Cone (struct field still twd_arrow for diff-min) reshaped: kConeW 50→25, kConeH 140→182 (+30%), kConeVisibleBase 90→117. Inner colour blue→yellow. Re-bound to s.awa in refreshMain (previously s.twd) — user named this 'the apparent wind direction arrow'. (3) Outer-rim triangle (target_marker) gets kTgtH 230→241 so the tip sits at screen radius 240 — 'fully at the edge'. Colour blue→yellow. Re-bound from the round-55 hardcoded kTargetCourse=60° stub to s.twd in refreshMain — user named this 'the true wind triangle indicator'. (4) BSPD readout moved from the stern offset (0,145) to the centre (0,0) with the same DEPTH-style subtitle/value/unit triple ('BSPD' / value / 'kn'). Sits inside the new flat-aft hull; black-on-white reads cleanly through the unfilled hull interior. (5) Boat hull redrawn: recentred from x=230→x=240 to match the wider widget; widest body half-width 50→40 px (20% slimmer); flat horizontal aft from (210,370)→(270,370), 60 px wide vs. the original ~10 px (= 50 px wider, as specified). (6) Heading box widened 64→100 px; new headingCardinal() helper maps degrees-true to an 8-point cardinal abbreviation (N/NE/E/SE/S/SW/W/NW); refreshMain formats the readout as '038° NE'.
- **2026-05-08** — Round 75: Main page double-label fix + second adjustable variable (no-stop angle) + Settings page restructure. (1) Round-74 hide-by-colour-match trick (white text on white bg) wasn't fully suppressing the lv_meter auto-generated 0/30/60/.../330 labels — anti-aliased glyph edges leaked through as faint shapes overlaying the manual mirrored 0..180 labels, giving a 'double label' look on the dial. Switched to text-opa = LV_OPA_TRANSP on LV_PART_TICKS so LVGL skips drawing the auto labels entirely. (2) The top '0' manual label sits on the new black bow-zone wedge (default ±20° spans both sides of 0°), so a black '0' was invisible against the black bar — special-cased i==0 in the manual-label loop to white; the other 11 mirrored labels stay black on the white dial. (3) Added a second persisted variable, g_nostop_deg (default 90, clamp 30..170, NVS key 'nostop_deg'), controlling the OUTER edge of the red/green close-hauled bars. applyNogoSectors now uses both H = g_nogo_half_deg and S = g_nostop_deg: port red [360-S..360-H], port black [360-H..360], stbd black [0..H], stbd green [H..S]. (4) Settings page restructured: header + two stepper rows, each [-] [value box] [+] horizontally with subtitles WIND NO-GO ZONE / NO-STOP ANGLE. 50×50 buttons + 88×50 bordered value box, all inside the 144..335 widget-pass-through band. Captureless lambdas hardcode the variable each pair of buttons edits, so no user_data plumbing. Both rows persist via the same saveNogoToPrefs() (single open/close writes both keys).
- **2026-05-08** — Round 74: Main display flipped to white background + black lines (was black/white) per user spec, with a four-arc no-go zone across the bow — port red [270..340°], port black [340..360°], stbd black [0..20°], stbd green [20..90°] at the default ±20° half-angle. The half-angle is now adjustable from a new fifth page, Settings (pages[4] in the swipe order), via two big 70×70 -/+ buttons positioned inside the 144..335 widget-pass-through band so taps don't trigger page nav. Range clamped 0..89°; persisted to NVS via Preferences ('boat' namespace, key 'nogo_half') so the setting survives a power cycle. Touched colours on the Main page: dial bg, ticks, manual mirrored degree labels, hull line, TWD cone outer border, BSPD/DEPTH/HEEL labels and their grey subtitles, and the rotating inner-ring labels (the green N marker is unchanged). Other pages (Wind, Sim, Debug) remain black-on-white-text utility screens. Ships alongside round 73 (NMEA 2000 spec-cadence simulator publishing) plus round 72 (touch-zones + sim toggle buttons) and round 71 (monitor cleanup), which had not been pushed yet — single commit covers all four under this round-74 message.
- **2026-05-06** — Round 73: simulator publish cadence now matches the NMEA 2000 spec transmission intervals instead of firing every loop tick (~30 Hz). Per-channel rates: GPS position / Wind / Heading at 100 ms (10 Hz); STW / Depth at 1000 ms (1 Hz). Implemented as static last_*_pub_ms timers in simulateTick(); layered on top of the round-72 channel-enable gating. Sources cross-checked: canboat, Maretron, Garmin PGN docs. Ships alongside round-72 (touch-zones + sim toggle buttons) and the round-71 monitor cleanup, which had not been pushed yet. Round-72 recap: tap nav fires only in the outer 30 % on each side; middle 40 % passes through to LVGL widgets so per-page controls are usable; sim page has five large GREEN/RED toggle buttons (GPS / Wind / Heading / STW / Depth) in the middle band — clicking flips g_sim_enables, which now skips both the setter AND the matching PGN log entries. Round-71 recap: removed cst820 heartbeat + raw-touch + touch-DOWN logs, collapsed touch-UP to one-line verdicts, gated boot GPIO/I2C scans behind kVerboseBoot=false.
- **2026-05-06** — Round 72: touch-zones + sim-channel toggle buttons (also rolls in the round-71 monitor cleanup that never shipped). Tap nav now only fires in the outer 30 % on each side (x<144 or x≥336 on the 480-wide panel); the middle 40 % passes through to LVGL widgets so per-page controls are usable again. Swipes still navigate from anywhere. Sim page gains five large channel toggle buttons — GPS / Wind / Heading / STW / Depth — stacked in the middle band so tapping them doesn't trigger nav. Each button is GREEN when the channel is publishing, RED when silenced; clicking flips the matching g_sim_enables flag and re-paints the bg. Disabling a channel skips the corresponding state_.set*() call AND suppresses the matching PGN log entries, so the Debug page also shows the channel going silent. Variation lookup is tied to the heading channel. Round-71 carry-over: removed the cst820 5 s heartbeat, the per-touch rate-limited raw-buffer log, and the touch-DOWN line; collapsed the verbose touch-UP line into a single concise verdict ('[ui] tap left → prev page' / '[ui] tap right → next page' / '[ui] tap middle → widget' / '[ui] swipe → ... page'); gated the boot GPIO/I2C diagnostic blocks behind kVerboseBoot=false.
- **2026-05-06** — Round 72: touch-zones + sim-channel checkboxes (also rolls in the round-71 monitor cleanup that never shipped). Tap nav now only fires in the outer 30 % on each side (x<144 or x≥336 on a 480-wide screen); the middle 40 % passes through to LVGL widgets so per-page controls are usable again. Swipes still navigate from anywhere. Sim page gains five channel checkboxes — GPS / Wind / Heading / STW / Depth — laid out in the middle band so tapping them doesn't trigger nav; unchecking a box stops the corresponding state_.set*() call AND suppresses the matching PGN log entries so the Debug page reflects the channel going silent. Variation lookup is tied to the heading channel. Round-71 carry-over: removed cst820 5 s heartbeat, the per-touch rate-limited raw-buffer log, and the touch-DOWN line; collapsed the verbose touch-UP line into a single concise verdict ('[ui] tap left → prev page' / '[ui] tap right → next page' / '[ui] tap middle → widget' / '[ui] swipe → ... page'); gated the boot GPIO/I2C diagnostic blocks behind kVerboseBoot=false.
- **2026-05-04** — Round 71: clean up monitor noise now that tap nav is shipped. Removed cst820 5 s heartbeat block (was for the round-66/67 interrupt experiment, no longer needed), removed the per-touch rate-limited [cst820] touch raw-buffer log, removed the [ui] touch DOWN line. Collapsed the verbose [ui] touch UP line (dx/dy/held/[gap]/[lift]/SWIPE/ignored postfix) into a single concise verdict per touch — '[ui] tap left → prev page' or '[ui] tap right → next page', or '[ui] swipe → ... page' on the rare cases the chip cooperates. Gated the boot-time GPIO/I2C diagnostic blocks behind kVerboseBoot=false (flip true to re-enable for any future board re-diagnosis).
- **2026-05-04** — Round 70: ship tap fallback. Round-69 bench was 0/12 — the chip's silent-touch behaviour on isolated touches is not changeable by any register tweak we've found across rounds 65-69. Accepting the hardware floor. Tap fallback in touchReadCb's release path: when no chip gesture fired AND dx/dy doesn't qualify as a swipe, use press_x for half-screen nav (left half → previous page, right half → next page). Same direction mapping as swipes, so user-visible behaviour stays consistent whether the chip cooperated or not. Swipe paths (chip gesture, dx/dy qualifier) untouched — they still fire when the chip happens to play along. Net result: every touch reliably navigates.
- **2026-05-04** — Round 69: chip-keepalive experiments. Round-68 bench (one swipe per heartbeat-spaced touch) was 0/9 — the chip emits one coord at press and goes silent for the entire touch when isolated by several seconds of idle, despite DisAutoSleep being written. Two changes: (1) DisAutoSleep value 0xFF → 0xFE (the canonical fbiego/CST816S library value, in case the chip is picky), (2) periodic 500 ms poke of register 0xA7 (chip ID) in cst820::read() to keep the I2C bus active and prevent the chip from settling into deep idle between touches. If the chip still goes silent on isolated touches after this, we accept the hardware limit and ship tap fallback as round 70.
- **2026-05-04** — Round 68: revert the round-66 IRQ gate; restore polling. Round-67 heartbeat trace proved the chip is not pulsing TP_INT on touch events on this hardware (irqs=4 at boot from startup chatter, then locked at 4 forever despite touches). With the gate in place, touch was completely dead. Drop the s_irq_pending check in cst820::read() so it does the I2C round-trip every tick again; this restores round 65's working state (5/7 swipes recognised). Keep the ISR wired, the INPUT_PULLUP, and the heartbeat — they're cheap and they'll instantly show if some future IRQ_CTL experiment ever gets the chip to fire touch IRQs.
- **2026-05-04** — Round 67: TP_INT pinMode INPUT → INPUT_PULLUP, plus a 5 s heartbeat log of the IRQ count and live TP_INT level. Round 66 wired up the FALLING-edge ISR but the boot GPIO scan (line 'gpio 4 : LOW (tied down — device?)') showed TP_INT idles LOW with plain INPUT — no external pullup on this board's trace, so a FALLING edge could never happen and the ISR never fired. Touch died completely. INPUT_PULLUP enables the ESP32-S3's internal pullup so the line idles HIGH and the chip's open-drain pulse-LOW creates a real falling edge. The heartbeat surfaces this kind of misconfiguration as a stuck irqs=0/TP_INT=LOW line instead of as silent dead touch.
- **2026-05-04** — Round 66: switch CST820 reads to interrupt-driven. Round-65 bench showed chip silence ~30% of the time even with IRQ_CTL=0x70 set. Every working CST816S/CST820 driver in the wild (fbiego, ESPHome, mmMicky/TouchLib, the LVGL gold-standard pattern) reads on TP_INT falling-edge — we were the polling outlier. ISR on GPIO 4 sets a flag and bumps an IRQ counter; cst820::read() bails early when the flag is clear instead of doing an I2C round-trip against stale chip state. Existing touch-log line now reports irqs=N so the bench trace shows TP_INT firing rate per touch.
- **2026-05-04** — Round 65: write IRQ_CTL=0x70 to register 0xFA (EnTouch | EnChange | EnMotion) at boot and refresh every 2 s. Round-64 bench showed the chip going silent mid-touch even with MotionMask=0x06 set — many gestures had dx=0 held=0ms because the chip simply stopped updating its sample registers ~200 ms into a slow touch. ESPHome's production cst816 driver writes this exact register/value at setup; without it, the chip's internal sample-update pipeline isn't gated on motion and falls into tap-detection silence. Also added a one-time read of register 0xA7 at boot to log the chip ID (CST820 = 0xB7) so any sibling-chip variant on a future board shows up in the trace.
- **2026-05-04** — Round 64: capture lift-event coords and post-lift gesture. Round-63 bench showed three swipe attempts where the chip went silent through the entire touch — neither streamed coords nor fired a gesture during the press window. cst820::read() now (a) returns true on event=0x01 lift events with the chip's final coord (round 58 used to discard these) and (b) exposes the gesture byte even on no-finger ticks. touchReadCb declares release immediately on lift_event (skips the 1.2 s hold-through gap, dx/dy reconstruction gets the real end-of-swipe coord) and runs the chip-gesture short-circuit on every tick (catches gesture codes the chip latches after lift). Release log now tags [lift] vs [gap] so we can see the source on the bench.
- **2026-05-04** — Round 63: trust the CST820's onboard gesture engine. Round-62 trace showed the chip emitting gesture=0x04 (slide) mid-swipe while our software was still trying to reconstruct the gesture from coordinates the chip had stopped streaming. cst820::read() now returns the chip's gesture byte; touchReadCb fires the page change immediately on chip codes 0x03/0x04 and falls back to the dx/dy state machine otherwise. Also dropped kSwipeMinPx 40 → 30 to catch the dx≈31-px swipe class round 62 missed.
- **2026-05-04** — Round 62: dropped kSwipeMaxMs duration check from the swipe state machine. Slow gestures were being rejected even with held_ms reporting the real finger-down time. Now any release with |dx| >= 40 px and |dx| > |dy| fires a page change regardless of how long the touch lasted.
- **2026-04-29** — Round 62: round-61 trace showed valid swipes still being rejected. The kSwipeMaxMs=3000 duration check was the culprit — a clear -191 px swipe got rejected with held=10521 ms because last_real_press_ms-press_ms (the round-61 metric) only counts the chip's actively-streaming portion, and the CST820's streaming duration is wildly inconsistent (32 ms to 10+ s on objectively similar gestures). Dropped the duration check from the qualifier. If the chip reported motion >= kSwipeMinPx with |dx|>|dy|, that's a swipe — full stop. Long lazy holds without motion still get rejected (dx ≈ 0). kSwipeMaxMs constant kept around for the diagnostic log line.
- **2026-04-29** — Round 61: round-60 trace identified the chip's tap-detection window — every dx=0 failure had held≈455 ms = ~205 ms of CST820 activity + 250 ms debounce. The chip stops streaming coords during its tap-detection window when the user presses without immediate motion; with kHoldThroughGapMs=250 the state machine declared release before the chip could resume. Bumped kHoldThroughGapMs 250 → 1200 ms (covers press-pause-move). Also fixed held_ms: was now-press_ms (included debounce wait), now last_real_press_ms-press_ms (actual finger-down time) so the 1200 ms gap doesn't eat into the kSwipeMaxMs budget.
- **2026-04-29** — Round 61: round-60 trace identified the chip's tap-detection window — every dx=0 failure had held≈455 ms = ~205 ms of CST820 activity (tap-detection window) + 250 ms debounce. When the user presses without immediate motion the chip stops streaming coords while it decides if it's a tap; with kHoldThroughGapMs=250 our state machine declared release before the chip could resume. Bumped kHoldThroughGapMs 250 → 1200 ms — generous ride-through that covers press-pause-move gestures. Also fixed held_ms computation: was now-press_ms (included debounce wait), now last_real_press_ms-press_ms (actual finger-down time). Otherwise the new 1200 ms gap would eat 1.2 s out of every swipe's kSwipeMaxMs=3000 ms budget.
- **2026-04-29** — Round 60: round-59 working but finicky — slow deliberate swipes hit kSwipeMaxMs=1500 cap (a 2245 ms one rejected even with -307 px motion). Bumped kSwipeMaxMs 1500 → 3000 ms; kSwipeMinPx 50 → 40 px (8 % of screen). Also: first touch after long idle still occasionally dropped to dx=0 dy=0 — chip defaulting MotionMask back to 0 during sleep. Added 2 s periodic re-write of 0xEC=0x06 from inside Cst820::read() so any chip that lost config gets it back before the next touch.
- **2026-04-29** — Round 60: round-59 trace showed swipes still finicky — slow deliberate ones were 860-2245 ms, with the 2245 ms case rejected because it exceeded kSwipeMaxMs=1500. Bumped kSwipeMaxMs 1500 → 3000 ms so deliberate slow swipes qualify, and kSwipeMinPx 50 → 40 px so any unmistakable finger drag qualifies. Also: the very first touch after a long idle still occasionally dropped to dx=0 dy=0 — symptomatic of the CST820 defaulting MotionMask back to 0 during an auto-sleep/wake cycle. Added a 2 s periodic re-write of MotionMask (0xEC=0x06) from inside Cst820::read() so any chip that lost config gets it back before the next user touch.
- **2026-04-29** — Round 59: ROOT CAUSE — every swipe failure had dx=0 dy=0 held=455 ms exactly. The CST816S/CST820 family ships with continuous-slide reporting DISABLED, so the chip publishes the initial touch and then goes silent. Write 0x06 to register 0xEC (MotionMask) at boot — bits 1+2 = EnConUD + EnConLR. Same incantation as InfiniTime's CST816S driver. With those set, the chip pushes a fresh x/y on every 100 Hz internal sample for the whole duration of a slide, so last_x/last_y actually track the finger and the swipe qualifier's dx is meaningful.
- **2026-04-29** — Round 59: ROOT CAUSE for the 18/20 swipe failures. Round-58 monitor trace showed every failure with dx=0 dy=0 held=455 ms exactly — i.e. ~205 ms of chip activity + the 250 ms hold-through-gap timeout. The chip was publishing the INITIAL touch point and then going silent for the rest of the gesture, because the CST816S/CST820 family ships with continuous-slide reporting DISABLED by default. Fix matches InfiniTime's CST816S driver: write 0x06 to register 0xEC (MotionMask) at boot — bits 1+2 = EnConUD + EnConLR ("Slide up/down to enable continuous operation" + "Continuous operation can slide around"). With those set, the chip pushes a fresh x/y on every 100 Hz internal sample for the whole duration of a slide, so last_x/last_y track the finger and the swipe-qualifier's dx becomes meaningful again.
- **2026-04-29** — Round 58: round-57's swipe still failed 18/20 — three more aggressive fixes. (1) kHoldThroughGapMs 80 → 250 ms (ESPHome's CST820 component recommends ≥ 50 ms polling, so the chip's no-finger gaps mid-touch can plausibly run longer than 80 ms). (2) Cst820::read parses the touch event flag in buf[2] high nibble: explicit event=lift now treated as no-touch even if fingers != 0, catching the very moment of release. (3) kSwipeMinPx 80 → 50 px so shorter genuine swipes register. (4) Per-transition logging in touchReadCb prints touch DOWN / touch UP with dx, dy, held_ms, and swipe verdict so the serial monitor shows why each swipe attempt did/didn't fire.
- **2026-04-28** — Round 58: round-57's swipe still failed 18/20 — three more aggressive fixes. (1) kHoldThroughGapMs 80 → 250 ms (ESPHome's CST820 component recommends ≥ 50 ms polling intervals, implying the chip's no-finger gaps mid-touch can plausibly run longer than 80 ms; 250 ms is plenty of headroom while still allowing tap responses). (2) Cst820::read now parses the touch event flag in buf[2] high nibble (00=press, 01=lift, 10=contact). When the chip explicitly reports event=lift (even with fingers != 0) we treat as no-touch — that catches the very moment of release that would otherwise latch a stale finger position. (3) kSwipeMinPx 80 → 50 px (round 57 was rejecting some genuine swipes that didn't quite hit 80 px). (4) Per-transition logging in touchReadCb prints touch DOWN at (x,y) on rising edge and touch UP at (x,y) dx=… dy=… held=…ms → SWIPE / (ignored) on release — so any swipe-attempt's verdict is visible in the serial monitor for diagnostics.
- **2026-04-28** — Round 57: swipe nav debugged after web research. Two LVGL-forum-documented gotchas for CST816/CST820: (1) LV_INDEV_DEF_READ_PERIOD = 30 ms gave only ≈ 7 polls during a 200 ms swipe — bumped to 10 ms, comfortably below the chip's 100 Hz native rate. (2) The chip's intermittent no-finger reports during a continuous touch were triggering false release events that reset press_x mid-swipe. Added kHoldThroughGapMs = 80 ms hold-through window in touchReadCb — a no-finger sample within 80 ms of the last real contact keeps reporting PRESSED to LVGL; only a sustained release evaluates the swipe.
- **2026-04-28** — Round 57: swipe nav debugged. Two compounding root causes (well-documented LVGL-forum gotchas for CST816/CST820): (1) LV_INDEV_DEF_READ_PERIOD = 30 ms, so a 200 ms swipe got only ≈ 7 indev polls — too few to ride out the chip's intermittent no-finger reports. Bumped to 10 ms (3× more samples, comfortably below the chip's 100 Hz native rate). (2) touchReadCb's state machine treated every sample of "no finger" as a release, resetting press_x mid-swipe to a position partway through; the next real release then computed a near-zero dx and the qualifier never triggered. Round 57 introduces a kHoldThroughGapMs = 80 ms hold-through window — when read returns false but we were just pressed, we keep reporting PRESSED to LVGL until 80 ms elapses with no contact, only then declaring a true release and evaluating the swipe. press_x is anchored on the FIRST rising edge after a real release; intra-gap dropouts don't disturb it.
- **2026-04-28** — Round 56: navigation-math doc + simulator-purity audit. New docs/NAVIGATION_MATH.md (raw-vs-derived split, formulas, 3 worked examples) + docs/wind-triangle.svg diagram. Code: setGps now takes only (lat, lon) — SOG/COG are DERIVED inside BoatState from consecutive GPS-position deltas (equirectangular plate-carrée; COG suppressed when displacement < 0.5 m). Real PGN 129026 (sensor-supplied COG/SOG) ignored. Simulator now picks a slowly-varying intended speed/heading and integrates the boat's lat/lon along that vector each tick, so SOG/COG fall out of the deltas instead of being hardcoded inputs. BoatState.h cross-references the doc.
- **2026-04-28** — Round 56: navigation-math documentation + simulator-purity audit. New docs/NAVIGATION_MATH.md walks through the raw-vs-derived split, the formulas (SOG/COG from GPS deltas via equirectangular approximation, heading_true = heading_mag + variation, true wind via vector subtraction in the boat-relative frame, TWD/VMG), three end-to-end worked examples (calm light-air upwind / 15 kn beam reach / 25 kn broad reach with current) and an SVG diagram of the wind triangle (docs/wind-triangle.svg). Code audit: setGps signature changed from (lat,lon,sog,cog) to (lat,lon) — SOG and COG are now DERIVED inside BoatState from consecutive GPS-position deltas (equirectangular plate-carrée, COG suppressed when displacement < 0.5 m to dodge GPS-jitter spin). Real PGN 129026 (sensor-supplied COG/SOG) is ignored — never double-source the same quantity. Simulator was setting sog/cog directly; round 56 instead picks a slowly-varying intended speed/heading and integrates the boat's lat/lon along that vector each tick, so SOG/COG fall out of the deltas. Cross-reference from BoatState.h to the new doc.
- **2026-04-28** — Round 55: Main page tweaks + swipe nav. Close-hauled sectors trimmed from 0-60° each side to 20-60° (red 300..340 / green 20..60) so there's a clean ±20° bow zone with no colour. Outer-rim blue target triangle: dropped the "T" letter, and its angular value is now (kTargetCourse - heading_true) mod 360 so it shows the BOAT-RELATIVE bearing to the desired course. New SECOND blue target triangle inside the rotating inner_ring container at compass-angle kTargetCourse — drawn into a 22×22 lv_canvas, pre-rotated so its apex points toward the container centre, position fixed; the container's transform_angle keeps it locked to the absolute compass bearing as the boat turns. kTargetCourse hardcoded at 60° for v1 (TODO: tie to a real autopilot SET source). Touch nav switched from round-39 tap to swipe — release with > 80 px horizontal travel (and |dx| > |dy|) within < 1500 ms qualifies; right swipe = previous page, left swipe = next. Tap events no longer change pages, freeing them up for in-page widget interactions later.
- **2026-04-28** — Round 54: page restructure 4 pages — 0=Main display (NEW: boat in centre, fixed outer 0..180 mirrored ring with red/green close-hauled sectors, rotating inner compass ring with N + 030..330 labels, heading at bow, BSPD at stern, blue TWD wide-arrow cone via needle_img, depth right, heel-angle placeholder left, blue T target marker on rim pinned to heading + 30° until autopilot SET source lands), 1=Wind display (unchanged), 2=Debug, 3=Simulator (NEW: list of raw sensor values + values BoatState computed). Removed round-41-52 sparkline data grid wholesale + the 1 Hz history-sampling block. kNumPages 3 → 4.
- **2026-04-27** — Round 54: page restructure to 4 pages — 0=Main display (NEW: boat in centre, fixed outer 0..180 mirrored ring with red/green close-hauled sectors, rotating inner compass ring with N + 030..330 labels, heading box at the bow, BSPD at the stern, blue TWD wide-arrow cone via needle_img, depth readout on the right, heel-angle placeholder on the left, blue T target marker on the rim pinned to heading + 30° until autopilot SET source lands), 1=Wind display (unchanged), 2=Debug, 3=Simulator (NEW: read-only list of raw sensor values fed into BoatState plus the values BoatState computed). Removed the round-41-52 sparkline data grid wholesale (DataCell/DataPage/MetricHistory/CellSpec/kSpecs/buildDataPage/refreshData/refreshDataCell/recordHistorySnapshot/metricValue/metricFmt/CellMetric and the 1 Hz history-sampling block in tick()). kNumPages 3 → 4.
- **2026-04-27** — Round 53: BoatState split into RAW (lat/lon, SOG/COG, AWA/AWS, mag heading, mag variation, STW, depth) + DERIVED (heading_true = mag + variation; TWA/TWS computed from AWA/AWS/STW via vector subtraction; TWD = heading_true + TWA; VMG = STW · cos TWA). Auto-recompute via recomputeDerived_locked() inside every raw setter. Added src/magnetic_variation.{h,cpp} with stub lookupMagneticVariation (Copenhagen ≈ +5° east; TODO: load WMM from SD). NmeaBridge: real PGN 127250 → mag heading + variation; PGN 130306 → apparent only; PGN 129025 also pumps variation lookup. Sim publishes ONLY raw values now (TWA/TWS hardcoded inputs gone). Ui.cpp computeTwd/computeVmg retired — Page 2 reads s.twd / s.vmg directly.
- **2026-04-27** — Round 53: real / sim alignment with how a boat actually publishes data. BoatState now distinguishes RAW SENSOR INPUTS (lat/lon, SOG/COG, AWA/AWS, magnetic heading, magnetic variation, STW, depth/temp) from DERIVED values (heading_true = heading_mag + variation; TWA/TWS computed from AWA/AWS/STW via vector subtraction in the boat-relative frame; TWD = heading_true + TWA; VMG = STW · cos TWA). Setters mutate raw fields only; recomputeDerived_locked() refreshes the derived block whenever a raw value changes. Added src/magnetic_variation.{h,cpp} with lookupMagneticVariation(lat,lon) — stub returning a Copenhagen-area constant ≈ +5° east, with a TODO to load WMM coefficients from the SD card. NmeaBridge: real PGN 127250 handler now stores raw magnetic heading + variation separately; PGN 130306 only consumes apparent wind (true-wind PGN ignored — derivation wins); PGN 129025 also pumps the variation lookup whenever a fix arrives. Sim publishes ONLY raw values now (TWA/TWS/heading_true previously hardcoded are gone). Ui.cpp's computeTwd/computeVmg helpers retired — Page 2 reads s.twd / s.vmg directly.
- **2026-04-27** — Round 52: TWA triangle was still landing at radius 199 inside the labels because the canvas was only 200 px tall — bumped to 230 px so the image's top edge sits AT the outer rim. Hull half-beam reduced from 110 → 50 (beam 220 → 100 px) for a slim length:beam ≈ 2.8:1 profile. AWS readout moved out of the hull and split: AWS on the LEFT and a new BSPD readout on the RIGHT, both bare labels at montserrat_28 with k unit + subtitle. Added bspd_value_lbl + populated from STW (SOG fallback). Mockup updated.
- **2026-04-27** — Round 52: TWA triangle was still landing at radius 199 (inside the labels) because the canvas was only 200 px tall — bumped to 230 px so the image's top edge sits AT the outer rim and the triangle now runs along the actual outer edge of the dial. Hull half-beam reduced from 110 → 50 (beam 220 → 100 px) for a slim length:beam ≈ 2.8:1 profile matching the user's reference picture. AWS readout moved out of the hull and split: AWS on the LEFT (compass x=-100) and a new BSPD readout on the RIGHT (compass x=+100), both bare labels at montserrat_28 with k unit + subtitle. Added bspd_value_lbl to OverviewPage struct and populated it in refreshOverview from STW (with SOG fallback). Mockup updated.
- **2026-04-27** — Round 51: TWA rim triangle 22 → 12 px so it sits entirely in the outermost rim ring instead of poking inward across the labels. Replaced the round-50 parametric teardrop hull (too round/blob-shaped) with a hand-tuned 24-point polygon matching the reference: sharp pointed bow, sides curving out to maximum beam at midship, flat-ish transom at bottom. AWS box removed — value/unit/subtitle are now bare labels inside the hull. Mockup updated.
- **2026-04-27** — Round 51: TWA rim triangle depth 22 → 12 px so it sits entirely in the outermost rim ring instead of poking inward across the labels. Replaced the round-50 parametric teardrop hull (too round/blob-shaped) with a hand-tuned 24-point polygon matching the user's reference picture: sharp pointed bow at top, sides curving out to maximum beam at midship, gentle taper to a flat transom at bottom. AWS box (white-bordered black rectangle around the wind speed) removed per user request — value/unit/subtitle are now bare labels inside the hull. Mockup script + docs/overview-mockup.png updated to match.
- **2026-04-27** — Round 50: TWA marker reworked from a radial needle_line into an inward-pointing triangle AT the rim — drawn into a 28×200 lv_canvas (top 22 px yellow triangle, base on rim, apex pointing inward; bottom 178 px transparent for the rotation pivot) registered as an lv_meter_add_needle_img. Bow shape replaced with a closed 32-point parametric teardrop hull (same curve as round 41 but bigger, full opacity, 220 px beam) so the dial now shows an unmistakable top-down boat silhouette with the readouts inside. Mockup script + docs/overview-mockup.png updated.
- **2026-04-26** — Round 50: replaced the TWA radial needle_line with an inward-pointing triangle marker AT the rim — drawn into a 28×200 lv_canvas (top 22 px = yellow triangle base-on-rim apex-pointing-inward, bottom 178 px transparent), registered as an lv_meter_add_needle_img with pivot at bottom-centre so rotating to TWA puts the triangle at the rim at angle TWA. Replaced the round-44 open-V "front of bow only" with a closed 32-point parametric teardrop hull (same curve as round 41 but bigger, full opacity) — bow at the top of inner_disc, stern at the bottom, 220 px beam — so the dial now shows an unmistakable top-down boat silhouette with the readouts inside. Mockup script + docs/overview-mockup.png updated to match.
- **2026-04-26** — Round 49: ROOT CAUSE for the recurring colour weirdness — LV_COLOR_16_SWAP=1 in lv_conf.h (a leftover from the round-4-12 ST77916-QSPI era) was packing each pixel as [G_high(3), R(5), B(5), G_low(3)] while the IDF RGB driver memcpy'd it raw to the panel which read it as standard RGB565. Result: every non-palindromic colour scrambled (0xCC0000 → dark teal, 0x006400 → dark red, 0xFFFF00 → magenta). Set LV_COLOR_16_SWAP=0 and updated the related comments in Ui.cpp / st7701_panel.{h,cpp}. Also added scripts/render_overview_mockup.py + docs/overview-mockup.png so the user can see the intended design.
- **2026-04-26** — Round 48: IMG_1925 still showed TWA needle as a thin pink/magenta diagonal — switched colour from lv_color_hex(0xFFFF00) to lv_palette_main(LV_PALETTE_AMBER) (#FFC107, going through a different colour-construction path) and width 8 → 12 so it reads as a bold yellow marker; bow open-V stroke width 3 → 6 px so the front-of-boat shape is clearly visible even at the existing full opacity.
- **2026-04-26** — Round 47: three small fixes after IMG_1922 — AWS box contents rebalanced (value at -14 px left, 'k' at LV_ALIGN_CENTER offset 36/-18 right next to it instead of TOP_RIGHT corner, so '10.4 k' is visually centred); TWA needle brightened from 0xFFCC00 to 0xFFFF00 and width 6→8 so it reads as yellow not pink/purple; bow open-V opacity bumped from LV_OPA_60 to LV_OPA_COVER for a more visible front-of-boat shape.
- **2026-04-26** — Round 47: three small fixes after IMG_1922 — AWS box contents rebalanced (value at -14 px left, "k" placed right next to it via LV_ALIGN_CENTER offset 36/-18 instead of TOP_RIGHT corner, so the "10.4 k" pair is visually centred); TWA needle brightened from 0xFFCC00 (amber) to 0xFFFF00 (pure yellow) and width 6→8 so it reads as yellow rather than a thin pink/purple line; bow open-V opacity bumped from LV_OPA_60 to LV_OPA_COVER per user "try make it higher".
- **2026-04-26** — Round 46: shrink AWA cone after IMG_1922 showed the round-45 80×180 image overwhelmed the dial. New canvas dimensions 50×140 with bottom 50 px transparent → 40 px wide visible base, 90 px tall visible cone. Inset polygon coordinates retuned (3-4 px white border instead of 4-5).
- **2026-04-26** — Round 46: shrink AWA cone after IMG_1922 showed the round-45 80×180 image overwhelmed the dial. New canvas dimensions 50×140 with bottom 50 px transparent → 40 px wide visible base, 90 px tall visible cone. Inset polygon coordinates retuned (3-4 px white border instead of 4-5 at the larger size).
- **2026-04-26** — Round 45: sector colours fixed (LV_PALETTE_RED/GREEN rendering as purple / light green; switched to explicit hex 0xCC0000 / 0x006400). AWA cone enlarged from 60×220 to 80×180 with bottom 50 px transparent so its visible base lands ~1 px above the DRIFT circle. inner_disc made transparent so the cone reaches the centre. New yellow TWA needle (width 6, 0xFFCC00) with own dedup'ed update path; twa_needle field added to OverviewPage struct.
- **2026-04-26** — Round 45: sector colours fixed (LV_PALETTE_RED/GREEN were rendering as purple / wishy-washy light green; switched to explicit hex 0xCC0000 / 0x006400). AWA cone enlarged from 60×220 to 80×180 with the bottom 50 px transparent so its visible base lands ~1 px above the DRIFT circle — much chunkier visible pointer that reaches close to the centre. inner_disc made transparent so the cone is visible all the way to the centre. New yellow TWA needle (lv_meter_add_needle_line, width 6, 0xFFCC00) with its own dedup'ed update path in refreshOverview, and twa_needle field added to OverviewPage struct.
- **2026-04-26** — Round 44: Page 1 fidelity pass — mirrored 0..180 dial labels (auto-labels hidden, 12 manual lv_label children placed by sin/cos at radius 188 with text mirrored across the vertical axis); sectors widened from 40° to 60° each side (red 300..360, green 0..60); boat outline replaced with open V from bow tip to dial-angle ±120°; wind pointer reworked from stacked needles to a canvas-drawn tapered cone via lv_meter_add_needle_img; round-42 upper DRIFT pill replaced with a small white-bordered circle at the centre containing a tiny cyan arrow + DRIFT value; AWS box moved below the centre circle; round-43 cyan chevron dropped.
- **2026-04-25** — Round 44: Page 1 fidelity pass — mirrored 0..180 dial labels (auto-labels hidden via black tick text colour, 12 manual lv_label children placed at 30° intervals around radius 188 with text mirrored across the vertical axis); close-hauled sectors widened from 40° to 60° each side (red 300..360, green 0..60); boat outline replaced with an open V "front of bow only" line from bow tip to dial-angle ±120°; wind pointer reworked from stacked rectangular needle pair to a tapered cone via lv_canvas (60×220 TRUE_COLOR_ALPHA buffer in PSRAM) registered as an lv_meter_add_needle_img; round-42 upper DRIFT pill replaced with a small white-bordered circle at the geometric centre containing a tiny cyan up-arrow + DRIFT value; AWS box moved to below the centre circle; round-43 standalone cyan chevron removed (superseded by the centre circle's small arrow).
- **2026-04-25** — Round 43: visual fixes after round 42 — SCALE_LINES didn't paint, reverted red/green to solid lv_meter_add_arc bars; wind needles widened from 16/10 to 32/22 px; round-41 teardrop hull back as faint LV_OPA_40 outline; new static cyan chevron on the dial annulus port-beam position as drift-direction marker. Flicker: PCLK dropped 16 → 12 MHz (refresh ~44 Hz) for less PSRAM-bus contention with the framebuffer memcpy.
- **2026-04-25** — Round 43: visual fixes after round 42 — SCALE_LINES indicators didn't paint visibly so reverted red/green to solid lv_meter_add_arc bars (round-41 known-good); wind-pointer needles widened from 16/10 px to 32/22 px ("next to no arrow"); the round-41 32-point teardrop hull outline is back as a faint LV_OPA_40 white silhouette inside the inner disc; new static cyan chevron on the dial annulus port-beam position as a drift-direction marker. Flicker mitigation: PCLK dropped from 16 MHz to 12 MHz (refresh ~58.5 → ~43.9 Hz, still flicker-free) for less PSRAM-bus contention.
- **2026-04-25** — Round 42: black-dial Overview redesign to match new B&G reference (white tick lines + white labels, red/green close-hauled markers via SCALE_LINES tick recolouring instead of solid arcs, stacked white-bordered fat wind pointer, central DRIFT pill + AWS box stack, drop hull silhouette + heading box). Flicker mitigation: bounce-buffer struct fields aren't in this Arduino-ESP32 IDF fork — reverted; instead dedup lv_meter wind-pointer updates (skip when integer angle unchanged) and slow refreshFromState from 10 Hz to 4 Hz to cut redraw amplification.
- **2026-04-25** — Round 42: black-dial Overview redesign to match new B&G reference (white tick lines + white labels, red/green close-hauled markers via SCALE_LINES tick recolouring instead of solid arcs, stacked white-bordered fat wind pointer replacing the two thin needles, central DRIFT pill + AWS box stack, drop the hull silhouette and heading box). Flicker mitigation fallback: bounce-buffer mode didn't compile against this Arduino-ESP32 IDF fork (struct lacks bounce_buffer_size_px / bb_invalidate_cache), so reverted that and instead dedup'ed lv_meter wind-pointer updates (skip when integer angle unchanged) and slowed refreshFromState from 10 Hz to 4 Hz to cut redraw amplification.
- **2026-04-25** — Round 41: B&G fidelity pass — sectors widened to ±40° / 26 px, compass ticks doubled to 145 @ 2.5°, boat hull replaced with smooth 32-point teardrop. Page 2 redrawn as round-table (centre BSPD font-48, four cardinals HDG/AWS/TWS/AWA font-28 with charts, four diagonals TWA/TWD/VMG/SOG font-20 value-only); sparklines now 20-bar zero-padded histograms (area-fill look at readable resolution); titles upsized + brightened.
- **2026-04-25** — Round 41: B&G fidelity pass — port/stbd close-hauled sectors widened to ±40° + thickened to 26 px, compass tick density doubled to 145 ticks @ 2.5° (majors every 30°), boat hull replaced with a smooth 32-point parametric teardrop (no more polygon elbows). Page 2 redrawn as a round-table layout: BSPD centre tile (170×170, font 48, 40 px area-fill chart), four cardinal tiles (HDG/AWS/TWS/AWA, font 28, 22 px area-fill chart), four diagonal value-only tiles (TWD/TWA/VMG/SOG, font 20). Sparklines switched to 20-bar histograms with zero column padding (area-fill look at lower resolution); titles upsized + brightened.
- **2026-04-25** — Round 40: B&G middle-section Overview (compass-only — outer dial + port/stbd close-hauled sectors + AWA/ref needles + inner disc + boat outline + speed circle + heading box + °M / Var labels) and new Page 2 = 3×3 sparkline grid (AWA/TWA/TWD, AWS/BSPD/TWS, HDG/SOG/VMG) backed by 5 min @ 1 Hz history rings.
- **2026-04-25** — Round 40: B&G middle-section Overview (compass-only — outer dial + port/stbd close-hauled sectors + AWA/ref needles + inner disc + boat outline + speed circle + heading box + °M / Var labels) and new Page 2 = 3×3 sparkline grid (AWA/TWA/TWD, AWS/BSPD/TWS, HDG/SOG/VMG) backed by 5 min @ 1 Hz history rings.
- **2026-04-25** — Round 39: tap-based page navigation — touchReadCb tracks press/release edges, qualifies a tap by held<500 ms + motion<40 px, queues a step (-1 left half / +1 right half) for tick() to consume; remove LV_EVENT_GESTURE wiring.
- **2026-04-25** — Round 39: tap-based page navigation — touchReadCb tracks press/release edges, qualifies a tap by held<500 ms + motion<40 px, queues a step (-1 left half / +1 right half) for tick() to consume; remove LV_EVENT_GESTURE wiring.
- **2026-04-25** — Round 38: CST820 read uses STOP (not repeated start) between reg-pointer write and requestFrom; disable auto-sleep on begin (write 0xFF to reg 0xFE); add rate-limited touch-event log for diagnostics.
- **2026-04-25** — Round 38: CST820 read uses STOP (not repeated start) between reg-pointer write and requestFrom; disable auto-sleep on begin (write 0xFF to reg 0xFE); add rate-limited touch-event log for diagnostics.
- **2026-04-25** — Round 37: CST820 register-pointer off-by-one — start read at reg 0x01 so finger count lands at buf[1] instead of the gesture register.
- **2026-04-25** — Round 36: B&G-style Overview redesign — central compass + boat outline + 8 perimeter tiles; add CST820 touch driver wired as LVGL pointer input.
- **2026-04-25** — Round 35: vsync-gate LVGL flushes via cfg.on_frame_trans_done + binary semaphore; throttle data refresh to 10 Hz.
- **2026-04-25** — Round 34: full-frame LVGL double-buffer in PSRAM (2 × 480×480×2); remove 5-phase boot sanity bar.
- **2026-04-25** — Round 34 (re-commit): identical message to the entry above.
- **2026-04-24** — Round 33: flip ST7701 0xC2 BK0 byte-0 inversion-mode bits 0x07 → 0x37 (bits [5:4]: 00 → 11) — kills brightness banding.
- **2026-04-24** — Round 32: revert MADCTL to 0x00; do 180° rotation in flushCb via in-place buffer reverse + flipped drawBitmap coords.
- **2026-04-24** — Round 31: MADCTL 180° rotation attempt (set 0xC0) — no effect in RGB mode, superseded by round 32.
- **2026-04-24** — Round 30: replace ST7701 init sequence + RGB timings verbatim with Waveshare's authoritative config for this board.
- **2026-04-24** — Round 29: change ST7701 COLMOD from 0x55 (RGB565) to 0x66 (RGB666).
- **2026-04-24** — Round 28: revert RGB timings to FatihErtugral sibling-board values; restore 5-phase RGB/W/K boot sanity bar.
- **2026-04-24** — Round 28 (re-commit): identical message to the entry above.
- **2026-04-24** — Round 27: 16-phase walking-bit diagnostic — drive each pixel-data bit HIGH in turn to map which RGB GPIOs reach the panel.
- **2026-04-24** — Round 26: revert round 25 — ST7701 0xC2 back to baseline {0x20, 0x06}.
- **2026-04-24** — Round 25: change ST7701 0xC2 from {0x20, 0x06} to Waveshare factory {0x07, 0x0A} (chasing vertical stripes; reverted next round).
- **2026-04-24** — Round 23: extend colour-bar phases from 2 s to 5 s; log AFTER-fillColor line so the user can photograph steady state.
- **2026-04-24** — Round 22: re-add 0x3A COLMOD = 0x55 (16-bit RGB565).
- **2026-04-24** — Round 21: insert boot-time colour-bar diagnostic (RED/GREEN/BLUE/WHITE/BLACK, 2 s each).
- **2026-04-24** — Round 20: pivot from init-sequence edits to RGB-bus timing — adjust PCLK + porch widths to chase stripe pattern.
- **2026-04-23** — Round 19: replace ST7701 init table verbatim with espressif/esp-iot-solution's vendor_specific_init_default[].
- **2026-04-23** — Round 18: correct COLMOD (0x3A) from 0x66 (RGB666) to 0x55 (RGB565) to match the 16-line RGB bus.
- **2026-04-23** — Round 15: backlight pivot to raw GPIO6 PWM (was wrongly on TCA9554 IO0/LCD_RST); fix EXIO numbering off-by-one.
- **2026-04-23** — Round 15 (re-commit): identical message to the entry above.
- **2026-04-23** — Round 14: ship the real ST7701 RGB driver (esp_lcd_panel_rgb + 3-wire SPI init via TCA9554-gated CS); retire ST77916 stub.
- **2026-04-23** — Round 13: reframe — board is ST7701 RGB + TCA9554, not ST77916 QSPI + CH422G; capture the real pinout.
- **2026-04-23** — Round 12: TCA9554 IO-to-signal mapping diagnostic (walking-bit on the expander outputs).
- **2026-04-23** — Round 11: port IO-expander driver from CH422G to TCA9554; update all callsites + docs.
- **2026-04-23** — Round 10: chipset pivot — 420-pair I2C scan locks SDA=GPIO15 / SCL=GPIO7; bus has 0x15 + 0x20 + 0x51, ruling out QSPI.
- **2026-04-22** — Round 6: I2C still blind on GPIO8/9 and 10/11 — pivot to broader pin scan.
- **2026-04-22** — Round 4: SPI side clean — 64-byte sendPixels chunking, SPI3_HOST, drop spi_bus_free; init / backlight / fillColor all return OK.
- **2026-04-22** — Real display driver: hand-written ST77916 QSPI + CH422G I2C expander; replace LovyanGFX stub. (Superseded round 13.)
- **2026-04-22** — Real display driver (re-commit): identical message to the entry above.
- **2026-04-22** — Sim env builds again: include <lvgl/lvgl.h> directly; pin LovyanGFX to =1.2.0 to dodge LVGL-9 API rewrite.
- **2026-04-22** — Safe-mode firmware boots clean on real hardware (363 KB free heap); update.sh defaults to safe env until LVGL headers unbreak.
- **2026-04-21** — Add three-screen UI, PGN log, prebuilt binaries, 3D case, update.sh + CHANGELOG, and fix CI to build sim env only
- **2026-04-20** — Add three-screen UI, PGN log, prebuilt binaries, 3D case, update.sh + CHANGELOG, and fix CI to build sim env only
- **2026-04-20** — Add three-screen UI, PGN log, prebuilt binaries, 3D-printable case, and update.sh + CHANGELOG workflow

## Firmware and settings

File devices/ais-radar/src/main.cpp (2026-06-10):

// AIS-radar device (ADR-0016) — display + touch + GPS + live Daisy AIS,
// drawn radar-style on the AMOLED.
//
// Reads the Wegmatt dAISy 2+ on IO16 (Serial2 @ 38400), decodes AIVDM into
// the target store, and plots targets around own ship. Own position comes
// from the LC76G once R15/R16 are soldered; until then it's pinned to a
// fixed bench location so targets place correctly. Targets expire after 10 s
// of silence. Next: the BLE link to iOS.

#include <Arduino.h>
#include <lvgl.h>
#include <SD_MMC.h>
#include <AmoledDisplay.h>
#include <Touch.h>
#include <Lc76gGps.h>
#include <AisTargetDecoder.h>
#include <default_sentence_parser.h>
#include "Radar.h"
#include "Ble.h"
#include "DeviceSettings.h"

static constexpr uint32_t kDaisyBaud  = 38400;   // dAISy NMEA-HS default
static constexpr uint32_t kTargetLifeMs = 10000; // drop targets after 10 s

// Bench own-ship position, used until the LC76G GPS is soldered/working.
static constexpr double kBenchLat = 55.76196;
static constexpr double kBenchLon = 12.62900;

static AisTargetDecoder decoder;
static AIS::DefaultSentenceParser parser;

static void feed(const char* sentence) {
    char buf[128];
    int n = snprintf(buf, sizeof(buf), "%s\r\n", sentence);
    size_t i = 0;
    do { i = decoder.decodeMsg(buf, (size_t)n, i, parser); } while (i != 0);
}

// ---- Daisy 2+ AIS on IO16 (Serial2 @ 38400) -------------------------------
static uint32_t g_daisyBytes = 0;
static uint32_t g_daisyLines = 0;
static int      g_threat = 0;          // 0=none 1=safe 2=alert 3=danger
static int      g_batt = -1;           // ESP battery % (AXP2101), <0 = unknown
static char     g_line[120];
static int      g_len = 0;

static void daisyPoll() {
    while (Serial2.available() > 0) {
        char c = (char)Serial2.read();
        g_daisyBytes++;
        if (c == '\n') {
            if (g_len > 0) {
                g_line[g_len] = '\0'; g_daisyLines++;
                feed(g_line);
                ble::logLine(g_line);        // stream raw to the app + heartbeat
            }
            g_len = 0;
        } else if (c != '\r' && g_len < (int)sizeof(g_line) - 1) {
            g_line[g_len++] = c;
        }
    }
}

// One-shot SD-card recon (C-MAP investigation). Mounts the onboard microSD
// (SD_MMC, 1-bit: CLK=2 CMD=1 DATA=3 per Waveshare pin_config) and lists the
// root + cmap/ over serial so we can see the card layout + format.
static void listSdDir(const String& path, int depth, int maxDepth) {
    File d = SD_MMC.open(path);
    if (!d || !d.isDirectory()) return;
    int count = 0;
    for (File e = d.openNextFile(); e && count < 16; e = d.openNextFile(), ++count) {
        const char* name = e.name();
        if (name[0] == '.') continue;   // skip macOS cruft (._, .Spotlight…)
        for (int i = 0; i < depth; ++i) Serial.print("  ");
        Serial.printf("%s%s  %lu B\n", name, e.isDirectory() ? "/" : "",
                      (unsigned long)e.size());
        if (e.isDirectory() && depth < maxDepth) {
            String sub = (path == "/") ? ("/" + String(name)) : (path + "/" + name);
            listSdDir(sub, depth + 1, maxDepth);
        }
    }
}

static void listSdCard() {
    SD_MMC.setPins(2, 1, 3);
    if (!SD_MMC.begin("/sdcard", true)) {
        Serial.println("[sd] mount FAILED");
        return;
    }
    Serial.printf("[sd] mounted: type=%d size=%lluMB\n[sd] tree (2 levels):\n",
                  (int)SD_MMC.cardType(),
                  (unsigned long long)(SD_MMC.cardSize() / (1024ULL * 1024ULL)));
    listSdDir("/", 0, 2);
    Serial.println("[sd] end");
}

// Own-ship state. Priority: onboard LC76G fix > phone GPS over BLE > bench.
struct Own { double lat, lon, cog, sog; bool realFix; };
static Own ownShip() {
    const gps::Fix& f = gps::fix();
    ble::HostGps hg;
    // Phone GPS preferred when enabled + fresh (even over the LC76G, in case the
    // phone is more accurate); otherwise LC76G; otherwise the bench coord.
    if (devsettings::get().phoneGps && ble::hostGps(&hg)) {
        return { hg.lat, hg.lon, hg.cogDeg, isnan(hg.sogKn) ? 0.0 : hg.sogKn, true };
    }
    if (f.fixQuality >= 1 && !isnan(f.lat) && !isnan(f.lon)) {
        return { f.lat, f.lon, NAN, 0.0, true };          // LC76G (position only)
    }
    return { kBenchLat, kBenchLon, NAN, 0.0, false };     // bench fallback
}

// Bench test targets: three Class-B vessels at FIXED positions near the bench
// (absolute, like real AIS — they don't follow own ship). Showing the three
// threat modes when own ship is at the bench. Re-stamped each call so they
// never evict. Go to the AMOLED and, via ble::publish, the iOS app.
static void injectTestTargets() {
    struct T { uint32_t mmsi; const char* nm; uint8_t type;
               float sog, cog; double dLat, dLon; };
    static const T ts[] = {
        {992110001, "SAILBOAT", 36,  5.0f, 210.0f,  0.0480,  0.0300},  // safe   — triangle
        {992110002, "YACHT",    37, 22.0f, 120.0f,  0.0200, -0.0250},  // alert  — circle
        {992110003, "TANKER",   80, 10.0f, 180.0f,  0.0133,  0.0000},  // danger — hull
    };
    for (const auto& t : ts) {
        decoder.store().recordName(t.mmsi, 'B', t.nm);
        decoder.store().recordType(t.mmsi, 'B', t.type);
        decoder.store().recordPosition(t.mmsi, 'B', t.sog, t.cog);
        decoder.store().recordLatLon(t.mmsi, kBenchLat + t.dLat, kBenchLon + t.dLon);
    }
}

void setup() {
    Serial.begin(115200);
    delay(800);
    Serial.println("\n[ais-radar] radar UI + Daisy AIS (ADR-0016)");
    devsettings::load();

    const bool haveDisplay = amoled::begin();
    touch::begin();
    gps::begin();   // UART-only; silent until R15/R16 jumpers are soldered

    Serial2.setRxBufferSize(2048);
    Serial2.begin(kDaisyBaud, SERIAL_8N1, /*rx=*/16, /*tx=*/-1);
    Serial.printf("[daisy] Serial2 @ %lu on IO16\n", (unsigned long)kDaisyBaud);

    if (haveDisplay) radar::begin();
    else Serial.println("[ais-radar] display unavailable — serial only");

    ble::begin();
    listSdCard();   // one-shot C-MAP recon (late so it survives USB re-enum)
}

void loop() {
    static uint32_t last = 0, lastDraw = 0, lastStat = 0, lastBle = 0, lastBatt = 0;
    const uint32_t now = millis();

    daisyPoll();
    gps::poll(now);
    int16_t tx, ty;
    (void)touch::readPoint(tx, ty);

    lv_tick_inc(now - last);
    last = now;

    if (now - lastBatt >= 5000) { lastBatt = now; g_batt = amoled::batteryPercent(); }

    if (now - lastDraw >= 500) {
        lastDraw = now;
        Own o = ownShip();
        if (devsettings::get().testTargets) injectTestTargets();
        decoder.store().evictStale(kTargetLifeMs);   // 10 s lifetime
        radar::draw(decoder.store(), o.lat, o.lon, o.cog, o.sog, g_batt);
        g_threat = radar::assessWorst(decoder.store(), o.lat, o.lon, o.cog, o.sog);
    }
    if (now - lastBle >= 1000) {
        lastBle = now;
        Own o = ownShip();
        ble::publish(decoder.store(), o.lat, o.lon, o.cog, o.sog, o.realFix, g_threat, g_batt);
    }
    if (now - lastStat >= 2000) {
        lastStat = now;
        Serial.printf("[stat] ais_bytes=%lu lines=%lu targets=%u ble=%d\n",
                      (unsigned long)g_daisyBytes, (unsigned long)g_daisyLines,
                      (unsigned)decoder.store().size(), ble::connected());
    }
    lv_timer_handler();
    delay(5);
}

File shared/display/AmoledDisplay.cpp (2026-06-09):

#include "AmoledDisplay.h"

#include <Arduino.h>
#include <Wire.h>
#include <XPowersLib.h>
#include <Arduino_GFX_Library.h>
#include <lvgl.h>

// Salvaged verbatim (behaviour-preserving) from src_tx/main.cpp's
// initDisplay() / flushDisplayCb() / initLvgl(), minus the app UI. See that
// file's commit history (tag v1-wifi-bus-archive) for the bring-up notes —
// the CO5300-for-SH8601 substitution and the 6-column window offset in
// particular were found the hard way.

namespace amoled {
namespace {

constexpr uint8_t kAxp2101Addr = 0x34;
constexpr int kLcdCs = 12, kLcdSck = 38;
constexpr int kLcdD0 = 4, kLcdD1 = 5, kLcdD2 = 6, kLcdD3 = 7;
constexpr int kLcdReset = 39;

XPowersAXP2101    PMU;
Arduino_DataBus  *gfxBus = nullptr;
Arduino_GFX      *gfx    = nullptr;

lv_disp_draw_buf_t lvDrawBuf;
lv_color_t        *lvBuf = nullptr;
lv_disp_drv_t      lvDispDrv;

void flushCb(lv_disp_drv_t *disp, const lv_area_t *area, lv_color_t *color_p) {
    const int16_t w = area->x2 - area->x1 + 1;
    const int16_t h = area->y2 - area->y1 + 1;
    gfx->draw16bitRGBBitmap(area->x1, area->y1, (uint16_t *)color_p, w, h);
    lv_disp_flush_ready(disp);
}

bool initDisplay() {
    gfxBus = new Arduino_ESP32QSPI(kLcdCs, kLcdSck,
                                   kLcdD0, kLcdD1, kLcdD2, kLcdD3);
    // CO5300 driver stands in for the pin-compatible SH8601; the 6-column
    // window offset avoids the green seam on these round 466×466 AMOLEDs.
    gfx = new Arduino_CO5300(gfxBus, kLcdReset, 0 /*rotation*/, false /*ips*/,
                             kLcdW, kLcdH, 6, 0, 6, 0);
    if (!gfx->begin()) {
        Serial.println("[amoled] gfx->begin() failed — check QSPI pins / panel power");
        return false;
    }
    gfx->fillScreen(BLACK);
    return true;
}

bool initLvgl() {
    lv_init();
    const size_t pixels = (size_t)kLcdW * kLcdH;
    lvBuf = (lv_color_t *)heap_caps_malloc(pixels * sizeof(lv_color_t),
                                           MALLOC_CAP_SPIRAM);
    if (!lvBuf) {
        Serial.println("[amoled] PSRAM draw-buffer alloc failed");
        return false;
    }
    lv_disp_draw_buf_init(&lvDrawBuf, lvBuf, nullptr, pixels);
    lv_disp_drv_init(&lvDispDrv);
    lvDispDrv.hor_res  = kLcdW;
    lvDispDrv.ver_res  = kLcdH;
    lvDispDrv.flush_cb = flushCb;
    lvDispDrv.draw_buf = &lvDrawBuf;
    lv_disp_drv_register(&lvDispDrv);
    lv_obj_set_style_bg_color(lv_scr_act(), lv_color_black(), LV_PART_MAIN);
    return true;
}

}  // namespace

bool begin() {
    if (!Wire.begin(kI2cSda, kI2cScl, 100000)) {
        Serial.println("[amoled] Wire.begin() failed");
        return false;
    }
    if (!PMU.begin(Wire, kAxp2101Addr, kI2cSda, kI2cScl)) {
        Serial.println("[amoled] PMU.begin() failed (AXP2101 @ 0x34)");
        return false;
    }
    if (!initDisplay()) return false;
    if (!initLvgl())    return false;
    Serial.println("[amoled] display + LVGL up (466×466 RGB565)");
    return true;
}

int batteryPercent() {
    return PMU.getBatteryPercent();
}

}  // namespace amoled

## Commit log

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2026-04-19 Fix sim build: gate N2K stack, stub LGFX, enable LVGL widgets
    [main.cpp]
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2026-04-20 Add three-screen UI, PGN log, prebuilt binaries, 3D case, update.sh + CHANGELOG, and fix CI to build sim env only
2026-04-22 Sim env builds again: fix LVGL header hijack (include <lvgl/lvgl.h> directly, add .pio/libdeps/<env>/ to -I) and pin LovyanGFX to =1.2.0 to dodge the 1.2.20 LVGLfont rewrite against LVGL 9 API. Resto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
    [main.cpp]
2026-04-22 Real display driver: replace LovyanGFX stub with hand-written ST77916 QSPI driver (ESP-IDF spi_master, quad transactions) + CH422G I2C expander for reset/backlight gating. Pixels-only in v1; CST820 t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
2026-04-22 Display bring-up round 4: SPI side now clean — 64-byte sendPixels chunking, SPI3_HOST, and dropping spi_bus_free made runInitSequence/backlight-on/fillColor go through with no 'txdata transfer > hard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
    [main.cpp]
2026-04-22 Display bring-up round 6: I2C is still blind on GPIO8/9 (both orderings) AND GPIO10/11 (both orderings) — we've exhausted the plausible guesses derived from other Waveshare CH422G boards. Stop guessi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
2026-04-23 Display bring-up round 10: CHIPSET PIVOT. Round 9's exhaustive 420-pair I2C scan produced a clean result — only SDA=GPIO15 ever ACKs, and the only three addresses that respond are 0x15 (CST820 touch)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
2026-04-23 Display bring-up round 12: TCA9554 IO-to-signal mapping diagnostic. Round 11 landed cleanly (TCA9554 ACK at 0x20, config+output writes accepted) but the backlight still never came on, which means our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
2026-04-23 Display bring-up round 15: fix the two wrong assumptions that kept the round-14 driver producing a black screen. Round 14 compiled clean, flashed fine, and every log line reported success — TCA9554 a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
2026-04-23 Display bring-up round 18: correct the COLMOD (0x3A) parameter from 0x66 (18-bit RGB666) to 0x55 (16-bit RGB565) so the panel's expected data-bit layout matches our actual 16-line RGB bus. Round 17 a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
2026-04-23 Display bring-up round 19: replace the ST7701 init table wholesale with a verbatim port of espressif's esp-iot-solution esp_lcd_st7701_rgb.c vendor_specific_init_default[]. Round 18's photo showed a 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
2026-04-24 Display bring-up round 20: pivot from init-sequence edits to RGB-bus timing. Round 19 shipped a verbatim port of espressif's ST7701 init sequence and the display output did not change from round 18 —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
2026-04-24 Display bring-up round 22: re-add the 0x3A COLMOD command with value 0x55 (16-bit RGB565 on the RGB interface). Round 21's colour-bar diagnostic produced the cleanest signal we've had since round 13.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
2026-04-24 Display bring-up round 25: change ST7701 inversion-control register 0xC2 from espressif's {0x20, 0x06} to Waveshare's factory-firmware {0x07, 0x0A} to kill the stable vertical-stripe pattern on solid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
2026-04-24 Display bring-up round 27: replace the 5-phase RGB solid-colour bar in src/Ui.cpp with a 16-phase walking-bit diagnostic. Each phase drives exactly ONE pixel bit HIGH across the whole 480×480 frame —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
2026-04-24 Display bring-up round 28: revert RGB-bus timings (PCLK and porches) to the FatihErtugral sibling-2.8"-ST7701 board configuration and restore the simple 5-phase RGB/WHITE/BLACK sanity bar in src/Ui.c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
2026-04-24 Display bring-up round 29: change ST7701 COLMOD from 0x55 (16-bit RGB565) to 0x66 (18-bit RGB666) in src/display/st7701_panel.cpp::kInitCmds[] — single-byte edit. Round 28's FatihErtugral timing reve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
2026-04-24 Display bring-up round 30: full pivot — replace the entire ST7701 init sequence AND the RGB timings with the authoritative Waveshare configuration for this exact board, taken verbatim from esp-arduin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
2026-04-24 Display bring-up round 31: MADCTL 180° rotation fix. Round 30's photos (IMG_1883-1888) were the first ones in 30 rounds to show correct colour channels AND readable LVGL content — RED fills red, GREE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
2026-04-24 Display bring-up round 32: revert MADCTL to 0x00, apply the 180° rotation in src/Ui.cpp::flushCb instead. Round-31 photos IMG_1889-1894 came back with the image orientation unchanged from round 30 — 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
2026-04-24 Display bring-up round 33: flip ST7701 0xC2 BK0 byte-0 inversion-mode bits from 0x07 → 0x37 to kill the wide brightness bands on solid-colour fills. Round 32 closed out rotation (photos IMG_1895-1900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
2026-04-25 Display bring-up round 34: full-frame LVGL double-buffer in PSRAM and remove the 5-phase boot sanity bar — display bring-up is COMPLETE. Round-33 photos IMG_1901-1906 confirmed the 0xC2 inversion-mod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
2026-04-25 Display bring-up round 35: vsync-gate every LVGL flush against the RGB-panel frame-trans-done interrupt, and throttle widget data refreshes from per-loop to 10 Hz, to kill the side-to-side shimmer th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
2026-04-25 Round 36: B&G-style Overview redesign — central compass + boat outline + 8 perimeter tiles; add CST820 touch driver wired as LVGL pointer input.
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2026-04-25 Round 41: B&G fidelity pass — sectors widened to ±40° / 26 px, compass ticks doubled to 145 @ 2.5°, boat hull replaced with smooth 32-point teardrop. Page 2 redrawn as round-table (centre BSPD font-4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
2026-04-25 Round 42: black-dial Overview redesign to match new B&G reference (white tick lines + white labels, red/green close-hauled markers via SCALE_LINES tick recolouring instead of solid arcs, stacked whit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
2026-04-25 Round 43: visual fixes after round 42 — SCALE_LINES didn't paint, reverted red/green to solid lv_meter_add_arc bars; wind needles widened from 16/10 to 32/22 px; round-41 teardrop hull back as faint 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
2026-04-26 Round 45: sector colours fixed (LV_PALETTE_RED/GREEN rendering as purple / light green; switched to explicit hex 0xCC0000 / 0x006400). AWA cone enlarged from 60×220 to 80×180 with bottom 50 px transp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
2026-04-26 Round 47: three small fixes after IMG_1922 — AWS box contents rebalanced (value at -14 px left, 'k' at LV_ALIGN_CENTER offset 36/-18 right next to it instead of TOP_RIGHT corner, so '10.4 k' is visua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
2026-04-27 Round 50: TWA marker reworked from a radial needle_line into an inward-pointing triangle AT the rim — drawn into a 28×200 lv_canvas (top 22 px yellow triangle, base on rim, apex pointing inward; bott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
2026-04-27 Round 51: TWA rim triangle 22 → 12 px so it sits entirely in the outermost rim ring instead of poking inward across the labels. Replaced the round-50 parametric teardrop hull (too round/blob-shaped) 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
2026-04-28 Round 54: page restructure 4 pages — 0=Main display (NEW: boat in centre, fixed outer 0..180 mirrored ring with red/green close-hauled sectors, rotating inner compass ring with N + 030..330 labels, h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
2026-04-28 Round 57: swipe nav debugged after web research. Two LVGL-forum-documented gotchas for CST816/CST820: (1) LV_INDEV_DEF_READ_PERIOD = 30 ms gave only ≈ 7 polls during a 200 ms swipe — bumped to 10 ms,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
2026-04-29 Round 58: round-57's swipe still failed 18/20 — three more aggressive fixes. (1) kHoldThroughGapMs 80 → 250 ms (ESPHome's CST820 component recommends ≥ 50 ms polling, so the chip's no-finger gaps mid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
2026-04-29 Round 59: ROOT CAUSE — every swipe failure had dx=0 dy=0 held=455 ms exactly. The CST816S/CST820 family ships with continuous-slide reporting DISABLED, so the chip publishes the initial touch and the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
2026-04-29 Round 61: round-60 trace identified the chip's tap-detection window — every dx=0 failure had held≈455 ms = ~205 ms of CST820 activity + 250 ms debounce. The chip stops streaming coords during its tap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
2026-05-04 Round 63: trust the CST820's onboard gesture engine. Round-62 trace showed the chip emitting gesture=0x04 (slide) mid-swipe while our software was still trying to reconstruct the gesture from coordin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
2026-05-04 Round 64: capture lift-event coords and post-lift gesture. Round-63 bench showed three swipe attempts where the chip went silent through the entire touch — neither streamed coords nor fired a gesture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
2026-05-04 Round 67: TP_INT pinMode INPUT → INPUT_PULLUP, plus a 5 s heartbeat log of the IRQ count and live TP_INT level. Round 66 wired up the FALLING-edge ISR but the boot GPIO scan (line 'gpio 4 : LOW (tied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
2026-05-04 Round 68: revert the round-66 IRQ gate; restore polling. Round-67 heartbeat trace proved the chip is not pulsing TP_INT on touch events on this hardware (irqs=4 at boot from startup chatter, then loc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
2026-05-04 Round 69: chip-keepalive experiments. Round-68 bench (one swipe per heartbeat-spaced touch) was 0/9 — the chip emits one coord at press and goes silent for the entire touch when isolated by several s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
2026-05-04 Round 70: ship tap fallback. Round-69 bench was 0/12 — the chip's silent-touch behaviour on isolated touches is not changeable by any register tweak we've found across rounds 65-69. Accepting the har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
2026-05-04 Round 71: clean up monitor noise now that tap nav is shipped. Removed cst820 5 s heartbeat block (was for the round-66/67 interrupt experiment, no longer needed), removed the per-touch rate-limited [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
2026-05-06 Round 72: touch-zones + sim-channel checkboxes (also rolls in the round-71 monitor cleanup that never shipped). Tap nav now only fires in the outer 30 % on each side (x<144 or x≥336 on a 480-wide scr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
2026-05-06 Round 72: touch-zones + sim-channel toggle buttons (also rolls in the round-71 monitor cleanup that never shipped). Tap nav now only fires in the outer 30 % on each side (x<144 or x≥336 on the 480-wi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
2026-05-08 Round 74: Main display flipped to white background + black lines (was black/white) per user spec, with a four-arc no-go zone across the bow — port red [270..340°], port black [340..360°], stbd black 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
2026-05-08 Round 75: Main page double-label fix + second adjustable variable (no-stop angle) + Settings page restructure. (1) Round-74 hide-by-colour-match trick (white text on white bg) wasn't fully suppressin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
2026-05-09 Round 77: three small follow-ups to the round-76 Main-display overhaul. (1) AWS readout added below BSPD inside the hull, using the same DEPTH-style subtitle/value/unit triple ('AWS' / value / 'kn') 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
2026-05-17 Round 80: close the BLE bridge end-to-end on the bench (in simulation) and ship steps 2 through 9 of the v1.5 wireless split. Sim PGNs now travel TX -> BLE GATT -> RX -> BoatState -> existing LVGL UI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
    [main.cpp]
2026-05-17 Round 80a: AMOLED ghost-pixel workaround on TX. lv_label_set_text() skips invalidation when text is unchanged, so static rows (VBUS: connected, Battery once steady, etc.) sit on the AMOLED long enoug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
    [main.cpp]
2026-05-18 Round 80b: LC76G I²C bus confirmed dead on the AMOLED-1.75-G variant. Quectel forum thread #27337 (LC76G stuck-state recovery via dummy 0x54/0x58 reads) was the right lead but didn't apply here: the 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
    [main.cpp]
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2026-05-25 Catch up firmware repo with rounds 78–85 (v1.5 → v1.6 step 4)
    Two weeks of architectural work that never landed in git. Summary of
    what's now committed (each "round" was its own session at the time):
    * Round 78 — PGN honeycomb on RX (19-tile fixed-slot rate display).
    * Rounds 80–82 — converter env added (Daisy AIS + WiFi peer);
    src_tx_wifi + waveshare_*_wifi envs; multicast virtual bus on
    239.255.78.85:60001; bench-stage TX-as-AP softAP.
    * Round 83 — runtime role election (priority backoff RX:200 >
    converter:150 > TX:100), polite handoff, PGN 65500 heartbeat.
    * Round 84 — pivot from multicast to unicast star + AP relay
    (ADR-0010); dual-AP detection (task #36); safety b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
    [main.cpp]
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2026-05-25 RX radar page + bus-controlled AIS sim with Furesø targets
    Settings: new sim.ais key (default on) wired through the shared
    SettingsStore — struct/NVS/exportJson/applyFromJson — so the AIS sim is
    toggleable from the iOS Settings tab like the other sim.* channels.
    Converter: simAisTick early-returns when sim.ais is off (reads the
    adopted AP snapshot via currentSettings()). Replaced the three Aarhus
    circle-drifters with six recreational craft on Furesøen next to Virum,
    each dead-reckoning along its COG so the map/radar projection arrows
    track real motion; one sits at anchor to exercise ais.hide_anchored.
    RX UI: new north-up Radar page (kNumPages 4->5, order Main/AIS/Radar/
    PGN/Comm) —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
    [main.cpp]
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2026-06-07 v2 reset: devices/+shared/ layout, salvage AIS decode, ais-radar skeleton builds
    Begins the ADR-0016 repo reset (ROADMAP step 0):
    - New layout: devices/ais-radar/ (its own PlatformIO project) + shared/
    (salvaged reusable code, wired via lib_extra_dirs).
    - Salvaged the AIVDM decode (ais_decoder, default_sentence_parser,
    strutils, AisTargetStore) from src_converter into shared/ais/ — moved
    with git, history preserved.
    - New shared/ais/AisTargetDecoder.h: a store-only decoder extending
    AIS::AisDecoder directly, with NO NMEA 2000 dependency (no bus to emit
    PGNs onto). Fixes a latent v1 bug — the old AisDecoderWithStore
    recorded SOG/COG/name/type but never lat/lon (recordLatLon w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
    [main.cpp]
2026-06-07 v2 reset: extract AMOLED display+LVGL bring-up to shared/display
    Salvages the SH8601/CO5300-over-QSPI + LVGL 8.3 bring-up from the v1 TX
    firmware (src_tx/main.cpp initDisplay/flushDisplayCb/initLvgl) into a
    clean shared/display/AmoledDisplay module — amoled::begin() brings up
    I2C, the AXP2101 PMIC, the AMOLED panel, and LVGL, leaving lv_scr_act()
    ready. App UI, WiFi, and BLE logic from the 1847-line v1 main are left
    behind.
    devices/ais-radar now brings up the screen and renders the AIS target
    count decoded from the test sentences — both salvaged subsystems
    (shared/ais + shared/display) working together. pio run -> SUCCESS
    (RAM 27.3%, Flash 8.4%). lv_conf.h copied into the device; LVGL +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
    [AmoledDisplay.cpp, main.cpp]
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2026-06-07 v2 reset: extract LC76G GPS (UART) + TCA9554 expander to shared/display
    Salvages the LC76G GNSS UART path and the NMEA GGA parser from
    src_tx/main.cpp into shared/display/Lc76gGps, plus the TCA9554 expander
    helper (shared/display/Tca9554) used for the GPS reset (and, later, the
    touch reset). The dead I2C path is dropped entirely — on this board
    variant the LC76G isn't on the ESP32 I2C bus; only the UART on GPIO17/18
    reaches it, gated by the unpopulated R15/R16 jumpers. poll() is silent
    until those are soldered, then GGA fixes light up with no code change.
    devices/ais-radar now brings up display + GPS + AIS and shows the target
    count and GPS status on screen. pio run -> SUCCESS; flashed +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
    [Lc76gGps.cpp, Tca9554.cpp, main.cpp]
2026-06-07 v2 reset: extract CST9217 touch to shared/display
    Salvages the CST9217 bring-up (TCA9554 EXIO6 reset + SensorLib
    TouchDrvCST92xx) and the getPointCount-gated read into
    shared/display/Touch. The v1 swipe-nav state machine is dropped — that
    was page navigation; the radar will build its own zoom/pan on readPoint().
    Device env gains lewisxhe/SensorLib + a copy of patch_sensorlib.py
    (pre-build, silences the getPoint(0) log spam). main shows tapped coords
    so a tap verifies touch. Hardware-verified: 'CST9217 up', chip 0x9217,
    466x466 — display + touch + GPS + AIS all live on the board.
    [Touch.cpp, main.cpp]
2026-06-07 v2 reset: finish step 0 — move BoatBle to shared/ble, delete v1 trees
    Completes the ADR-0016 repo reset:
    - BoatBle.h -> shared/ble/ (the GATT pattern to crib for the v2 BLE link).
    - Deleted src/ (RX firmware), src_tx/ (TX firmware), include/ (WiFi-bus
    headers), and the root platformio.ini. All recoverable at tag
    v1-wifi-bus-archive; the radar geometry + N2K encoders live there for
    reference when steps 3 / future N2K bridging need them.
    - CI (build.yml) now builds devices/ais-radar instead of the deleted
    v1 envs.
    The repo is now purely v2: devices/ (per-device PlatformIO projects) +
    shared/ (salvaged libs) + docs/ + ios/. devices/ais-radar builds clean
    after the deletions, confirmi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
    [main.cpp]
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2026-06-08 ais-radar step 2: read the Daisy on IO16 @ 38400, decode AIVDM
    The device firmware now opens Serial2 on IO16 at 38400 (the dAISy NMEA-HS
    default), assembles NMEA lines, and feeds them to the on-device
    AisTargetDecoder; the AMOLED shows AIS byte/line counts + GPS status.
    Hardware-verified end to end: the dAISy keep-alive heartbeat
    (!AIVDM,1,1,,A,?h3Owpi;EmdDD00,2*16) decodes clean (valid checksum) on
    the board. targets stays 0 until a position-type sentence or a real
    antenna arrives — the keep-alive is AIS type 15 (interrogation), not a
    vessel report.
    Note: an earlier debugging detour to 115200 was a red herring — a
    marginal connection (fixed by recabling) caused garbage at 38400; a
    che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
    [main.cpp]
2026-06-08 ais-radar: fix AMOLED 'italic' artifact (full-screen invalidate each tick)
    Same issue we hit on the v1 TX (round 80a): LVGL skips redrawing
    unchanged content, so static text sits on the AMOLED long enough for
    sub-pixel drift to read as slanted/'italic'. Force lv_obj_invalidate on
    the active screen every 500 ms refresh so the panel keeps repainting.
    The cause is screen refresh cadence, not font rendering or orientation.
    [main.cpp]
2026-06-08 ais-radar step 3: on-device LVGL radar + 10s target lifetime + test gen
    - Radar.{h,cpp}: north-up PPI on the AMOLED — own ship centred, AIS
    targets at range/bearing (haversine), 5-min COG projection sticks,
    MMSI labels, 3 range rings + N tick, auto-fit range, stale-contact
    dimming. Full canvas redraw each tick (also covers the italic fix).
    - main.cpp: replaces the text readout with the radar; own position is a
    fixed bench coord (55.76196, 12.62900) until the LC76G is soldered,
    else the GPS fix. Targets expire after 10 s via evictStale(10000).
    - AisTargetStore::evictStale now takes a stale-ms arg (default 5 min).
    - scripts/gen_ais_test.py: generates verified Type-18 AIVDM sentence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
    [main.cpp]
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2026-06-08 AIS-radar: threat-level background colouring (green/yellow/red)
    Device computes a worst-case threat across targets and tints the whole
    radar background: dark (no targets) -> green (safe) -> yellow (alert) ->
    red (danger).
    - Yellow: a target with SOG>15 kn within 5 km, OR moving within 200 m.
    - Red: CPA collision risk (closest approach <0.1 NM within 6 min). Uses
    own COG/SOG when available (the GPS feed, next) — own stationary at the
    bench for now, so red = a target whose track passes through own pos.
    radar::assessWorst exposed; the level is packed into BleOwnShip.flags
    (bits 1-2) so the iOS app shows the same colour without re-running the
    CPA math (it lacks own SOG). Radar elements re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
    [main.cpp]
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2026-06-08 AIS-radar: feed iPhone GPS to the device over BLE (own position + motion)
    New BLE write characteristic (a15a0004) + BleHostGps struct: the iOS app
    streams the phone's position/course/speed; the device uses it as own ship
    (priority: LC76G fix > phone GPS > bench coord). This gives real own
    position + motion before R15/R16 are soldered, and makes the collision
    (red) threat use the user's actual movement.
    - Firmware: Ble.cpp GPS write callback + ble::hostGps(); main.cpp
    ownShip() selects the source and feeds radar + threat + publish.
    - iOS: LocationPublisher (CoreLocation → packed BleHostGps → BLE write);
    BleCentral discovers the GPS char + writeHostGps(); app wires + starts
    it; NSLo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
    [main.cpp]
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2026-06-08 ais-radar: SD-card recon for C-MAP (finds exFAT mount blocker)
    Adds listSdCard() — a one-shot boot diagnostic that mounts the onboard
    microSD (SD_MMC 1-bit: CLK=2 CMD=1 DATA=3, from Waveshare pin_config) and
    lists root + cmap/ over serial.
    Finding: the stock Arduino-ESP32 SD_MMC **cannot mount the exFAT card**
    ('mount FAILED'). So the C-MAP overlay first needs one of: an exFAT-
    enabled FATFS build, the SdFat library, or reformatting the card to
    FAT32 — then we can read cmap/ and assess the (likely proprietary)
    C-MAP format. Recorded in ROADMAP.
    [main.cpp]
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2026-06-09 ais-radar: SD now mounts (FAT32) — charts are CM93 v2/v3
    listSdCard() now recurses 2 levels (skips macOS cruft). With the card
    reformatted FAT32 it mounts (60 GB) and the chart data is CM93:
    cm93_World2014/ -> numeric cell dirs (lat/lon-encoded) x A-G scale bands
    x .INF metadata. That's the OpenCPN-decodable CM93 vector format, not
    encrypted C-MAP — feasible to overlay, but a substantial vector
    decode+render job. Recorded in ROADMAP.
    [main.cpp]
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2026-06-09 Fix chart tile path (doubled SD mountpoint) + bench test target
    - ChartOverlay opened /sdcard/tiles/... but SD_MMC.open() takes a card-root
    path and adds the /sdcard mount itself -> it was looking for
    /sdcard/sdcard/tiles/... and always missing. Open /tiles/<cell>.c93t.
    This is why the range stayed at 1 NM (chart-on range floor never fired)
    and no overlay drew.
    - Move the chart status line onto the vertical axis (round display clips the
    corners, so the old bottom-left placement was off-glass).
    - Bench test target: a Class-B vessel ~3 NM NNE of own ship so the radar
    auto-fits to a real scale (and the chart shows at it) without live AIS.
    Goes to the AMOLED and, via ble::publish,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
    [main.cpp]
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2026-06-09 AMOLED: 3 vessel icons by type + ring filled flush to bezel
    - iconShip (cargo/tanker hull), circle (pleasure), triangle (sailing/other).
    - Threat ring now filled outward to the canvas edge (fillRing) so it's flush
    to the round bezel — lv_canvas_draw_arc was leaving a gap.
    - Demo targets re-enabled with distinct types (sailing/pleasure/tanker) so the
    icons + the upcoming iOS list have data; flip kInjectTestTarget for pure
    dAISy tests.
    [main.cpp]
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2026-06-09 Fixes: GPS stability, names + own SOG over BLE, depth render, slider
    - BleOwnShip +sog_kn10 (14 B), BleTarget +name[20] (38 B); MTU raised to 247
    (iOS negotiates ~185). publish() sends own SOG + target name.
    - Host-GPS freshness 5s -> 30s: own position no longer flip-flops to the bench
    coord between phone GPS updates.
    - Demo targets now FIXED absolute positions near the bench (don't follow own).
    - Depth fill: non-zero winding (was even-odd -> holes in self-intersecting CM93
    rings) and 3 ordered passes (water, then land, then coastline/TSS lines).
    iOS:
    - Parse own SOG + target names; CPA now folds in own motion (was stationary).
    - Radar + list show vessel names (fallback type+M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
    [main.cpp]
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2026-06-09 Add 'Use iPhone GPS' switch + steadier phone-GPS + clearer AIS list
    - BleSettings +phone_gps (6 B); DeviceSettings.phoneGps persists to NVS.
    ownShip() now prefers the phone GPS when the switch is on (even over the
    LC76G, in case the phone is more accurate); off = device GPS only.
    - iOS Settings: 'Use iPhone GPS' toggle (Position section).
    - LocationPublisher re-sends the last fix every 2 s so the device's host-GPS
    doesn't go stale when iOS throttles updates (stationary).
    - AIS list shows the full MMSI for unnamed targets (the dAISy '— 1' was
    MMSI 211000001 % 100000 = 1 + the em-dash type placeholder).
    Device pio + iOS xcodebuild green.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
    [main.cpp]
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2026-06-10 Road-trip fixes: continuous chart tiles, dAISy raw log + heartbeat
    - Chart no longer blanks at tile edges: ChartOverlay (device) + ChartStore
    (iOS) load the own cell PLUS any neighbour within ~0.6° of an edge (up to a
    2×2), so the chart stays continuous across the 4° CM93 boundaries.
    - dAISy diagnostics for the 'no targets' case:
    * device streams every raw dAISy NMEA line over a new BLE log characteristic
    (a15a0006) and sets an own-ship 'dAISy alive' flag (bit3).
    * iOS: new Log tab showing the raw stream (AIVDM lines highlighted green) +
    line/AIVDM counts; AIS heartbeat icon next to the BLE connection.
    This shows whether the receiver is emitting anything at all, unfilter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
    [main.cpp]
